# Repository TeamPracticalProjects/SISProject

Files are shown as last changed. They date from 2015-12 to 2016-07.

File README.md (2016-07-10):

# SISOverview
SIS stands for "Standalone Intelligent Sensor" system. The documents in this repository provide everything you need to make and deploy your own SIS. You'll find concept documents, a FAQ, the firmware for your Arduino-like particle.io processor, printed circuit board files, parts lists, links to sources for all the parts, detailed assembly instructions, source code to a control web page, and a complete users guide. At Team Practical Projects we always make a complete project! And we know this repo is complete because, unknown to us, someone in Europe made one!

We are looking for people who are interested in building and using the SIS.  We are also interested in ideas for expanding the current SIS with additional useful features and we are open to  ideas for additional applications of the base SIS technology (some ideas are in the Concept document). SIS is an open source project and we are interested in improvements that other developers might wish makethemselves and/or to collaborate with us on.

If you want to use this project, download the Master branch. That is the currently released and well tested code.

If you have code to contribute, then generate a pull request for the Development branch. We don't want to take in pulls for master branch unless it is some critical issue with the current release.

We are two hobbyists who work on the SIS in our spare time. You don't have to be a hardcore, gung-ho, work on it until you drop, kind of person; we certainly aren't. Collaboration could just mean that you'd like to have one of these to install and test somewhere. We are open to make changes to the code to fit your need, as long as you provide us feedback on how it works and ideas on how to improve it.

We're currently working on three big things:
* Low power custom sensors... This project includes Arduino code to make your own wireless sensor, but running an Arduino requires regular power. We're working on using the ATTiny platform in power-down mode so we (you) could make any kind of low power sensor you want!
* Graphical output in the client... Thanks to a contributor in the Netherlands we are experimenting with the Google graph "Timeline". It provides a strip chart view of the sensor log. This is more usable than the current text list. If you want to help with this, let us know and we'll share that branch.

Of course collaboration could also mean that you want to add functions to the core firmware or javascript web site. That would be cool too.

The documentation is the best place to learn about the project. We starting a [Wiki](https://github.com/TeamPracticalProjects/SISProject/wiki/Wiki-Home) with little tips for new developers.

Send us a message to join in the fun: SISProject@shrimpware.com

Read about the SIS at other places on the web:
* [Hackster.io](https://www.hackster.io/PracticalProjects/standalone-intelligent-sensor-system-cbdb44)
* [Instructables](http://www.instructables.com/id/Standalone-Intelligent-Sensor-System/)

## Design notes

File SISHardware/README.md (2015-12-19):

# SISHardware
This repository contains the Eagle files for the SIS Hub printed circuit board.
The files are provided in Eagle format (.sch and .pcb formats) as well as in pdf format
for those who do not have Eagle.

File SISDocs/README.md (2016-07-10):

# SISDocs
Documentation for the SIS Project.

This repository contains the manuals that describe:
- how to build the SIS Hub
- how to install the Firmware on the SIS Hub
- how to plan an SIS installation and how to actually perform the instalation process.
- how to use the SIS to monitor the activities of a person living alone using the web-based SIS Client app

Please note the document "Optimum Sensor Reception". This documents what we currently know about getting the best reception possible.

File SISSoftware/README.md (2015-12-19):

# SISSoftware.
This repository holds the firmware for the SIS Hub, the javascript based website that is the SIS Client app,
and the Arduino code to make an SIS compatible sensor.

If you want to use this project, download the Master branch. That is the currently released and well tested code.

If you have code to contribute, then generate a pull request for the Development branch.

The project documentation is in the SISProject/SISDocs repository.

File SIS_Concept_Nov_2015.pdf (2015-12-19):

# Standalone Intelligent Sensor (SIS)

## Concept Document

© Bob Glicksman and Jim Schrempp, revised November 2015
1. Product Concept.

The Standalone Intelligent Sensor (SIS) is an inexpensive system that processes information from a variety of passive wireless sensors to create a timestamped log containing meaningful information and inferences about a person’s in-home activities. The SIS log can be securely accessed over the Internet, providing caregivers and concerned relatives a picture of how competently an elderly person living alone is performing the routine activities of daily life.

The initial release of SIS uses wireless proximity infrared (PIR) motion sensors and wireless door separation sensors to log movements of a person around and in/out of their home. Judicious placement of the PIR sensors provides a compact picture of a person’s activities via the natural association of those activities with areas of the home; e.g. bedroom for sleeping and dressing, bathroom for personal hygiene, kitchen for food preparation and living room for relaxation and socialization.

The SIS consists of a number (up to 20) of inexpensive wireless sensors and a small hub device containing wireless receivers, an advanced microcontroller, and WiFi connectivity. The current release of SIS requires WiFi for connection to the Internet; however, a 3G wireless version is anticipated in the near future. SIS also contains client software that can communicate with the in-home hub over the Internet, via a free cloud service from particle.io. The client software is written in Javascript and can be hosted on any device that supports a Javascript enabled web browser (desktop, laptop, tablet, smart phone, etc.). Communication between the SIS hub, the cloud and a client is authenticated and encrypted to ensure privacy and security of the data.

SIS achieves low cost by performing all sensor data processing internally on the SIS hub’s advanced 32 bit microcontroller. Cloud processing of the sensor data is not required. A free cloud service is used to connect the SIS hub and authenticated clients via the Internet. An SIS hub can be built for around $50 in parts and the sensors cost between $3 (for a door separation sensor) and $8 (for a PIR sensor). Total system cost (assuming an existing WiFi access point in the home) will be between $100 and $200, depending upon the number and types of sensors required for a particular home environment. There are no monthly recurring charges, other than an assumed existing WiFi capability.

SIS supports a variety of low cost sensors that can be obtained from many sources including over the Internet from EBay and Amazon. SIS supports both wireless sensors operating at both 315 MHz and 433.92 MHz within the one system. Sensors are available to sense:
- Door/window opening.
- Motion (via PIR).

- Vibration.
- Water level.
- Smoke/fire
- Keyfob
- Arduino software has also been developed to transmit compatible sensor trip codes so that specialized sensors may easily be developed.

SIS is released under an “open source, non-commercial” license. The software, hardware designs, parts lists, instructions and manuals are provided free of charge to non-commercial users. SIS is not a product; the user must use the information provided to construct, install, configure, and test the SIS for their specific environment.

The software for the initial release of SIS will provide a reasonable picture of the daily in-home activities of a person that lives alone. It attempts to sense when more than one person is in the home and lock out logging of activities to prevent false positives. The data processing internal to SIS does not attempt to establish and report “normal” vs. “abnormal” activities of a person in the home. Rather, SIS logs compact information about a person’s movements around the home and leaves it up to the caregiver or relative to determine if the person’s activity patterns have changed. This, coupled with low hardware cost, is what makes SIS an inexpensive solution vis-a-vis more complex and expensive systems.

SIS draws only a few inferences from sensor data; specifically:
- When a person is home or not home.
- When a person is home but not moving at all.
- When multiple people are in the home.

Because all of the SIS design information is open source, SIS firmware and client software may be modified to address other applications in the future. The SIS may be thought of a general purpose platform for interfacing low cost wireless sensors with clients over the Internet.
2. Use Cases.

The initial release of SIS provides general information about the movement of a person inside of the home. Field testing has demonstrated that a limited number of types of sensors can provide a remote client user with sufficient information to determine when and what activities of daily living the person in the home being monitored is performing. A daily review of the logged data is sufficient to detect abnormal patterns; e.g. a person is not leaving the bedroom in the morning or a person is visiting the bathroom several times during the night. More advanced (and more expensive) in-home activity monitoring systems seek to answer additional questions, some of which are posited below. It should be possible to answer these questions with SIS by integrating additional sensors and developing special firmware to make inferences from the sensor data.

2.1. Aging In Place Use Cases.
2.1.1. “I am concerned that Grandpa is not eating.”

A caregiver or loved one is concerned that an elderly person is not eating regularly and needs to be moved to a facility where their dietary needs are met and monitored. The elderly person is pushing back, claiming that they are eating and are perfectly capable of living at home and of caring for themselves. A compromise position has the elderly person agreeing to SIS monitoring of their kitchen activities via proximity sensing and sensing of one or more food related activities:
- opening and closing the refrigerator door.
- running a microwave or toaster oven.
- running of the stovetop and/or oven.
- opening/closing silverware draw or flatware cabinet.
- running of the dishwasher.

The initial release of SIS logs movement into and out of the kitchen. It also supports the logging of data from separation sensors and specialized sensors; however, it does not draw inferences from these additional sensors. Being open source, SIS firmware can have additional inferences added to better support this use case.

2.1.2. “I called Mom when she should be home but the phone is not answered.”

The question here, of course, is whether Mom is in the house and unable to answer the phone (due to fall, stroke, or other serious problem) or whether she is just fine and decided to go out of the house or apartment, perhaps for socialization activities. The concern could be mitigated if the state of “in the house” and “out of the house” could be known. Without relying on the person wearing a certain commercial fob with Near Field Communication capabilities, the activities of “leaving the house” and “entering the house” could be timestamped, logged and accessed via the Internet. SIS can provide such information, particularly if the person lives alone. The initial release of SIS supports this use case, and more. An enhancement, however, might be to support user configuration of normal “out of the house” times and send the user an alert if the elderly person leaves the home at an unexpected time (which might be an indication of illness or wandering).

2.1.3. “Last year Dad had a urinary tract infection but did not tell anyone about it. Ultimately, he had to be hospitalized”.

There were indications of this infection, of course, but Dad ignored them. He woke up ten times that night to go to the toilet. However, he didn’t think anything of this and didn’t tell anyone about it. Now, family has confronted Dad with this problem, suggesting that it is an indication that he can no longer live alone at home. Dad denies this and, although prone to these infections, insists that he “knows better now” and promises to tell family the “next time”. Family members remain concerned and believe that the problem will recur, perhaps this time resulting in his death due to lack of timely treatment.

The initial release of SIS will support this use case by logging movement between the bedroom and bathroom. The initial release of SIS can also log trips of a water level sensor that is mounted inside the toilet tank that positively indicates when the toilet is flushed.

2.1.4. “I am concerned that Mom is staying in bed all day with the lights off and the drapes drawn. She denies the depression.”

The initial release of SIS will log movement into and out of the bedroom. Review of the log can determine if Mom is not getting out of bed (at all, or not when expected). Additional sensors and algorithms may be developed to add important information; e.g. is Mom in bed or moving about the bedroom? Is the bedroom lit or dark? Is the TV on or off? Etc. It may be possible to develop algorithms for SIS that use this additional sensor information to sense that Mom is having symptoms of depression and to send an alert to the caregiver or relative accordingly.

2.1.5. “Beloved Aunt Millie has emphysema and is not allowed to smoke. She lives alone and her loved ones are concerned that she continues to smoke and is likely to die if her smoking is not monitored.”

SIS can be fitted with a smoke detector sensor and will log instances of smoke detection along with movement around the house. An enhancement would be to proactively alert a family member if the sensor is triggered.

### 2.1.6. Uncle John has left the freezer door open several times. The

food has spoiled and then refrozen. This is a health danger.

An SIS-compatible temperature sensor may be developed to detect, log and alert a remote user in the event that the temperature inside the refrigerator gets too high, indicating that the food may spoil if the situation is not corrected promptly.

2.2. Home Monitoring Use Cases.
2.2.1. “I am getting forgetful and prone to leave the water running in the sink.”

SIS could use a compatible water level sensor to log instances of the sink filling up. A firmware enhancement to SIS could send an alert to a caregiver or family member in this event. A hardware and firmware enhancement could shut off the water supply before folding occurs, and or set off an audible alarm to the resident. An SIS compatible sensor could be developed to sense water flow. This sensor could be used, in conjunction with SIS’s current capability to determine where a person is in the home, to log instances where the water is running but the person has left the kitchen or bathroom. A firmware enhancement to SIS could send an alert to a family member or caregiver, in addition to logging these instances of forgetfulness.

2.2.2. “Rainwater collects under my house. I have an automatic sump pump to pump the water out, but the pump sometimes fails and I am concerned about the foundation being flooded in a rainstorm.”

An SIS compatible water level sensor and/or a moisture sensor could be used to determine if water is building up under the house. If it is, then the sump pump is not operating properly and the user can be alerted through the SIS Hub.

2.3. Other Use Cases.
2.3.1. “I have a greenhouse in which I grow valuable plants. I need to know when the temperature or humidity gets out of a predetermined range so that I can intervene to save the plants from dying.”
Assuming that the greenhouse has AC power or is within 100 feet of a location where the SIS Hub can be installed, an SIS can be fitted with a temperature/humidity sensor and be programmed to log temperature and humidity and to alert the user whenever either measurement goes out of prespecified limits.
3. SIS Technical Description.

A complete technical description of SIS can be found in the “SIS Theory of Operation and Installation Manual”, which can be found at:

https://github.com/SISProject/SISDocs/blob/master/SIS_Theory_of_Operation_and_Installation. pdf (https://github.com/SISProject/SISDocs/blob/master/SIS_Theory_of_Operation_and_Installation.pdf)

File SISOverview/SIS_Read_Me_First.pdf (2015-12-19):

# Standalone Intelligent Sensor (SIS)

## Project and Document Overview

## Read Me First!

© Bob Glicksman and Jim Schrempp, December 2015

## 1. What’s This All About?

The Standalone Intelligent Sensor (SIS) is an inexpensive build-it-yourself system that processes information from a variety of passive wireless sensors to create a timestamped log containing meaningful information and inferences about a person’s in-home activities. The SIS log can be securely accessed over the Internet, providing caregivers and concerned relatives a picture of how competently an elderly person living alone is performing the routine activities of daily life.

The initial release of SIS uses wireless proximity infrared (PIR) motion sensors and wireless door separation sensors to log movements of a person around and in/out of their home. Judicious placement of the PIR sensors provides a compact picture of a person’s activities via the natural association of those activities with areas of the home; e.g. bedroom for sleeping and dressing, bathroom for personal hygiene, kitchen for food preparation and living room for relaxation and socialization.

The SIS consists of up to 20 inexpensive wireless sensors and a small hub device containing wireless receivers, an advanced microcontroller, and WiFi connectivity. The current release of SIS requires WiFi for connection to the Internet; however, a 3G wireless version is anticipated in the near future. SIS also contains client software that can communicate with the in-home hub over the Internet, via a free cloud service from particle.io. The client software is written in Javascript and can be hosted on any device that supports a Javascript enabled web browser (desktop, laptop, tablet, smart phone, etc.). Communication between the SIS Hub, the cloud and a client is authenticated and encrypted to ensure privacy and security of the data.

SIS achieves low cost by performing all sensor data processing internally on the SIS Hub’s advanced 32 bit microcontroller. Cloud processing of the sensor data is not required. A free cloud service is used to connect the SIS Hub and authenticate clients via the Internet. An SIS Hub can be built for around $50 in parts and the sensors cost between $3 (for a door separation sensor) and $8 (for a PIR sensor). Total system cost (assuming an existing WiFi access point in the home) will be between $100 and $200, depending upon the number and types of sensors required for a particular home environment. There are no monthly recurring charges, other than an assumed existing WiFi capability.

SIS is not a product; the user must use the information provided to construct, install, configure, and test the SIS for their specific environment.

2. Open Source.

SIS is released under an “open source, non-commercial” license (Creative Commons). The software, hardware designs, parts lists, instructions and manuals are provided free of charge to non-commercial users. We encourage people to use the SIS as it is documented herein and to provide us with feedback about your results, difficulties and ideas for improvement. As an open source project, we encourage people to make changes and improvements to the SIS design, subject to the “Terms_Of_Use_License_and_ Disclaimer” document:

https://github.com/SISProject/SISDocs/blob/master/Terms_of_Use_License_and_Disclaimer.pdf

We are also open to people using SIS technology in a commercial business. If you are interested in this, please contact us to discuss the terms of an appropriate commercial license:

SISProject@shrimpware.com

3. Documentation Tree.

We have attempted to provide users with a complete set of documentation that describes what SIS is, how to build your own SIS, how to plan and install and SIS, and how to use the SIS Client app to manage and query an SIS. Since SIS is an open source project, we have also provided complete source code and hardware (Eagle) files. Users may use this documentation as the starting point for making modifications to and improvements on the SIS technology that we have provided.

All SIS documentation and files are released on GitHub, under:

https://github.com/SISProject

The figure below is the documentation tree for all of the files in the SIS release. All documents (other than source code and Eagle CAD files) are in .pdf format.

We have arranged the SIS documentation into 4 repositories under the SIS project:

- SIS Overview: this repository contains documents that provide the reader with an overview of the SIS project. This document is located in this repository, as is a Concept document and a Frequently Asked Questions (FAQ) document. These documents are intended to help an interest user make a determination about building and installing an SIS to meet their individual needs.
- SIS Software: this repository contains the source code for all of the SIS software. The “website” subdirectory contains files for the SIS Client app, which is a Javascript enabled website. The “Firmware” repository contains the source code for the SIS Hub, which receives, decodes and processes data from all SIS sensors. The “Arduino Transmitter Software” repository contains Arduino source code for making an SIS compatible transmitter using an Arduino Uno and a cheap 315MHz or 433MHz transmitter module. Users can use this software to design their own, SIS compatible, wireless sensors¹

1
The Arduino Transmitter software does not contain code for low power, battery operation of an Arduino.

- SIS Hardware: this repository contains the Eagle CAD files for the SIS Hub printed circuit board (.sch and .brd files). .pdf versions of these files are also provided for those users who wish to view this design information but do have the Eagle CAD software.
- SIS Docs: this repository contains all of the documents necessary to purchase parts, assemble, install, and use an SIS for the intended application of monitoring the activities of a person living alone.

Note that any and all use of this documentation is subject to the “Terms of use, License and Disclaimer” document that you can find in the SIS Docs repository.

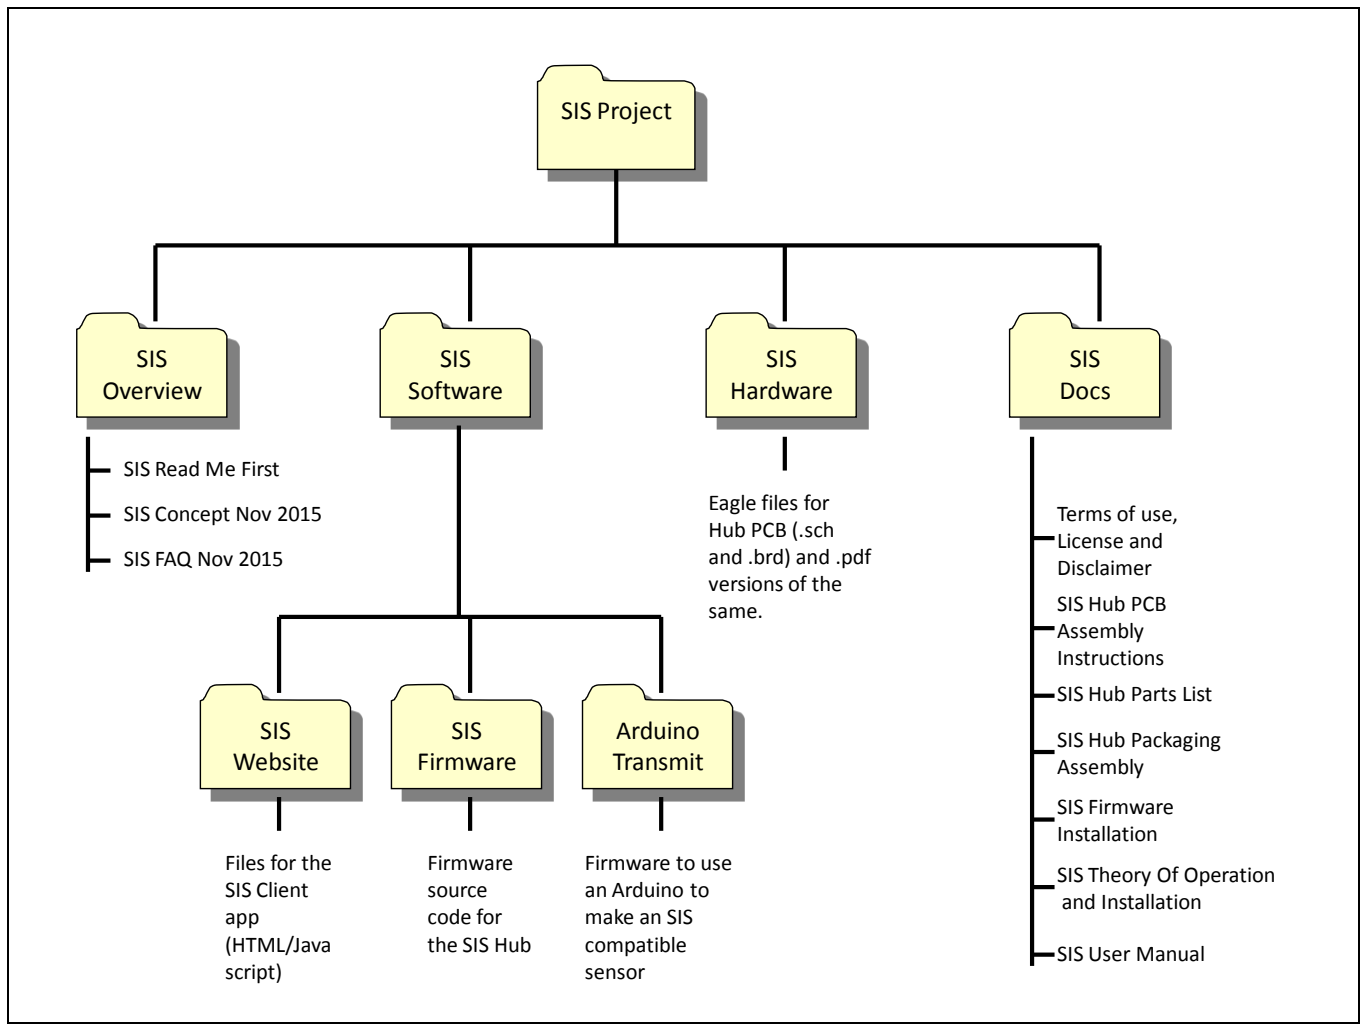
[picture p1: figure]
SIS Project; SIS Overview; SIS Software; SIS Hardware; SIS Docs; SIS Website; SIS Firmware; Arduino Transmit; Files for the SIS Client app (HTML/Java script); Firmware source code for the SIS Hub; Firmware to use an Arduino to make an SIS compatible sensor; Eagle files for Hub PCB (.sch and .brd) and .pdf versions of the same.; SIS Read Me First; SIS Concept Nov 2015; SIS FAQ Nov 2015; SIS Theory Of Operation and Installation; SIS Hub PCB Assembly Instructions; SIS Hub Parts List; SIS Hub Packaging Assembly; SIS Firmware Installation; SIS User Manual; Terms of use, License and Disclaimer

SIS Documentation Tree.

You can access and view all of these documents directly on the website:

https://github.com/SISProject

You can also click on whichever of the repositories you are interested in and click the
“Download ZIP” button on GitHub to download a zip archive of all of the files in that repository to your computer.
4. Further Information.

Complete information about SIS can be found in:

https://github.com/SISProject

We have tried to document SIS well enough for a novice, non-technical user to be able to build, install and use the SIS for their own purposes. We are not a commercial organization and we cannot commit to providing individual technical support. However, we are interested in people using and even improving SIS and we welcome you to ask questions, provide us with feedback, or suggest improvements via e-mail at:

SISProject@shrimpware.com

We hope that you enjoy SIS.

Sincerely,

Jim Schrempp and Bob Glicksman, developers of SIS

December 2015

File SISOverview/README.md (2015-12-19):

# SISOverview.
This repository contains overview documents that describe the SIS project.  SIS stands for 
"Standalone Intelligent Sensor" system. The documents in this repository explain the SIS concept 
and provide the answers to Frequently Asked Questions (FAQ).

We are looking for people who are interested in building and using the SIS as we have designed it.  We are
also interested in ideas for expanding the current SIS with additional useful features and we are open to 
ideas for additional applications of the base SIS technology (some ideas are in the Concept document). 
SIS is an open source project and we are interested in improvements that other developers might wish make 
themselves and/or to collaborate with us on.

We are two hobbyists who work on the SIS in our spare time. You don't have to be a hardcore, gung-ho, work 
on it until you drop, kind of person; we certainly aren't. Collaboration could just mean that you'd like 
to have one of these to install and test somewhere. We are open to make changes to the code to fit your need, 
as long as you provide us feedback on how it works and ideas on how to improve it.

Of course collaboration could also mean that you want to add functions to the core firmware or javascript web site. 
That would be cool too.

Send us a message to join in the fun: SISProject@shrimpware.com

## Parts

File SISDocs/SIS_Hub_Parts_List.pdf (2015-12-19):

REQUIRED PARTS FOR PCB ASSEMBLY
Item # | Qty | Vendor | Vendor Part # | Description | Link | Notes
1 | 1 OSHPark | SIS Hub PCB | SIS Hub Printed Circuit Board | https://oshpark.com/shared_projects/ptHf88wY Custom PCB - order from OSHPark or use the Eagle files to order
from another vendor.
2 | 1 Particle | Photon | Particle Photon WiFi
| | | | Microcontroller with
| | | | breadboard headers | https://store.particle.io/?product=particle-
photon (https://store.particle.io/?product=particle-photon)
| | | | | | The Particle Electron may be supported in the future. The PC board
| | | | | | has extension mounting holes to accommodate the larger Electron.
3 | 1 Jameco | AT24C256PC | 24C256; 32 KB I2C EEPROM | http://www.jameco.com/webapp/wcs/stores/ser
| | | | | vlet/Product_10001_10001_200580_-1 (http://www.jameco.com/webapp/wcs/stores/servlet/Product_10001_10001_200580_-1)
4 | 1 E-Bay | NA | 315 MHz OOK Receiver | http://www.ebay.com/itm/315MHz-433MHz-
| | | | | Wireless-Super-Heterodyne-Remote-RX-Receiver-
Module-107dBm-
| | | | | /181711941472?var=&hash=item2a4ee02f60 (http://www.ebay.com/itm/315MHz-433MHz-Wireless-Super-Heterodyne-Remote-RX-Receiver-Module-107dBm-/181711941472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) | Select 315 Mhz from dropdown list. The same part is available from
| | | | | | many Asian vendors on E-Bay and Amazon.
5 | 1 E-Bay | NA | 433 MHz OOK Receiver | http://www.ebay.com/itm/315MHz-433MHz- Wireless-Super-Heterodyne-Remote-RX-Receiver- Module-107dBm- /181711941472?var=&hash=item2a4ee02f60 (http://www.ebay.com/itm/315MHz-433MHz-Wireless-Super-Heterodyne-Remote-RX-Receiver-Module-107dBm-/181711941472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)

Select 433 MHz from dropdown list. The same part is available from many Asian vendors on E-Bay and Amazon.

6 | 10 Jameco | CF1/4W472JRC (http://www.jameco.com/webapp/wcs/stores/servlet/Product_10001_10001_691024_-1) | resistor - 4.7Kohm, 1/4 watt axial lead (minimum qty = 10)

http://www.jameco.com/webapp/wcs/stores/servlet/Product_10001_10001_691024_-1 (http://www.jameco.com/webapp/wcs/stores/servlet/Product_10001_10001_691024_-1)

Need 2 resistors

7 | 10 Jameco | SR205E104MAA-VP (http://www.jameco.com/webapp/wcs/stores/servlet/Product_10001_10001_544868_-1) | 0.1 uf Capacitor, 50 volt
| | | (minimum qty = 10) | http://www.jameco.com/webapp/wcs/stores/ser
| | | | vlet/Product_10001_10001_544868_-1 (http://www.jameco.com/webapp/wcs/stores/servlet/Product_10001_10001_544868_-1)

need 2 capacitors

8 | 10 Jameco | 100UF/16V 6X5 | 100 uF Capacitor, electrolytic | http://www.jameco.com/webapp/wcs/stores/ser
| | | | vlet/Product_10001_10001_94289_-1 (http://www.jameco.com/webapp/wcs/stores/servlet/Product_10001_10001_94289_-1)

need 1 capacitor

9 | 1 Jameco | USB-B-S-RA-WT | USB connector, B female | http://www.jameco.com/webapp/wcs/stores/ser
| | | | vlet/Product_10001_10001_230958_-1 (http://www.jameco.com/webapp/wcs/stores/servlet/Product_10001_10001_230958_-1)
10 | 1 Adafruit | 907 | Panel Mount USB cable, B male
| | | to B female | http://www.adafruit.com/products/907
11 | 1 Adafruit | 266 | 40 conductor female-female
| | | jumper wires, separable.
http://www.adafruit.com/products/266 | Required only if the receivers are not mounted to the PC board.
These jumers are used to connect pin headers soldered to the board in the receiver positions to the pins on the remotely mounted receivers.
12 | 1 Jameco | 7000-1X40SG-R (http://www.jameco.com/webapp/wcs/stores/servlet/Product_10001_10001_160882_-1) | Breakaway headers, straight,
| | | male | http://www.jameco.com/webapp/wcs/stores/ser
| | | | vlet/Product_10001_10001_160882_-1 (http://www.jameco.com/webapp/wcs/stores/servlet/Product_10001_10001_160882_-1)

Required only if the receivers are mounted remotely from the PC board. May also be used for POWER and EXPANSION connections to the PC board.
13 | 2 Digi-Key | S7016-ND (http://www.jameco.com/webapp/wcs/stores/servlet/Product_10001_10001_175920_-1) | 18 Pin female header | http://www.digikey.com/product-
| | | | search/en?keywords=S7016-ND (http://www.digikey.com/product-search/en?keywords=S7016-ND)

18 Pin headers will accommodate both Photon and Electron. 12 pin female headers may be used if only Photon support is needed.

14 | 1 Jameco | 6100-8-R | 8 pin DIP socket | http://www.jameco.com/webapp/wcs/stores/ser
| | | | vlet/Product_10001_10001_51626_-1 (http://www.jameco.com/webapp/wcs/stores/servlet/Product_10001_10001_51626_-1)

Alternative is to solder the Photon directly to the PC board, or to use 0.1" spaced female pin headers.

| | | | OPTIONAL PARTS FOR BOX MOUNTING AND
| | | | POWERING
1 | 1 Staples or on-
| line from Really
| Useful Boxes | in-store only | enclosure; 0.55 liter (1-7/16"H
| | | x 4"W x 8-1/2"L) | http://www.reallyusefulproducts.co.uk/usa/html/
| | | | onlineshop/rub/b00_55litre.php (http://www.reallyusefulproducts.co.uk/usa/html/onlineshop/rub/b00_55litre.php)

A smaller enclosure may be used if receivers are mounted to PC Bord directly vs taped to the sides of the enclosure. However, range of reception may sugger if the receivers are not at least 4" apart (and apart from the Photon WiFi chip). Boxes are available is various colors.
2 | 4 jameco | 2104-632-AL-7 (https://www.jameco.com/webapp/wcs/stores/servlet/Product_10001_10001_77543_-1) | standoff, female-female, 1/2",
| | | 6-32 threaded | https://www.jameco.com/webapp/wcs/stores/se
| | | | rvlet/ProductDisplay?storeId=10001&langId=-
| | | | 1&catalogId=10001&pa=77543&productId=7754
| | | | 3 (https://www.jameco.com/webapp/wcs/stores/servlet/ProductDisplay?productId=77543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)

Use as required to mount PC board into the enclosure. Board will accommodate 4 standoffs. See below for Nylon standoffs if desired.

3 | 10 jameco | H554-ND | Screw, 6-32x1/4", pan head, phillips
https://www.jameco.com/webapp/wcs/stores/servlet/ProductDisplay?productId=20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 94418 (https://www.jameco.com/webapp/wcs/stores/servlet/ProductDisplay?productId=2094418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)

Use as required to mount PC board into the enclosure. Board will accommodate 4 screws (board to standoff) + 4 screws (standoff to enclosure). See below for Nylon screws, if desired.

4 | 4 Digi-Key | 36-1903C-ND | standoff, female-female, 1/2", 6-32 threaded
http://www.digikey.com/productsearch/en?KeyWords=36-1903C-ND&WT.z_header=search_go

Nylon alternative to metals standoffs, if desired.

5 | 100 Digi-Key | H554-ND | Screw, 6-32x1/4", pan head, phillips
http://www.digikey.com/productsearch/en/hardware-fasteners-accessories/screwsbolts/2097339?k=H554-ND

Nylon alternative to metal screws, if desired. Minimum order is 100 screws (need 8).

6 | 10 Jameco | 0505HC-101S-R (http://www.jameco.com/webapp/wcs/stores/servlet/Product_10001_10001_182942_-1) | Cable tie mount, nylon, 3/4" (minimum qty = 10) | http://www.jameco.com/webapp/wcs/stores/ser vlet/Product_10001_10001_182942_-1 (http://www.jameco.com/webapp/wcs/stores/servlet/Product_10001_10001_182942_-1)

Use as required for neatness. Should only require 4 or so tie mounts

7 | 100 Jameco | CV-075-R (http://www.jameco.com/webapp/wcs/stores/servlet/Product_10001_10001_70561_-1) | Cable tie, nylon, 3" (minimum qty = 100) | http://www.jameco.com/webapp/wcs/stores/ser vlet/Product_10001_10001_70561_-1 (http://www.jameco.com/webapp/wcs/stores/servlet/Product_10001_10001_70561_-1)

Use as required for neatness. Should only require 4 or so ties

8 | 1 Office max | 912408 | Scotch Outdoor Mounting Tape
- Double Sided (one roll)
| | | | http://www.officedepot.com/a/products/745021 /Scotch-Permanent-Heavy-Duty-Outdoor- Mounting/ (http://www.officedepot.com/a/products/745021/Scotch-Permanent-Heavy-Duty-Outdoor-Mounting/)

Use as required to affix receiver modules to the enclosure. Not required if receivers are mounted on the PC Board.

9 | 1 Jameco | 10U2-02206-BK | USB Cable; A male to B male. | http://www.jameco.com/webapp/wcs/stores/ser vlet/Product_10001_10001_222010_-1 (http://www.jameco.com/webapp/wcs/stores/servlet/Product_10001_10001_222010_-1)

Optional - needed to bring power to the SIS Hub

10 | 1 Jameco | GS05U-USB | USB Power supply; 1Amp | http://www.jameco.com/webapp/wcs/stores/ser vlet/Product_10001_10001_2155823_-1 (http://www.jameco.com/webapp/wcs/stores/servlet/Product_10001_10001_2155823_-1)

Optional - needed to bring power to the SIS Hub. Any USB power supply, 5 volts at 500 ma or more will work, as will USB power from

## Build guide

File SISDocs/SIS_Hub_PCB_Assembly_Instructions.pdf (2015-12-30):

Page 1 of 13 | Copyright © 2015. Bob Glicksman and Jim Schrempp. All rights reserved.

## INSTRUCTIONS

## For Assembly of the SIS Hub Printed Circuit Board (PCB)

Bob Glicksman, Jim Schrempp Date: 12/30/2015

1) INTRODUCTION.

The SIS hub contains a printed circuit board (PCB) that must be assembled before the Hub can be powered and used. This assembly will take about one hour. The parts list for the printed circuit board can be found in Appendix A of this document and at:

https://github.com/TeamPracticalProjects/SISProject/blob/master/SISDocs/SIS_Hub_Parts_L ist.pdf (https://github.com/TeamPracticalProjects/SISProject/blob/master/SISDocs/SIS_Hub_Parts_List.pdf)

The SIS Hub is based on the Particle “Photon” module (see: https://www.particle.io/). The SIS Hub printed circuit board has been designed to accept the Particle “Electron” as well¹
The parts in the section of the Parts List labeled “Required Parts for PCB Assembly” must be purchased and available before the board can be assembled per these instructions. The parts in the section of the Parts List labeled “Optional Parts for Box Mounting and Powering” are not covered in these instructions. A separate instruction is provided for the recommended (but not mandatory) assembly of the completed PCB into a rugged plastic enclosure. See:

https://github.com/TeamPracticalProjects/SISProject/blob/master/SISDocs/SIS_Hub_Packaging_Assembly_Instructions.pdf (https://github.com/TeamPracticalProjects/SISProject/blob/master/SISDocs/SIS_Hub_Packaging_Assembly_Instructions.pdf)

2) TOOLS AND SUPPLIES.

Before beginning assembly of the shield board, the following tools and supplies should be at hand:

1 The Electron is not available at the time of this publication. The PCB design is based on preliminary specifications from Particle and has not been tested with an Electron. The PCB will also accept a Particle “Core” module; however, the SIS firmware no longer supports the Core.

NOTICE: Use of this document is subject to the terms of use described in the

document “Terms_of_Use_License_and_Disclaimer” that is included in this release package. This document can also be found at:

https://github.com/TeamPracticalProjects/SISProject/blob/master/SISDocs/Terms_of_Use_License_and_Disclaimer.pdf (https://github.com/TeamPracticalProjects/SISProject/blob/master/SISDocs/Terms_of_Use_License_and_Disclaimer.pdf)

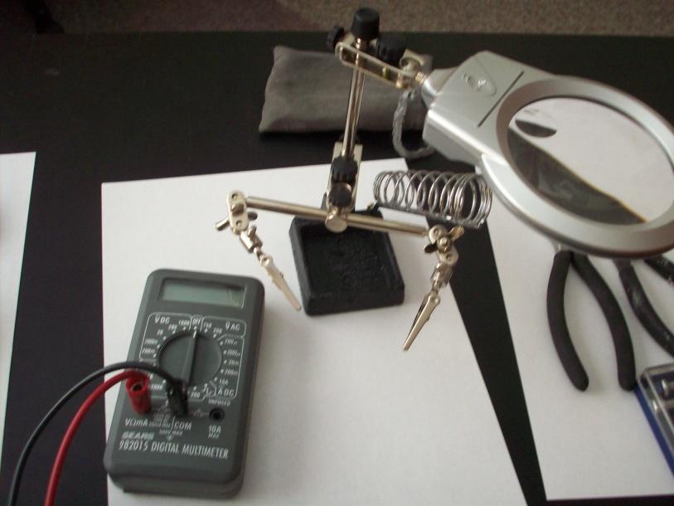
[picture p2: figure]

Page 2 of 13 | Copyright © 2015. Bob Glicksman and
a) Tools:
i) Soldering Iron
ii) Needle Nose Pliers
iii) Diagonal Cutter
iv) Wire stripper
v) Philips head screwdriver
b) Supplies:
i) Electrical solder
ii) Electrical tape
iii) Solder wick or solder remover iv) SIS hub parts kit (see parts list)
c) Optional (see photo 1, below):
i) Soldering iron stand
ii) PC board adjustable soldering stand iii) Magnifier
iv) Multi-meter

Photo 1. PC Board Adjustable Soldering Stand and Multimeter.

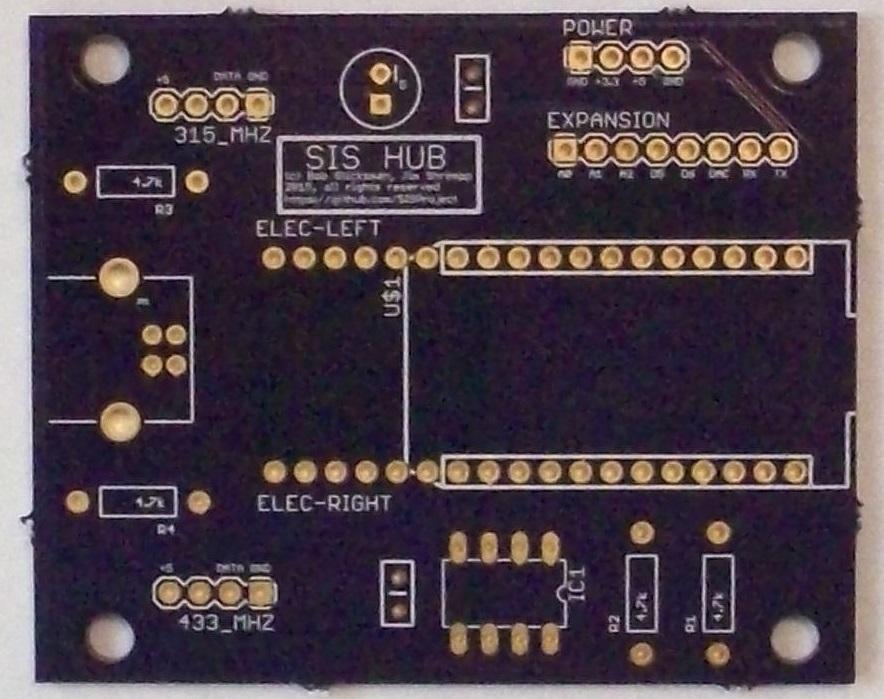
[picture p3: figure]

Page 3 of 13 | Copyright © 2015. Bob Glicksman and
3) ASSEMBLY INSTRUCTIONS.
a) Soldering. Assembly of the SIS Hub PCB requires that you have knowledge of skill of electronic soldering. A good tutorial on this subject can be found at:

https://learn.sparkfun.com/tutorials/how-to-solder---through-hole-soldering

b) General instructions: Before beginning assembly, please read through and understand these general instructions:
i) All parts are mounted on the top side of the board. The top side of the board is the side with the silk screen printing on it – see photos 2 and 3, below.

Photo 2. Top Side of Blank SIS Hub PCB. Note that the “front side” is to the right.

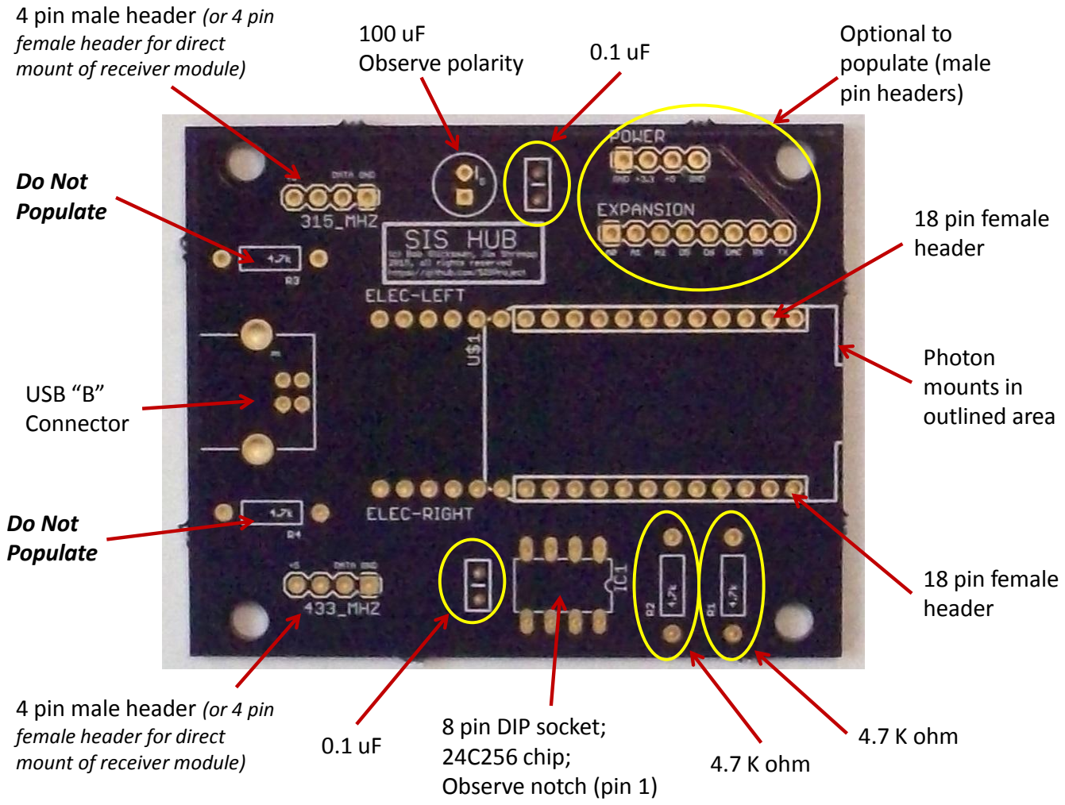
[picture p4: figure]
Optional to populate (male pin headers); 100 uF Observe polarity; 18 pin female header; Photon mounts in outlined area; 4.7 K ohm; 8 pin DIP socket; 24C256 chip; Observe notch (pin 1); Do Not Populate; USB “B” Connector; 4 pin male header (or 4 pin female header for direct mount of receiver module)

Page 4 of 13 | Copyright © 2015. Bob Glicksman and

Photo 3. SIS Hub PCB with major parts identified.

ii) All parts are soldered on the bottom side of the board only.

iii) The following parts have rigid pins and do not grip the board to hold the part in place when the board is inverted to solder the pins on the bottom. It is recommended to place the part on the top of the board, align the part as necessary, and apply electrical tape to hold the part in place for soldering. As soon as the board is inverted for soldering on the bottom side, solder the two pins at opposite ends (diagonally, in the case of the DIP socket) first to hold the part rigidly. Then solder the remaining pins to the board.

(1) 4 pin male headers. Care must be taken to keep these parts in vertical alignment as they tend to tilt sideways because they are loose in the holes in the board. Place these parts into the holes so that the short pin ends protrude through to the bottom of the PC board. Align each connector vertically and use electrical tape to

Page 5 of 13 | Copyright © 2015. Bob Glicksman and

hold it firmly into the holes, with the plastic center pieces firmly seated into the top side of the PC board and the connector straight up and down and not slanted sideways.

(2) Female headers for Photon/Electron Module. The headers require extreme care to ensure that the Photon/Electron module fits properly in the headers after they are soldered to the board. See instructions below for the recommended procedure.
(3) DIP socket. The DIP socket is easier to solder since it has two rows of pins that will prevent it from tilting. However, it should be taped or otherwise affixed to the top side of the PC board so that it stays in place when the board is inverted for soldering.

iv) The USB “B” connector has mounting tabs that are bowed outward to snap into a PC board. Once inserted into the PC board properly, the tabs will hold the connector in place when the board is inverted for soldering. See the assembly instruction details for this step in the SIS Hub PCB assembly for further details.

c) Inspect the blank PC board for damage and deburr edges.
i) File down any burs on the board edges to avoid cuts and scrapes

ii) Visually inspect the board for any damage or defects, such as:

(1) Breaks in conformal coating, except for solder pads and vias.
(2) Ensure that holes are drilled in the center of each component solder pad.

iii) Place a multimeter in resistance measurement mode and check that there is an open circuit between the “+5”, “+3.3” and the two “GND” pads on the “POWER” pads at the top of the board. Refer to photos 2 and 3, above, for details. If there is not an open circuit between any of these contacts on a bare PC board, then the board has a power short and should not be used.

d) Align and solder two 18 pin female headers for the Photon or Electron.
i) NOTE: The PCB has been designed to accept two 18 pin female headers for mounting an Electron. These headers can also be used with the smaller (24 pin) Photon or Core modules. If support for the Electron is not required, smaller 12 pin female headers may be used (but the 18 pin headers will support both the Photon and the Electron modules). If 12 pin headers are used, they must be mounted in the 12 pins closest to the front of the PCB, i.e. within the silkscreen outline shown in photo
3. Follow the same instructions as for 18 pin headers, below.

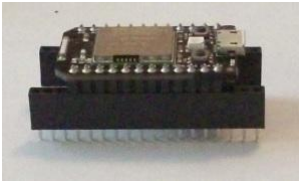
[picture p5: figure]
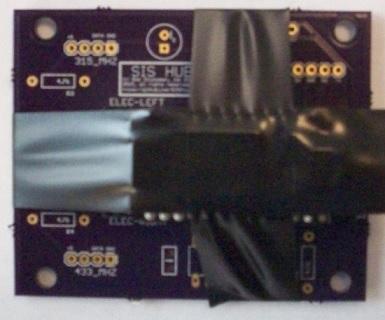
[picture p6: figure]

Page 6 of 13 | Copyright © 2015. Bob Glicksman and

ii) Place a Photon or Electron (or Core) into the 18 pin female headers, as shown in photo 4, below. If using a Photon or Core (24 pin devices), align the device in the middle of the header, as shown in the photo.

Photo 4. Female header alignment using a Photon, Electron or Core.

iii) Place the female headers into the PCB and secure the assembly firmly using electrical tape. See photo 5.

Photo 5. Securing the female headers into the PCB.

iv) Solder the end two pins at each end of each of the female headers, and shown in photo 6, below. Then, remove the electrical tape and unplug the Photon, Electron or Core device from the headers and solder the rest of the female header pins to the

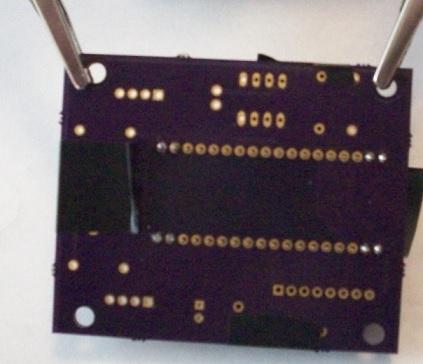
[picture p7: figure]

Page 7 of 13 | Copyright © 2015. Bob Glicksman and

PCB. Carefully inspect the solder joints to make sure that there are no cold joints and no bridging of solder between the pins.

Photo 6. Soldering corner pins to the PCB.

e) Solder 0.1” male pin headers to the PCB.
i) NOTE: the SIS hub PCB accepts two, 4 pin male headers for cabling the RF receiver modules to the PCB. Alternatively, 4 pin female headers may be soldered to the PCB and the receiver modules may be plugged directly into the board via these female headers. This eliminates the need to mount the RF receiver modules externally from the PCB, however testing has shown that receiver range may be degraded if the RF receiver modules are mounted closer than 4” from each other and from the chip antenna on the Photon module.

ii) Break off two, 4 pin segments from a long, 0.1” spaced male pin header.

iii) Place one 4 pin male header into the holes on the PCB marked “433 MHz”. The long pins and plastic body go on the top of the PCB.

iv) Use electrical tape to secure the 4 pin header to the PCB. Make sure that the header pins are vertical.

v) Invert the board and solder the two end pins to the PCB, taking care not to move the header connector out of the position that it was taped into. Then, solder the two

Page 8 of 13 | Copyright © 2015. Bob Glicksman and

middle pins. Carefully inspect that there are no cold solder joints nor bridged solder joints. Remove the electrical tape.

vi) Repeat this procedure for the “315 MHz” header.

vii)NOTE: There is a set of 4 holes marked “POWER” and 8 holes marked “EXPANSION” at the top of the PCB (photo 3). These are used only for expansion of the I/O capabilities of the PCB. They are normally left unoccupied; however, you may optionally break off male pin headers and solder them to the PCB using the same procedure as above.

f) Solder the USB “B” connector to the PCB.
i) Insert the USB “B” connector into the PCB, with the connector end facing the rear of the board. There are two large holes that mate with tabs on the connector. The connector will snap into the board and the tabs will hold it in place while soldering.

ii) Invert the PCB and solder the tabs and the 4 connector pins to the board. As always, inspect that there are no cold solder joints nor bridged pins.

iii) Put a blob of solder between the tabs and the large holes to give a bit more mechanical strength to the USB connector mounting.

g) Solder the 8 pin DIP socket to the PCB.
i) Insert the DIP socket into the top side of the PCB. Make sure that the notched end of the socket faces the front of the board (side opposite to the USB connector).

ii) Use electrical tape to hold the socket firmly onto the PCB.

iii) Invert the board and solder two opposing corner pins to the PCB, taking care not to move the DIP connector out of the position that it was taped into. Then, solder the remaining pins. Remove the electrical tape and carefully inspect that there are no cold solder joints nor bridged solder joints.

h) Solder the remaining components to the PCB.
i) NOTE: all remaining components have two long leads that can be bent over to hold the component into position when soldering. Bend the leads to insert the component into the top side of the PCB, as needed. Then, bend over the leads on the bottom side of the PCB so that the component stays in place and solder the two ends to the board. Inspect the solder joints. Then, using diagonal cutters, clip of the excess leads from the bottom side of the PCB.

Page 9 of 13 | Copyright © 2015. Bob Glicksman and

ii) NOTE on the 100 uF electrolytic capacitor: This device is polarized. The positive (+) side has the longer lead. The negative (-) side has a silver stripe near it on the capacitor body. The positive (+) side goes into the square hole in the PCB and the negative (-) side goes into the round hole in the PCB (also marked with a “-“ symbol). Make sure to observe correct polarity when soldering the capacitor to the PCB.

iii) The two 0.1 uF capacitors are non-polarized. It does not matter which lead goes into which hole on the board.

iv) Two 4.7Kohn resistors are soldered into the positions labeled “R1” and “R2” on the PCB. These can be found near the front of the board, near the 8 pin DIP.

v) NOTE: there are two more positions marked “R3” and “R4”. These are located near the rear of the PCB, near the 315 MHz and 433 MHz connectors. DO NOT
SOLDER ANYTHING INTO THESE POSITIONS if you plan to use both 433 and 315 MHz receivers. If you plan to use only one receiver, you may solder a 4.7Kohm resistor into the board position adjacent to the receiver module connector that you DON’T plan to use. This pullup resistor will prevent noise on the open connection from triggering the RF receiver decoding software. If you later decide to use the second receiver, you must disconnect the pullup resistor from the board (e.g. clip it off using diagonal cutters). THE RECEIVERS WILL NOT WORK PROPERLY WITH A PULLUP RESISTOR INSERTED.
i) Completed PC Board.
i) See photo 7 for the completely assembled PCB. Plug the Photon or Core into the very front of the female headers on the PCB, as shown in the photo. Plug the 8 pin 24C256 IC into the 8 pin DIP socket with the notch facing the front of the board, as shown in the photo. Inspect the board to make sure that all components have been properly inserted and soldered onto the board.

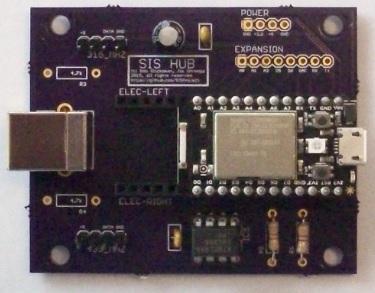
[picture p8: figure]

Page 10 of 13 | Copyright © 2015. Bob Glicksman and

Photo 7. Assembled PCB.

3) ASSEMBLY AND TESTING.

The RF Receivers are connected to the PCB using the two 4 pin male headers. Strip a 4 wire section off of a female-female jumper cable (item 11 on the Parts List) and plug one end into a 4 pin header on the board and the corresponding wires to the pins of the 315 MHz and 433 MHz RF receiver modules. TAKE CAREFUL NOTE to connect the +5, GND and Data pins on the receiver module to the corresponding pins on the PCB, as labeled.

The board is powered using a standard A/B USB cable²

and USB power supply³
(or USB port on
a computer). After connecting the receiver modules and carefully checking the correct wiring, use the USB A/B cable to power the board. The LED on the Photon should light up, as shown in photos 8 and 9, below. The color that the LED lights up, as well as whether it lights solid, flashing or “breathing” will depend upon that status of the WiFi connection and of the firmware loaded to the Photon or Electron module. See the “SIS Installation Instructions” document for information about loading software to the SIS Hub and testing it out:

https://github.com/TeamPracticalProjects/SISProject/blob/master/SISDocs/SIS_Firmware_Instal lation.pdf (https://github.com/TeamPracticalProjects/SISProject/blob/master/SISDocs/SIS_Firmware_Installation.pdf)

2 Optional item 9 on the Parts List.

3 Optional item 10 on the Parts List.

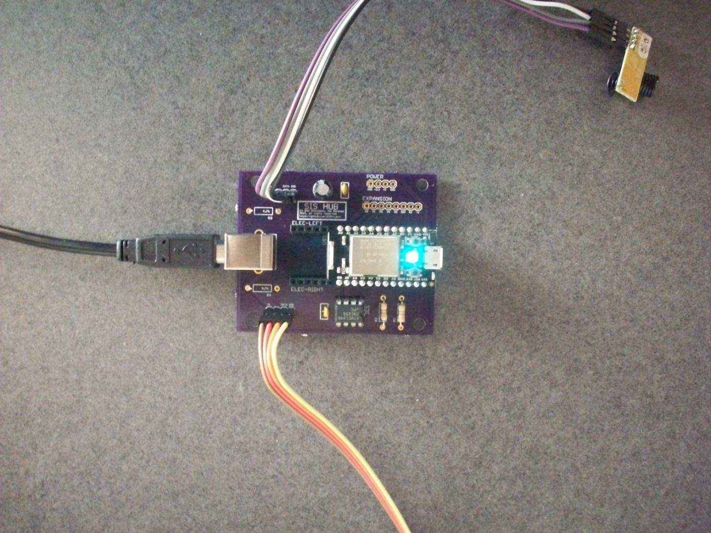
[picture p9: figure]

Page 11 of 13 | Copyright © 2015. Bob Glicksman and

Photo 8. Completed PCB, powered and wired to receivers modules.

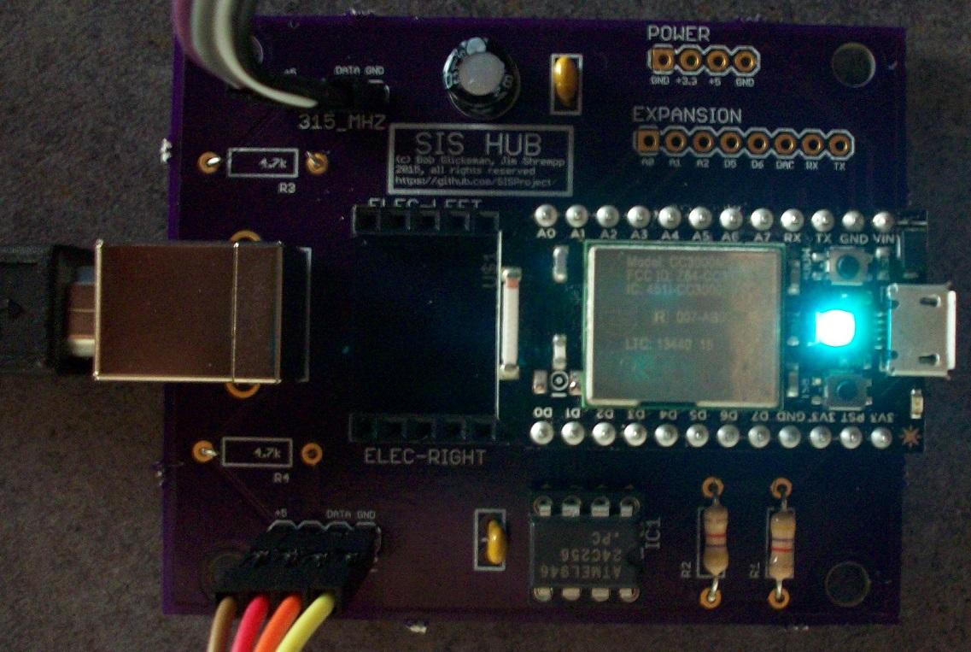
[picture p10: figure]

Page 12 of 13 | Copyright © 2015. Bob Glicksman and

Photo 9. Closeup of completed and powered PCB.

The completed USB hub assembly and RF receiver modules may be mounted in a suitable drilled plastic enclosure. A separate instruction is provided in this package covering the preparation and mounting of the SIS Hub PCB, receiver modules, and power cable in such an enclosure:

https://github.com/TeamPracticalProjects/SISProject/blob/master/SISDocs/SIS_Hub_Packaging_Assembly_Instructions.pdf (https://github.com/TeamPracticalProjects/SISProject/blob/master/SISDocs/SIS_Hub_Packaging_Assembly_Instructions.pdf)

Page 13 of 13 | Copyright © 2015. Bob Glicksman and

### APPENDIX A: SIS HUB PARTS LIST

| | | | | REQUIRED PARTS FOR PCB ASSEMBLY
Item # | Qty | Vendor | Vendor Part # | Description | Link | Notes
1 | 1 | OSHPark | SIS Hub PCB | SIS Hub Printed Circuit Board | https://oshpark.com/shared_projects/ptHf88 | Custom PCB - order from OSHPark or use the Eagle files to order from another vendor.
wY
2 | 1 | Particle | Photon | Particle Photon WiFi Microcontroller with breadboard headers | https://store.particle.io/?product=particle-photon | The Particle Electron may be supported in the future. The PC board has extension mounting holes to accommodate the larger Electron.
3 | 1 | Jameco | AT24C256PC | 24C256; 32 KB I2C EEPROM | http://www.jameco.com/webapp/wcs/store
s/servlet/Product_10001_10001_200580_-1
4 | 1 | E-Bay | NA | 315 MHz OOK Receiver | http://www.ebay.com/itm/315MHz-433MHz-
| | | | | Wireless-Super-Heterodyne-Remote-RX-
| | | | | Receiver-Module-107dBm-
| | | | | /181711941472?var=&hash=item2a4ee02f60

Select 315 Mhz from dropdown list. The same part is available from many Asian vendors on E-Bay and Amazon.

5 | 1 | E-Bay | NA | 433 MHz OOK Receiver | http://www.ebay.com/itm/315MHz-433MHz- Wireless-Super-Heterodyne-Remote-RX- Receiver-Module-107dBm- /181711941472?var=&hash=item2a4ee02f60

Select 433 MHz from dropdown list. The same part is available from many Asian vendors on E-Bay and Amazon.

6 | 10 | Jameco | CF1/4W472JRC | resistor - 4.7Kohm, 1/4 watt axial lead (minimum qty = 10)

http://www.jameco.com/webapp/wcs/stores/servlet/Product_10001_10001_691024_-1

Need 2 resistors

7 | 10 | Jameco | SR205E104MAA-VP | 0.1 uf Capacitor, 50 volt (minimum qty = 10) | http://www.jameco.com/webapp/wcs/store s/servlet/Product_10001_10001_544868_-1

need 2 capacitors

8 | 10 | Jameco | 100UF/16V 6X5 | 100 uF Capacitor, electrolytic | http://www.jameco.com/webapp/wcs/store s/servlet/Product_10001_10001_94289_-1

need 1 capacitor

9 | 1 | Jameco | USB-B-S-RA-WT | USB connector, B female | http://www.jameco.com/webapp/wcs/store s/servlet/Product_10001_10001_230958_-1
10 | 1 | Adafruit | 907 | Panel Mount USB cable, B male to B female | http://www.adafruit.com/products/907
11 | 1 | Adafruit | 266 | 40 conductor female-female jumper wires, separable. | http://www.adafruit.com/products/266 | Required only if the receivers are not mounted to the PC board. These jumers are used to connect pin headers soldered to the board in the receiver positions to the pins on the remotely mounted receivers.
12 | 1 | Jameco | 7000-1X40SG-R | Breakaway headers, straight, male | http://www.jameco.com/webapp/wcs/store | Required only if the receivers are mounted remotely from the PC board. May also be used for POWER and EXPANSION connections to the PC board.
s/servlet/Product_10001_10001_160882_-1
13 | 2 | Digi-Key | S7016-ND | 18 Pin female header | http://www.digikey.com/product-search/en?keywords=S7016-ND | 18 Pin headers will accommodate both Photon and Electron. 12 pin female headers may be used if only Photon support is needed.
14 | 1 | Jameco | 6100-8-R | 8 pin DIP socket | http://www.jameco.com/webapp/wcs/store | Alternative is to solder the Photon directly to the PC board, or to use 0.1" spaced female pin headers.
s/servlet/Product_10001_10001_51626_-1
| | | | | OPTIONAL PARTS FOR BOX MOUNTING AND POWERING
1 | 1 | Staples or on-line from Really Useful Boxes | in-store only | enclosure; 0.55 liter (1-7/16"H x 4"W x 8-1/2"L) | http://www.reallyusefulproducts.co.uk/usa/ | A smaller enclosure may be used if receivers are mounted to PC Bord directly vs taped to the sides of the enclosure. However, range of reception may sugger if the receivers are not at least 4" apart (and apart from the Photon WiFi chip). Boxes are available is various colors. html/onlineshop/rub/b00_55litre.php
2 | 4 | jameco | 2104-632-AL-7 | standoff, female-female, 1/2", 6-32 threaded

https://www.jameco.com/webapp/wcs/stores/servlet/ProductDisplay?storeId=10001&langId=-
1&catalogId=10001&pa=77543&productId=775 43

Use as required to mount PC board into the enclosure. Board will accommodate 4 standoffs. See below for Nylon standoffs if desired.

3 | 10 | jameco | H554-ND | Screw, 6-32x1/4", pan head, phillips
https://www.jameco.com/webapp/wcs/stores/servlet/ProductDisplay?storeId=10001&langId=-
1&catalogId=10001&pa=2094418&productId=2 094418

Use as required to mount PC board into the enclosure. Board will accommodate 4 screws (board to standoff) + 4 screws (standoff to enclosure). See below for Nylon screws, if desired.

4 | 4 | Digi-Key | 36-1903C-ND | standoff, female-female, 1/2", 6-32 threaded | http://www.digikey.com/product-search/en?KeyWords=36-1903C-ND&WT.z_header=search_go | Nylon alternative to metals standoffs, if desired.
5 | 100 | Digi-Key | H554-ND | Screw, 6-32x1/4", pan head, phillips | http://www.digikey.com/product-search/en/hardware-fasteners-accessories/screws-bolts/2097339?k=H554-ND | Nylon alternative to metal screws, if desired. Minimum order is 100 screws (need 8).
6 | 10 | Jameco | 0505HC-101S-R | Cable tie mount, nylon, 3/4" (minimum qty = 10) | http://www.jameco.com/webapp/wcs/store | Use as required for neatness. Should only require 4 or so tie mounts
s/servlet/Product_10001_10001_182942_-1
7 | 100 | Jameco | CV-075-R | Cable tie, nylon, 3" (minimum qty = 100)

http://www.jameco.com/webapp/wcs/stores/servlet/Product_10001_10001_70561_-1

Use as required for neatness. Should only require 4 or so ties

8 | 1 | Office max | 912408 | Scotch Outdoor Mounting Tape - Double Sided (one roll) | http://www.officedepot.com/a/products/745021/Scotch-Permanent-Heavy-Duty-Outdoor-Mounting/ | Use as required to affix receiver modules to the enclosure. Not required if receivers are mounted on the PC Board.
9 | 1 | Jameco | 10U2-02206-BK | USB Cable; A male to B male. | http://www.jameco.com/webapp/wcs/store | Optional - needed to bring power to the SIS Hub
s/servlet/Product_10001_10001_222010_-1
10 | 1 | Jameco | GS05U-USB | USB Power supply; 1Amp | http://www.jameco.com/webapp/wcs/store
| | | | | s/servlet/Product_10001_10001_2155823_-1

Optional - needed to bring power to the SIS Hub. Any USB power supply, 5 volts at 500 ma or more will work, as will USB

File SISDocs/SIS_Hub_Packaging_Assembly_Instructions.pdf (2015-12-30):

Page 1 of 8 | Copyright © 2015. Bob Glicksman and Jim Schrempp. All rights reserved.

## INSTRUCTIONS

## For Assembly of the SIS Hub Package

Bob Glicksman, Jim Schrempp

Date: 12/30/2015

1) INTRODUCTION.

### OVERVIEW

The SIS hub PCB can be run in the open air, but we feel it should be protected in some way and we recommend enclosing the SIS hub PCB and receivers in a plastic box. These instructions will guide you.

These instructions use an 0.55-liter pencil box of the brand Really Useful Box (http://www.reallyusefulproducts.co.uk/usa/html/onlineshop/rub/b00_55litre.php). We purchased ours at Staples for $5.00.

### TOOLS AND SUPPLIES

Before beginning assembly of the shield board, the following tools and supplies should be at hand:

Parts: Refer to the Parts List at:

NOTICE: Use of this document is subject to the terms of use described in the

document “Terms_of_Use_License_and_Disclaimer” that is included in this release package. This document can also be found at:

https://github.com/TeamPracticalProjects/SISProject/blob/master/SISDocs/Terms_of_Use_License_and_Disclaimer.pdf (https://github.com/TeamPracticalProjects/SISProject/blob/master/SISDocs/Terms_of_Use_License_and_Disclaimer.pdf)

Page 2 of 8 | Copyright © 2015. Bob Glicksman and Jim Schrempp. All rights reserved.

https://github.com/TeamPracticalProjects/SISProject/blob/master/SISDocs/SIS_Hub_Parts_List. pdf (https://github.com/TeamPracticalProjects/SISProject/blob/master/SISDocs/SIS_Hub_Parts_List.pdf)

a) Assembled SIS hub PCB. Instructions for assembling the SIS hub PCB can be found at:
https://github.com/TeamPracticalProjects/SISProject/blob/master/SISDocs/SIS_Hub_Packaging_Assembly_Instructions.pdf (https://github.com/TeamPracticalProjects/SISProject/blob/master/SISDocs/SIS_Hub_Packaging_Assembly_Instructions.pdf)
b) Panel Mount USB Cable - B Male to B Female
c) Plastic standoffs, 1/2-inch, 6-32 threaded at both ends.
d) 6-32 plastic screws, ¼” long
e) Plastic cable ties and stick-on cable tie holders. Tools:
f) Sharp box knife
g) Philips screwdriver
h) Awl or other marking device
i) Drill with 1/8-inch bit, 5/32” bit and 1/4-inch bit Supplies:
j) Electrical tape

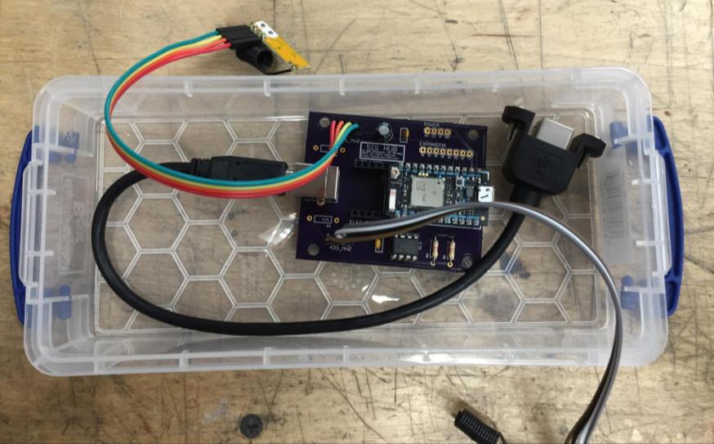
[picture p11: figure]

Page 3 of 8 | Copyright © 2015. Bob Glicksman and Jim Schrempp. All rights reserved.

### LAYOUT

In this step you will make sure your parts all fit in the box and decide where the panel mount connectors will go.

Open your plastic case and put it in front of you. Place the SIS hub PCB into the case, near the middle. Connect the USB cable to the SIS hub PCB and note where you may place the panel mount connector without putting undue strain on either end of the cable. Photo 1 shows where we decided to mount the SIS hub PCB in our box.

Photo 1: Placement of the SIS hub in the box

### MOUNT THE PCB

In this step you will mount the SIS hub PCB to the case bottom.

Holding the PCB in the location you have selected, use an awl, ballpoint pen, or other sharp item to mark the four hole positions in the bottom of the case. You might adjust the PCB position slightly to avoid the hexagonal bracing in the case bottom.

Use the 5/32-inch drill to put four holes in the case bottom. Screw in four plastic standoffs. Then place the PCB on the standoffs and close the lid - make sure it fits with enough clearance.

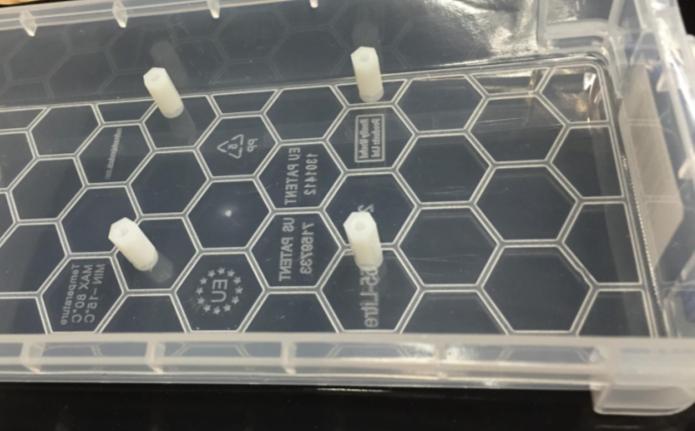
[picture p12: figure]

Page 4 of 8 | Copyright © 2015. Bob Glicksman and Jim Schrempp. All rights reserved.

Photo 2: Standoffs Mounted in Box

### Mount the USB cable

In this step you will mount the USB cable panel mount connector to the case.

Place the panel mount connector against the case in the position you have chosen. From the outside of the case carefully mark the center of the two mounting holes. Using the ⅛-inch drill bit, drill these two holes.

Hold the panel mount connector up to the holes and make sure they are aligned correctly. Using a tool scribe a square approximately around the outside of the metal USB connector that is part of the panel mount connector.

Use the ¼-inch drill bit to drill a hole in the center of the scribed square.

Now is the most delicate part. Using the box cutter, carefully cut from the center hole to the corners of the scribed square. Be careful that you do not cut your hand if the knife slips!!!

Now use the box cutter to score along each of the sides of the scribed square. Continue to score the lines until the plastic bits come free and you have a square hole in the side of your case.

Alternatively, use a small file to file the round hole out to match the square outline.

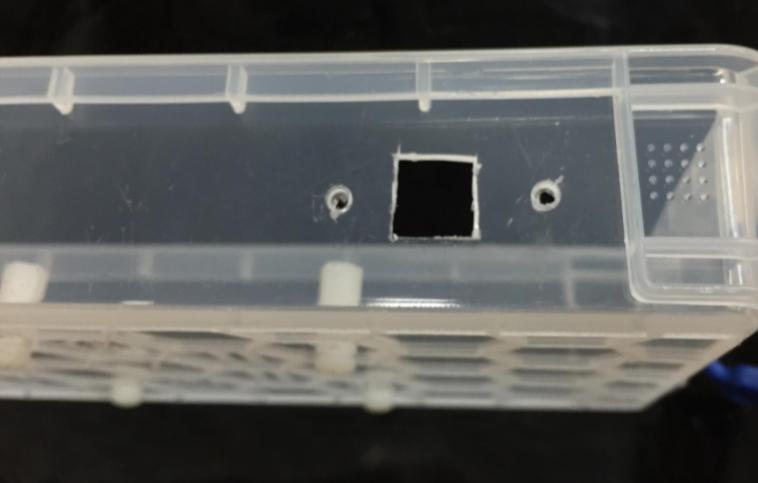
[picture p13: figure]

Page 5 of 8 | Copyright © 2015. Bob Glicksman and Jim Schrempp. All rights reserved.

Photo 3: The hole for the panel mount connector

Use the panel mount screws to attach the other end of the cable to the case. You should place the arched side of the USB connector towards the top of your case.

Drill Ventilation Holes.

In this step you will drill 4 ea ¼” holes in the side of the box for cooling. The hole placement is not critical. We recommend placing one hole on each long side of the box, halfway between the top and the bottom and approximately centered along the side (under the center-most lid support tab). We recommend placing the other hole on each side of the box, half way between the first hole and the end of the box. Choose the end that does NOT have the USB connector on this side of the box and the opposite end on the other side of the box. Drill a ¼” hole at each of these four positions. Leave the holes open to provide ventilation when the SIS Hub is operating.

### Add the PCB

Connect the USB cable to the SIS hub PCB. Snake the cable under the PCB and between the plastic standoffs as you place the PCB on top of the standoffs. Use four plastic screws to mount the PCB to the standoffs.

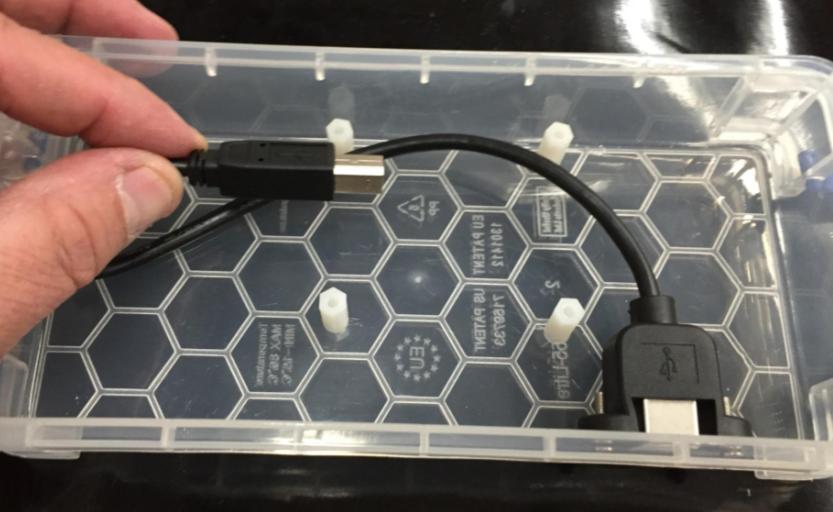
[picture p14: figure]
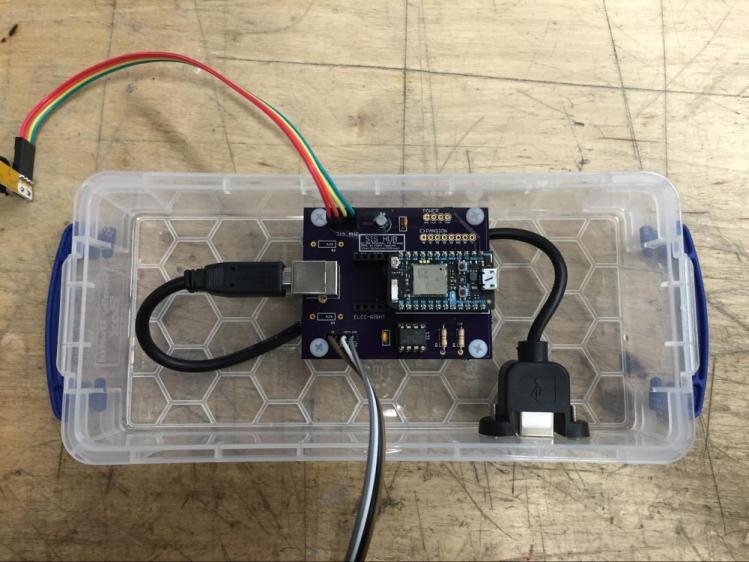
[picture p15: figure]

Page 6 of 8 | Copyright © 2015. Bob Glicksman and Jim Schrempp. All rights reserved.

Photo 4: Where the USB cable goes

Photo 5: The SIS hub Mounted in Box

### Mount the Receivers

In this step you will mount the two radio frequency receivers.

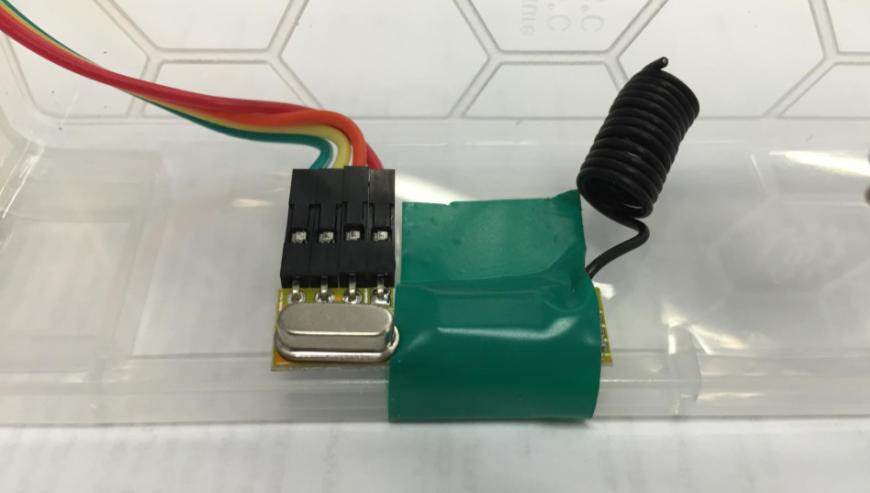
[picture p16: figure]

Page 7 of 8 | Copyright © 2015. Bob Glicksman and Jim Schrempp. All rights reserved.

Choose two positions at opposite corners of the box. Ensure that the receives are at least 4” away from the chip antenna on the Photon module on the SIS hub PCB and also at least 4” away from each other. This will maximize receiving range. Using a bit of electrical tape, or a small piece of double-sided tape, stick the two receivers to the inside of the case.

Photo 6: Taping a Receiver to the Box

### Power On

Place the top on your case and latch it. Plug your SIS hub into a USB power source and your SIS hub is ready for use!

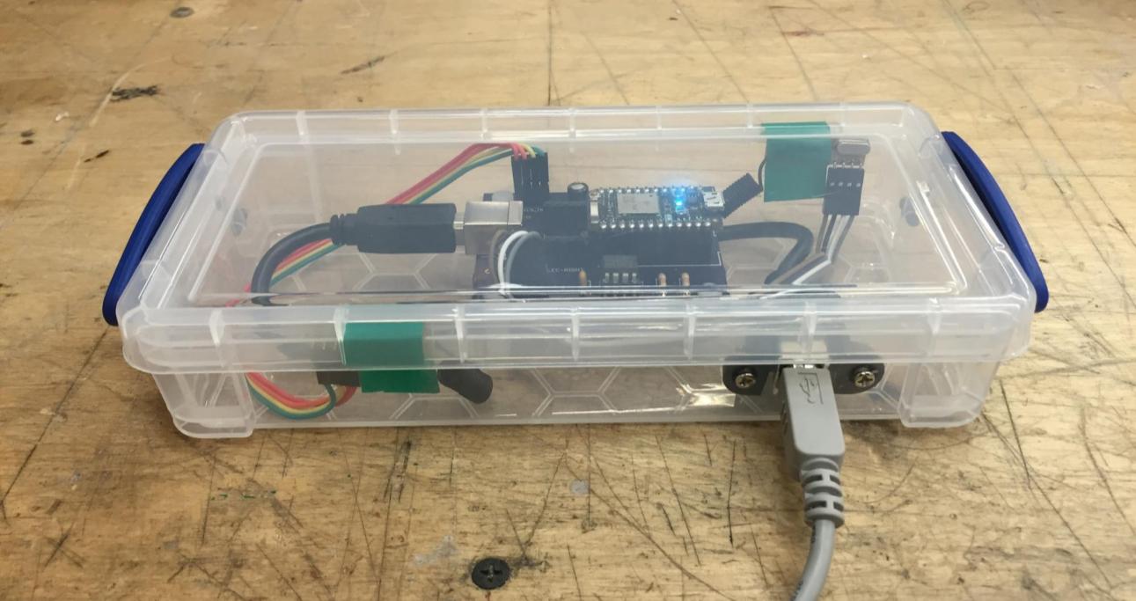
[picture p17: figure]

Page 8 of 8 | Copyright © 2015. Bob Glicksman and Jim Schrempp. All rights reserved.

Photo 7: The Finished Product

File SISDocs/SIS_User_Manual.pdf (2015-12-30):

Page 1 of 23 | Copyright © 2015. Bob Glicksman and Jim Schrempp. All rights reserved.

## SIS USER MANUAL

Bob Glicksman, Jim Schrempp Date: 12/29/2015

### Contents

1. INTRODUCTION.

1.1.Overview.
This document provides detailed instructions for using the SIS Client app. The SIS Client app is a javascript-enhanced web page. The SIS Client can be run on any device that has a web browser that supports javascript. The SIS Client has been tested on the following devices/browsers, but should run on virtually any device running any modern web browser. Tested environments include:
- Windows/Internet Explorer.
- Windows/ Google Chrome

NOTICE: Use of this document is subject to the terms of use described in the

document “Terms_of_Use_License_and_Disclaimer” that is included in this release package. This document can also be found at:

https://github.com/TeamPracticalProjects/SISProject/blob/master/SISDocs/Terms_of_Use_License_and_Disclaimer.pdf (https://github.com/TeamPracticalProjects/SISProject/blob/master/SISDocs/Terms_of_Use_License_and_Disclaimer.pdf)

Page 2 of 23 | Copyright © 2015. Bob Glicksman and
- Android/ Google Chrome
- Mac/ Safari
- Mac/Firefox
- iOS/Safari

1.2.Pre-requisites.
Before you can use the SIS Client, you must have completed the following:
- Read and accepted the Terms of Use of SIS at:

https://github.com/TeamPracticalProjects/SISProject/blob/master/SISDocs/Terms_of_Use_License_and_Disclaimer.pdf (https://github.com/TeamPracticalProjects/SISProject/blob/master/SISDocs/Terms_of_Use_License_and_Disclaimer.pdf)

- Read and understood the SIS Theory of Operation and Installation Guide at:

https://github.com/TeamPracticalProjects/SISProject/blob/master/SISDocs/SIS_Theory_of_Operation_and_Installation.pdf (https://github.com/TeamPracticalProjects/SISProject/blob/master/SISDocs/SIS_Theory_of_Operation_and_Installation.pdf)

- Purchased parts and assembled an SIS Hub, per the instructions at:

https://github.com/TeamPracticalProjects/SISProject/blob/master/SISDocs/SIS_Hub_PCB_Assembly_Instructions.pdf (https://github.com/TeamPracticalProjects/SISProject/blob/master/SISDocs/SIS_Hub_PCB_Assembly_Instructions.pdf)

- Optionally, mounted your SIS Hub electronics in a plastic enclosure, per:

https://github.com/TeamPracticalProjects/SISProject/blob/master/SISDocs/SIS_Hub_Packaging_Assembly_Instructions.pdf (https://github.com/TeamPracticalProjects/SISProject/blob/master/SISDocs/SIS_Hub_Packaging_Assembly_Instructions.pdf)

- Created a free cloud account at particle.io and used this account to upload and test the firmware to your SIS Hub:

https://github.com/TeamPracticalProjects/SISProject/blob/master/SISDocs/SIS_Firmware_Instal lation.pdf (https://github.com/TeamPracticalProjects/SISProject/blob/master/SISDocs/SIS_Firmware_Installation.pdf)

- Planned your installation and purchased and installed your sensors, per the instructions in the aforementioned Theory of Operation and Installation Guide.
2. LOGGING IN TO THE SIS CLIENT.

You can obtain the SIS Client app by opening your web browser and going to the SIS home page:

http://shrimpware.com/SIS/

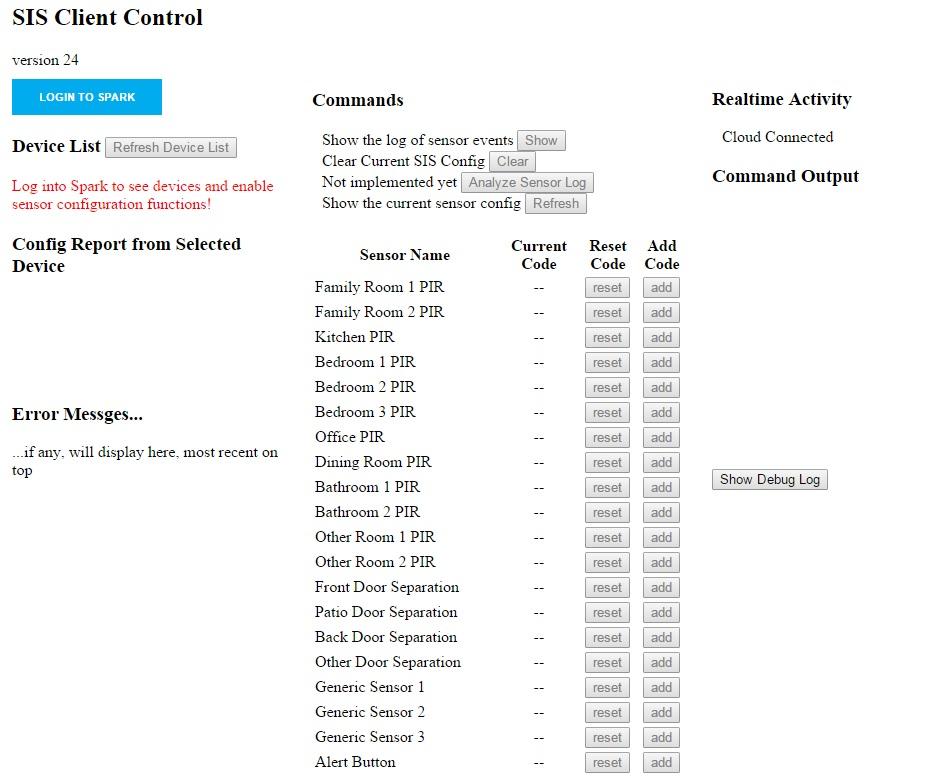
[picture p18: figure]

Page 3 of 23 | Copyright © 2015. Bob Glicksman and

After selecting the “Standard SIS Client Control”, you should then be presented with a screen similar to that shown in figure 1:

Figure 1. SIS Client Opening Screen.

The next step is to log into the particle.io cloud in order to establish communication with your SIS Hub device. Click the blue button at the top left of the screen marked “LOGIN TO SPARK”. You will see a login panel over a grayed out screen, similar to figure 2:

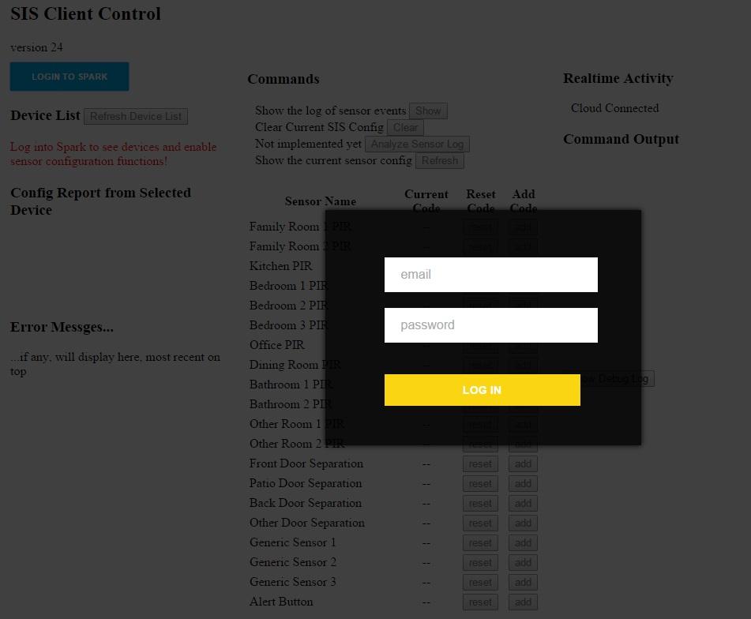
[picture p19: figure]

Page 4 of 23 | Copyright © 2015. Bob Glicksman and

Figure 2. Log-in Panel.

Use the Login Panel to log into your particle.io account using your e-mail and particle.io password. Ten click the yellow LOG IN button to log in. You should then see a screen similar to figure 3 (cropped off):

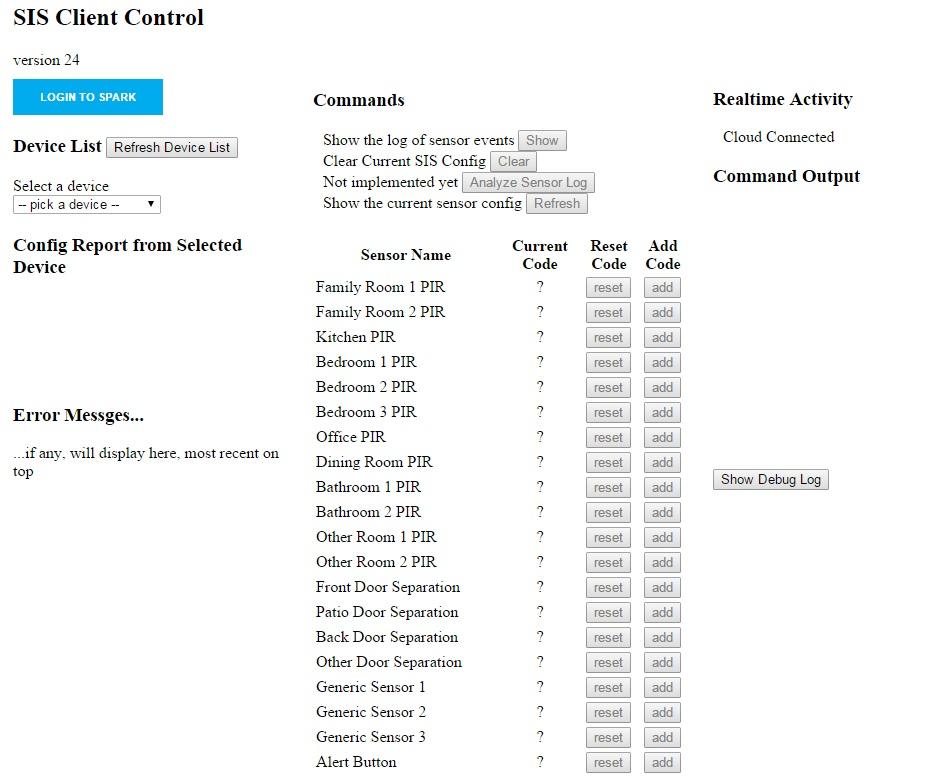
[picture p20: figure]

Page 5 of 23 | Copyright © 2015. Bob Glicksman and

Figure 3. Device Selection Screen.

Referring to figure 3, you will see “Select a device” below the Device List heading on the upper left hand side of the screen. Below this is a drop down list that says “ – pick a device – “. Click on this list and select the device that is the SIS Hub that you wish to communicate with. Note that you can have many SIS Hubs in your particle.io account.

Make sure that your SIS Hub device shows as “ON LINE” in the dropdown list. Your device will be online when it is powered up and connected to the particle.io cloud via the home’s WiFi. After selecting your device from the drop down list, you will see a screen similar to figure 4. Note that it will take a few seconds to fully populate this screen, as the javascipt code behind the screen display is accessing your selected SIS Hub and reading out the current configuration information.

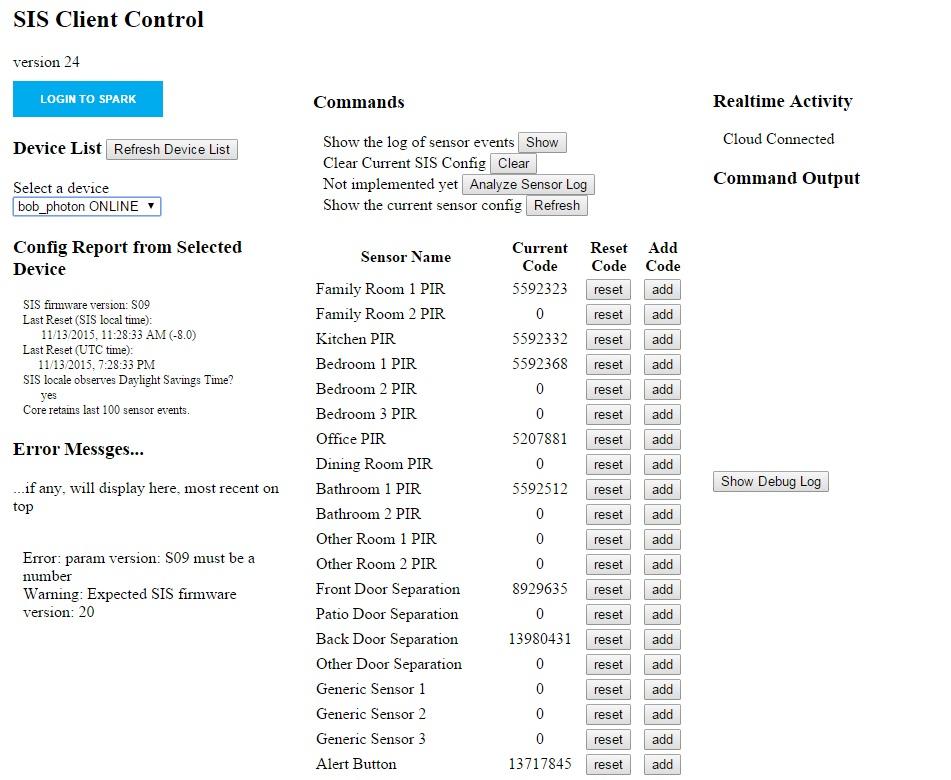
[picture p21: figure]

Page 6 of 23 | Copyright © 2015. Bob Glicksman and

Figure 4. Device Connected Screen.

You will note several things on the screen of figure 4:

- On the left hand side of the screen, under your selected device, will be information about the device that you just connected with (Config Report from Selected Device). In particular, the time of the last reset will be displayed. You should take note of this time so that when you read out the log, you will know if the SIS Hub has been reset (e.g. due to a power failure) and thus the starting date/time for the log entries.
- One the right hand side of the screen, you will see the message “Cloud Connected” under Realtime Activity. This message will periodically blink green to indicate that cloud communication with the selected SIS Hub is ongoing. If this message is red, it means that the designed SIS Hub device is not presently connected to the particle.io cloud over the Internet.

Page 7 of 23 | Copyright © 2015. Bob Glicksman and
- In the center of the screen, you will see the current sensor configuration for the SIS Hub. Any entry with a non-zero “Current Code” is a room/location with a sensor registered to it.
3. SENSOR REGISTRATION USING THE SIS CLIENT.

The section describes how to register sensors and manage the sensor configuration within an SIS installation using the SIS Client. You must be thoroughly familiar with the SIS Theory of Operation and Installation Manual in order to properly configure, place and register your sensors:

https://github.com/TeamPracticalProjects/SISProject/blob/master/SISDocs/SIS_Theory_of_Operation_and_Installation.pdf (https://github.com/TeamPracticalProjects/SISProject/blob/master/SISDocs/SIS_Theory_of_Operation_and_Installation.pdf)

Note that you need to trip sensors installed in the home as part of this registration process. Therefore, you should be running the SIS Client app on a laptop, tablet or mobile phone that is battery powered and connected to the Internet via WiFi. This way, you can go to each sensor location, trip the sensor and register it using the SIS Client app as you do so.

Referring to figure 4, above: sensor registration is managed in the center column (Commands) of the SIS Client display. There are two commands directly under the heading that are applicable to sensor configuration management:

- Clear Current SIS Config (Clear): Clicking on the Clear button will clear out the sensor configuration. This means that all sensor locations (rooms) will not have any sensor registered to them. Clear should be used only when re-using an SIS Hub at a new location, so that all previously registered sensors can be unregistered with one button click. Otherwise, the individual room resets should be used (see below).
- Show the current sensor config (Refresh): The table underneath the Commands shows the sensor configuration when the SIS Client last contacted the SIS Hub. The SIS Client attempts to keep this table up to date as you make configuration changes. However, you can always update the table to display the current sensor configuration by clicking Refresh.

Below these command buttons is a table that displays the current sensor configuration for the selected SIS Hub. The table also includes Reset Code and Add Code buttons. These buttons affect only the room (location) that they are associated with. These buttons should be used to remove or change a sensor at a particular location in the home.

The sensor configuration table displays the room/location under the heading Sensor Name. The names of these rooms/locations are fixed in the SIS Client and cannot be changed by the user. When planning an SIS sensor configuration, the user should map locations in the home with the best fit name in the table. The table has provision for 12 PIR motion sensors, 4 exterior door

Page 8 of 23 | Copyright © 2015. Bob Glicksman and

separation sensors, three generic sensors and one Alert sensor. The specific meanings of each of these types of sensors in described in the SIS Theory of Operation and Installation Manual, and you must configure each sensor as the proper type in order for SIS to work properly.

The column labeled Current Code shows a decimal number representation of the sensor trip code associated with that location. If the location does not have a sensor registered to it, the Current Code will show 0.

Before you can add a sensor to a location, the location’s sensor configuration must be unregistered (Current Code of 0). If you try to add a sensor to a location with a sensor registered to it, you will get an error message and the old sensor trip code will remain registered to that location. In order to change the registration to a new sensor, you must click on the reset button to reset the location to unregistered. Thereafter, you can register a new sensor to that location.

Figure 5 shows the same SIS Client display as figure 4, except that the reset button has been pressed on the Office PIR line in the table. After a few seconds, the display will refresh the sensor configuration table as shown in figure 5.

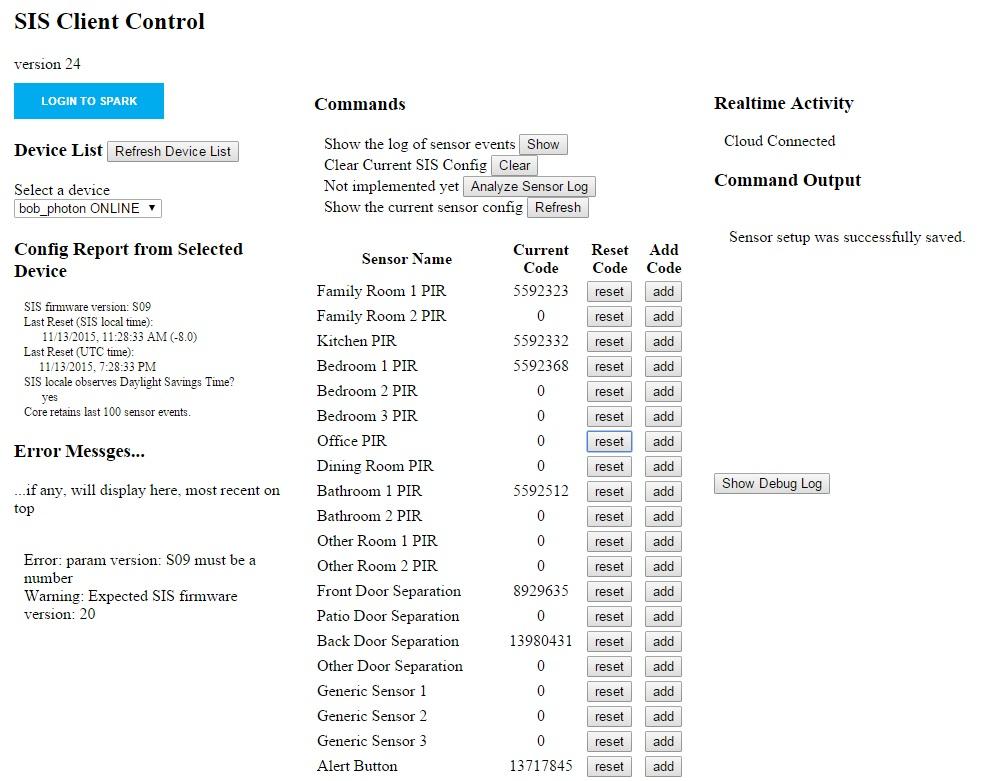
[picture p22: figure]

Page 9 of 23 | Copyright © 2015. Bob Glicksman and

Figure 5. Reset the “Office PIR” Sensor Configuration to unregistered.

Now, a new sensor can be registered by pressing the add button in the Add Code column of the Office PIR row in the table. When you do this, you will get a popup window, as shown in figure 6:

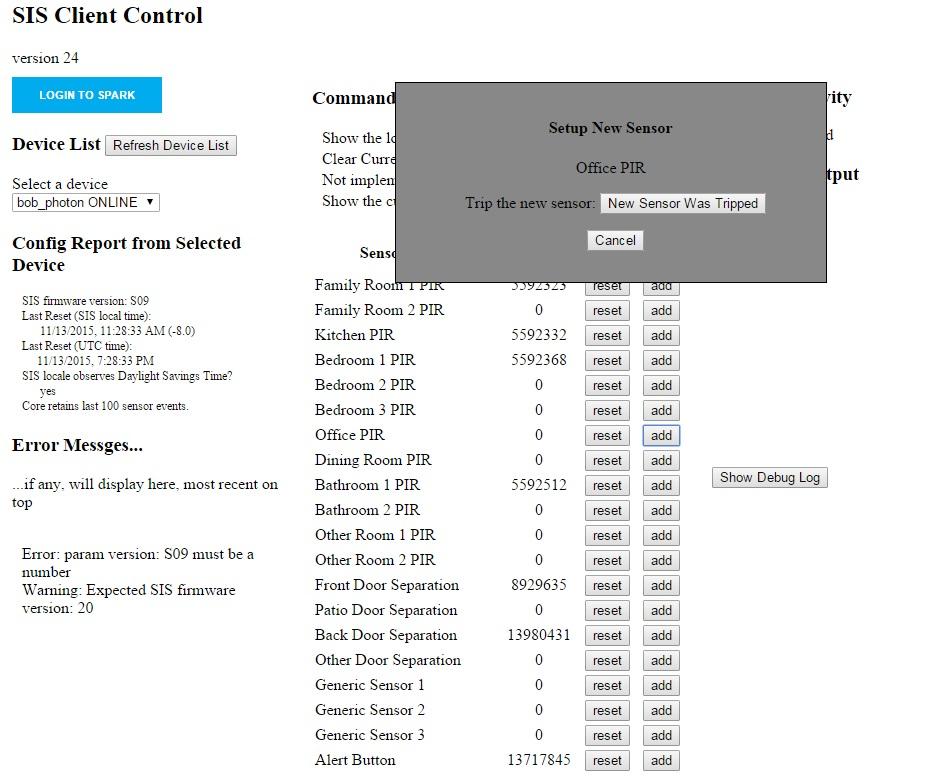
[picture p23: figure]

Page 10 of 23 | Copyright © 2015. Bob Glicksman and

Figure 6. Adding a Sensor to the Office PIR Location.

When you see the popup window in figure 6, trip the sensor at that location. You can verify that the sensor was tripped by observing the LED on the sensor. All SIS sensors have an LED that lights up for a few seconds after the sensor is tripped.

After tripping the new sensor, click the New Sensor Was Tripped button in the pop up dialog box. You will then see a display similar to figure 7:

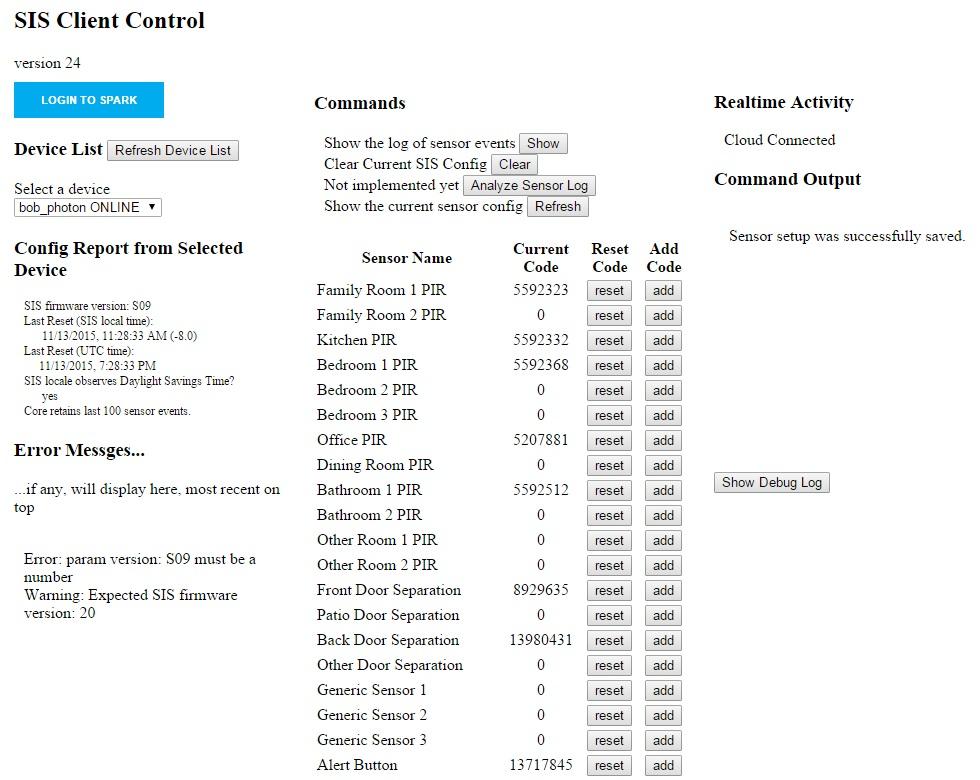
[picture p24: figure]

Page 11 of 23 | Copyright © 2015. Bob Glicksman and

Figure 7. Registration of a New Sensor.

If the operation was successful, you will see the new sensor trip code listed in the table and the message “Sensor setup was successfully saved.” under the Command Output heading on the right hand column of the SIS Client display.

4. READING AND INTERPRITING THE SIS LOG.

The center column of the SIS Client app screen, under Commands, contains a button:

“Show the log of sensor events” Show.

Clicking on Show displays the SIS Hub log, under Command Output in the right hand column of the screen; similar to figure 8.

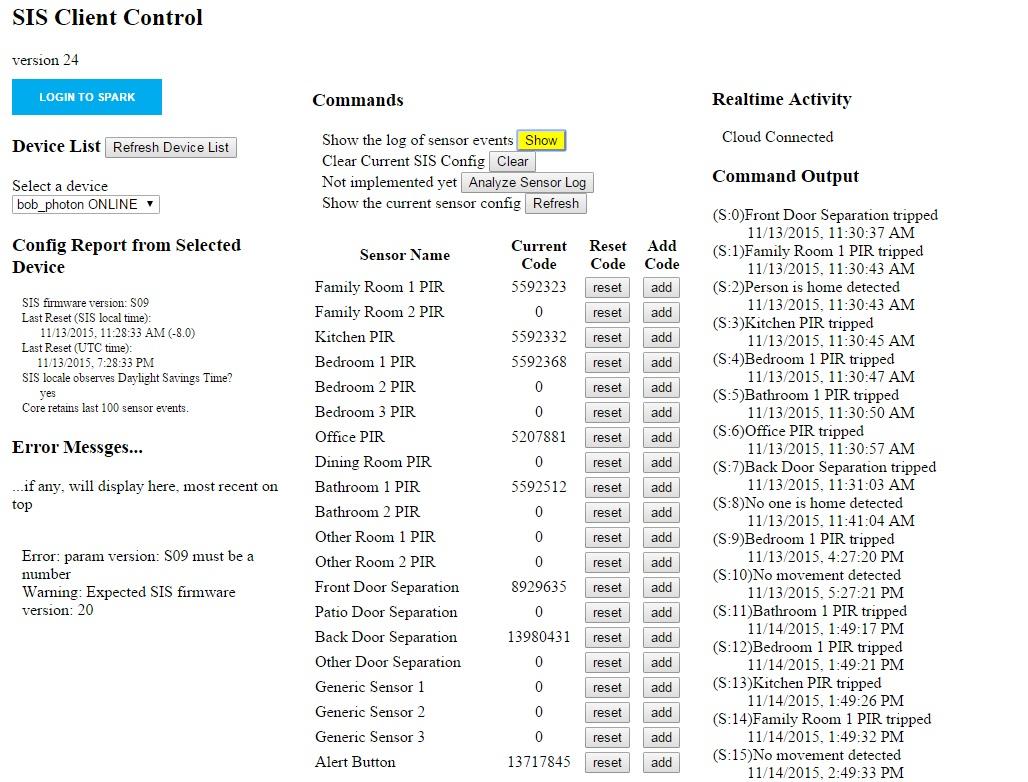
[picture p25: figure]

Page 12 of 23 | Copyright © 2015. Bob Glicksman and

Figure 8. Displaying the SIS Log.

The log entries are displayed below the Command Output with the most recent log entry shown first (at the bottom) and the last (oldest) entry in the log shown at the top. Note that it may take about one second per log entry to populate this display. Note too that the log will display the last (latest) 100 entries (or fewer, if there are fewer than 100 entries in the SIS Hub log).

The log entries are formatted to show a one-up “sequence number”, followed by a message about the log entry, followed by a time stamp of when the log entry occurred. For example:

(S:3)Kitchen PIR tripped
11/13/2015, 11:30:45 AM

The “(S:3)” is the sequence number of the log entry. Sequence numbers begin at 0 and increment sequentially up to 9999, and then roll back to 0. Sequence numbers are useful in determining if an entry has been missed and also in tracking the last log readout to determine which entries are new. If the SIS Hub is reset (e.g. due to power failure), the sequence numbers will reset to zero. Thus, if the last sequence number that you read out from the log was (S:1534)

Page 13 of 23 | Copyright © 2015. Bob Glicksman and

and now you read out the log and it begins with (S:0), that means that the SIS Hub was reset in between your last readout and the present readout of the log. You should consult the time of last reset in the left hand column of the display in order to understand what times may have been missed due to the resetting of the SIS Hub.

When using the SIS Client app to read the log out from the SIS Hub directly (in real time), the sequence numbers should be sequential with no gaps (no missing numbers). If you use IFTTT to send log entries to a Google spreadsheet in the cloud (section 6, below), there may be missing sequence numbers, indicating that there was some Internet communication problem when the log entry was published to the Internet and that the data was lost. The IFTTT mechanism has a number of advantages over reading out the SIS Hub internal log in real time; however, it can be unreliable in the face of Internet communication issues. A gap in the sequence numbers will indicate that some entries are missing from the Google spreadsheet; however, the internal SIS Hub log should have no gaps and can therefore fill in any missing information.

After the sequence number comes the message; in this example “Kitchen PIR tripped”. This is an example of a logged event, as described in the SIS Theory of Operation and Installation Guide. After the message, on the next line, is the time stamp of the message (in this example “11/13/2015, 11:30:45 AM”).

The time stamp requires further discussion. When the SIS Hub logs a sensor trip, an event, or an inference, a time stamp is applied. The SIS Hub software uses Internet time (in Universal Coordinated Time -- UTC) for the time stamp. The SIS Client app converts UTC to the actual time where the SIS Hub is located using the configuration parameter “utcOffset”. You can see the utcOffset in the entry:

“Last Reset (SIS local time):
11/13/2015, 11:28:33 AM (-8.0)”

This entry is found on the left side of the screen (figure 8), under Config Report from Selected Device. Note that the “(-8.0)” is the currently configured utc offset, and is used to convert UTC to local time in the log displayed by the SIS Client app.

At present, the SIS Client app does not support changing the utcOffset from the default “-8.0” value (Pacific Standard Time). If you need to change this default (e.g. to -5.0 for US Eastern Standard Time), you may do so using the SIS Debug Client. The procedure to do this is described in section 7 of this document. You should only have to do this once per SIS installation.

At present, the SIS Client does not have capability to adjust the displayed log time stamp for Daylight Savings Time. The SIS Hub configuration does have a parameter for whether the location observes DST or not, but the SIS Client does not currently make the DST adjustment when the log is displayed. Therefore, the user must make the time adjustment manually, if needed.

Page 14 of 23 | Copyright © 2015. Bob Glicksman and
5. USING IFTTT TO BE NOTIFED WHEN THE ALERT SENSOR IS TRIPPED.
SIS supports registration of one sensor or wireless “button” (e.g. keyfob) as an “Alarm/Alert” sensor. Tripping this sensor (pressing the button) causes the SIS Hub to log the action as a sensor trip, in the same manner as other “misc” sensors. However, tripping this sensor or button also sends a special message out over the Internet to the particle.io cloud. It is possible to use a free web service called “IFTTT” to pick up this message and use it to notify someone of the event in near real time. This “notification” can be anything that IFTTT can generate. One specific example is to send an SMS text message to a registered (to IFTTT) mobile phone.

Note: IFTTT response to a cloud publication in this manner is not a reliable service. There can be considerable delay in delivery of the message and it is possible, under various circumstances outside of the SIS’ control, to have the notification dropped altogether. Therefore, this capability should be used as a convenience only and not relied upon for emergency services.

In order to use this capability you must register at:

https://ifttt.com

You must then create a “recipe”, as described below.

These instructions apply strictly to sending a text message to your mobile phone. However, feel free to explore all of IFTTT’s many channels for other things that you can do in response to the Alert message from SIS.

Once you register with IFTTT, you can create an “IF” recipe. When you click on “Create a Recipe”, you will be presented with a message in large type saying “If This than That”. In IFTTT, you select “This” to create the trigger (in this case, the cloud message from your SIS Hub), and “That” to create the action (in this case, to send an SMS text message to your mobile phone).

When you get the first “If This than That” message, “This” will be in underlined blue, indicating that you need to specify the trigger. Click on “This” and it will say “Choose a channel”. The channel that you need to choose is “Particle”. You will then be prompted to “Choose a trigger”. You will select “New event published”. Note that if you have not previously registered the Particle channel to your IFTTT account, you will have to do so first – follow the prompts from IFTTT to put your particle.io account information into IFTTT.

Once you have registered your particle.io account to IFTTT and selected the “New event published” trigger, you will be presented with a number of fields to fill in:

- IF (Event Name): type in “SISAlarm”. Type this in exactly as shown here, without the quotes.
- Is (Event Contents); leave this field blank.

Page 15 of 23 | Copyright © 2015. Bob Glicksman and
- Device Name or ID: select the device registered to your particple.io account that you want this IFTTT recipe to apply to (the device name for your SIS Hub).

After completing the “This” part of the recipe, IFTTT will again present you with “If This than That” in large letters and with “That” underlined in blue. If you want the action to send you an SMS text message, you select the “sms” channel (the IFTTT native SMS channel). Once again, you will have to register your mobile information to this channel if you had not previously subscribed to it. You select the action entitled “Send me an SMS”. IFTTT will present you with a default message to send to your mobile phone, which you can edit or leave as is (your choice).

Finally, IFTTT will assign you a recipe name, which you can leave as is.

IFTTT provides you with tools to enable or disable your recipes, edit your recipes, and delete recipes. See the IFTTT on-line documentation for more information. You can test this new recipe by triggering the registered Alarm sensor and seeing that you get the SMS message that you specified. Note that it may take some time – a minute or more – before the message comes though. If, at any time in the future, you wish to disable getting these messages, you can turn the recipe off in your IFTTT account.

6. USING IFTTT TO LOG TO A GOOGLE SPREADSHEET IN THE CLOUD.

Every time that the SIS Hub adds an entry into its internal log, it also publishes a message to the particle.io cloud. You can use the free service IFTTT (https://ifttt.com) to enter these log messages into a Google spreadsheet. In order to do this, you also need a free Google account.

Note: IFTTT response to a cloud publication in this manner is not a reliable service. There can be considerable delay in delivery of the message and it is possible, under various circumstances outside of the SIS’ control, to have the logging dropped altogether.

The advantages to using a Google spreadsheet to create a duplicate log in the cloud are (1) the log is persistent and won’t disappear with an SIS Hub reset or power failure, and (2) the log is much longer – it is 2000 entries per spreadsheet and when one spreadsheet fills, a new one is automatically created. The internal SIS log is 100 entries long and overwrites the oldest entries with newer ones once 100 entries have been received.

The disadvantages to using a Google spreadsheet for a cloud-based log are: (1) it may take some time (several minutes or more) for an entry to appear in the Google spreadsheet and (2) some entries may be completely missing, owing to Internet related communication events outside of SIS’ control. Note that a missing entry can easily be determined by a gap in the sequence numbers. There will be no gap in sequence numbers in the internal SIS log, which can be read out in real time as described in section 4, above. It is thereby possible to use both logs – the SIS internal log for timeliness and completeness and the Google spreadsheet log for long term data retention.

Page 16 of 23 | Copyright © 2015. Bob Glicksman and

In order to obtain a log in a Google spreadsheet in your Google account, you need to have a Google account (free) and also an IFTTT account. If you don’t have an IFTTT account, proceed as described in section 5, above.

After creating both your Google account and your IFTTT account, proceed in IFTTT to create a new “IF” recipe, similarly to section 5. The “This” channel will again be the “Particle” IFTTT channel and the trigger will (again) be “New event published”. You will be presented with a number of fields to fill in:

- IF (Event Name): type in “LogEntry”. Type this in exactly as shown here, without the quotes.
- Is (Event Contents); leave this field blank.
- Device Name or ID: select the device registered to your particple.io account that you want this IFTTT recipe to apply to (the device name for your SIS Hub).

After completing the “This” part of the recipe, IFTTT will again present you with “If This than That” in large letters and with “That” underlined in blue. You want the channel to be the “Google Drive” IFTTT channel. If you have not previously registered this channel to your IFTTT account, IFTTT will prompt you to do so. After registering the Google Drive channel, the IFTTT action you select will be “Add row to spreadsheet”. IFTTT will prompt you to fill in the following fields:

- Spreadsheet name: You can name this anything that you want, such as “Grandma’s activity log”.
- Formatted row: You can leave the defaults here or change them. The defaults create 4 columns in the spreadsheet with the event name (“LogEntry”), Event Contents (the message, which is similar to the contents of the SIS Hub’s internal log), your chosen device name, and a Google generated time stamp (which is in the timezone that Google recognized you to be in – not necessarily the timezone where the SIS is located!).
- Drive folder path: You can specify a folder path on your Google Drive to put the spreadsheet in or just leave this field blank (in which case, IFTTT will place a folder called “IFTTT” on your Google Drive and put the spreadsheet inside of this folder).

Finally, IFTTT will assign you a recipe name, which you can leave as is.

A typical log entry on your Google Spreadsheet will look something like this:

LogEntry

(S:3)Kitchen PIR tripped at Fri Nov 13
19:30:45 2015 Z (epoch:1447443045Z) bob_photon

November 13,
2015 at 11:30AM

Page 17 of 23 | Copyright © 2015. Bob Glicksman and

Note that the logged message has the SIS time stamp in UTC but that Google’s time stamp is in local time (which will be corrected for daylight savings time, by Google).

IFTTT provides you with tools to enable or disable your recipes, edit your recipes, or delete recipes. See the IFTTT on-line documentation for more information. You can test this new recipe by triggering some registered sensors and then looking at the entries in the Google Spreadsheet on your Google Drive. Note that it may take some time – perhaps several minutes – before the spreadsheet entries appear. If, at any time in the future, you wish to disable logging entries to your Google Spreadsheet, you can turn the recipe off in your IFTTT account.

7. USING THE DEBUG CLIENT FOR ADVANCED OPERATIONS.

The SIS Client app currently has certain limitations:

- It cannot be used to set the time zone offset (from UTC) of the location where the SIS Hub is installed. The default time zone offset is -8.0, which corresponds to Pacific Standard Time. As a result, the time stamps for SIS log entries will be displayed in Pacific Standard Time. If you wish to change this, you must use the Debug Client to do so, as explained below.
- The SIS Hub defaults to a configuration entry that says that the location of the SIS Hub observes Daylight Savings Time. The SIS Client does not presently adjust for Daylight Savings Time; however, the Debug Client may be used to change the SIS Hub configuration to indicate that it is in a location that does not observer Daylight Savings Time.
- The Debug Client may be used to obtain detailed information from the SIS Hub that is not available using the SIS Client app. It may also be used to register sensors to any location (any location name) and is not limited to the default rooms/locations shown on the SIS Client display. A full description if the Debug Client is beyond the scope of this document and changing sensor registration locations is not described herein.

To change the time zone offset configuration parameter in the SIS Debug Client, you must first load the client from:

http://shrimpware.com/SIS/DebugSIS.html

You must then log into the particle.io cloud via the Debug Client in exactly the same way that you logged into the SIS Client app. Likewise, you select the SIS Hub device in exactly the same way that you did using the SIS Client app. At this point, you will see a screen similar to figure 9, below:

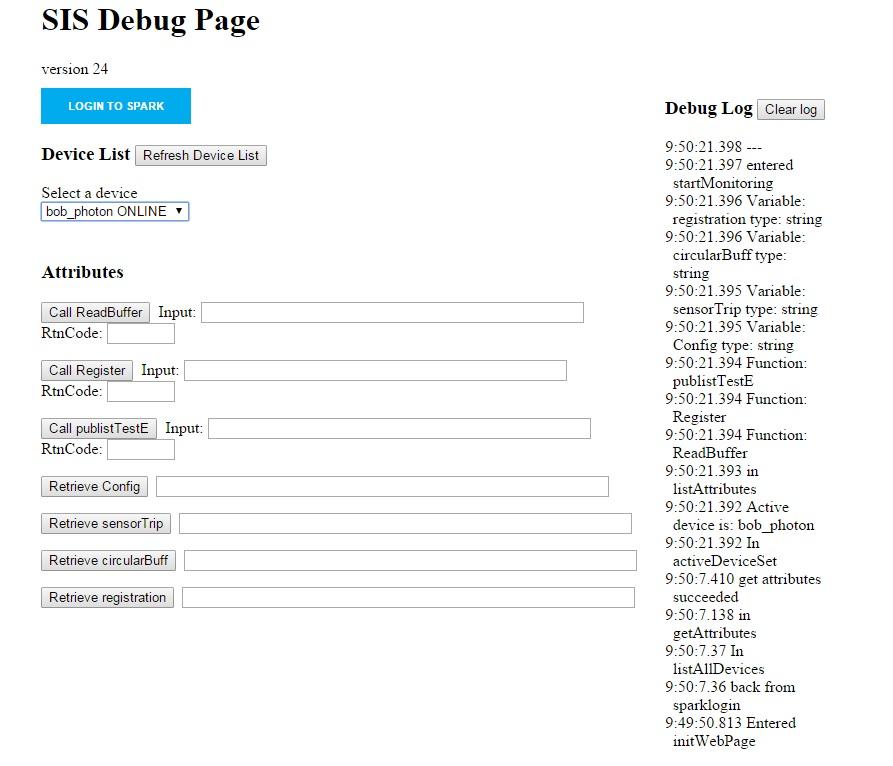
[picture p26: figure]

Page 18 of 23 | Copyright © 2015. Bob Glicksman and

Figure 9. Debug Screen.

Referring to figure 9: there are a series of command buttons under Attributes on the left hand side of the screen. Click on the button Retrieve Config to retrieve the configuration from the selected SIS Hub device. You will then see something similar to figure 10.

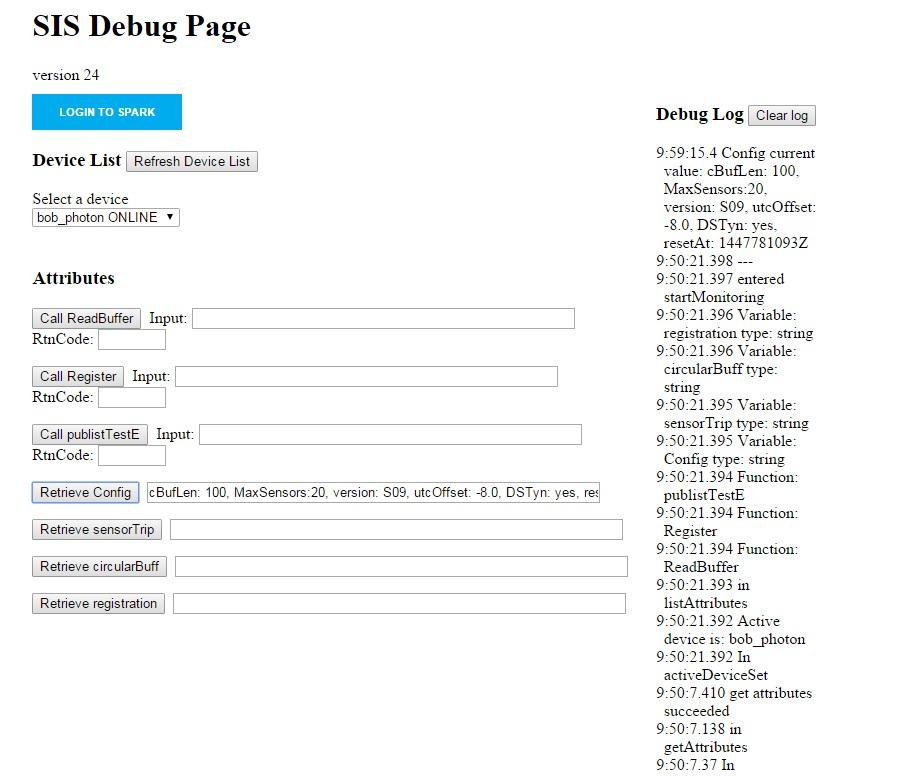
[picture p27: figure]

Page 19 of 23 | Copyright © 2015. Bob Glicksman and

Figure 10. Configuration Information from the SIS Hub.

Referring to figure 10, you can see information in the text box next to the Retrieve Config button. Examining this text box you can observe the “utcOffset” is set to “-8.0” and that “DSTyn” is set to “yes”.

These configuration parameters can be changed using the Call Register button and the text box directly to the right of it. To change the utcOffset parameter to Eastern Standard Time (offset = -5.0), type the following into this text box:

offset,-5.0

Make sure to type this exactly as shown above; no spaces, all lower case, and you must put the offset in as a number with a decimal point. Do not type the “enter” button, just the text, as shown. After typing this text in the text box, click the Call Register button. You will see something similar to figure 11.

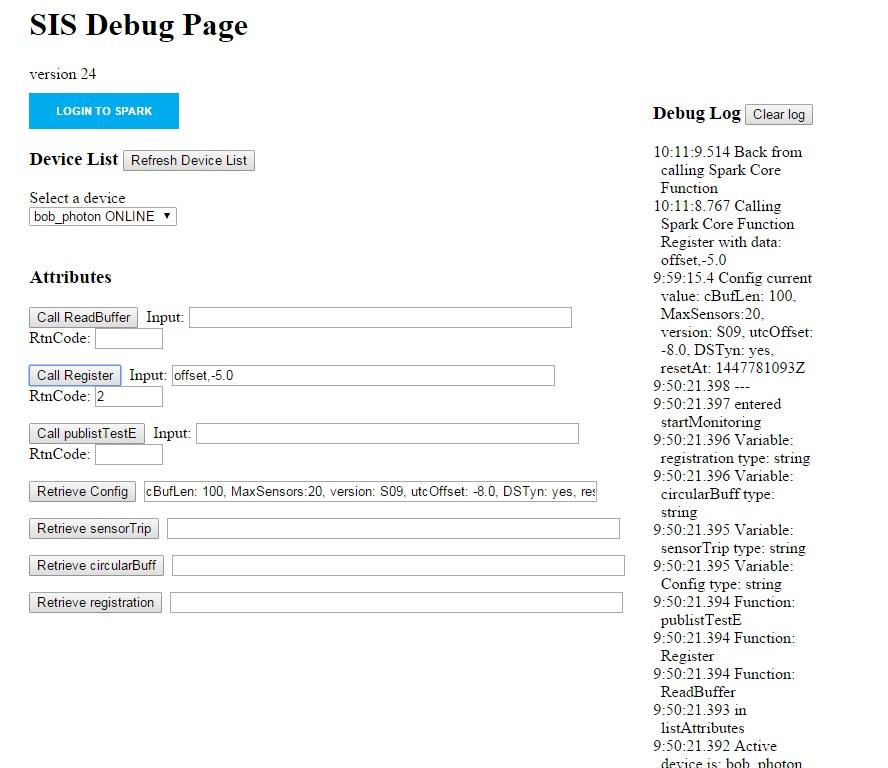
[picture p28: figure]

Page 20 of 23 | Copyright © 2015. Bob Glicksman and

Figure 11. Changing the UTC Offset.

A “RtnCode” of “2” indicates success. In order to verify this, click on Retrieve Config again. You should see something similar to figure 12.

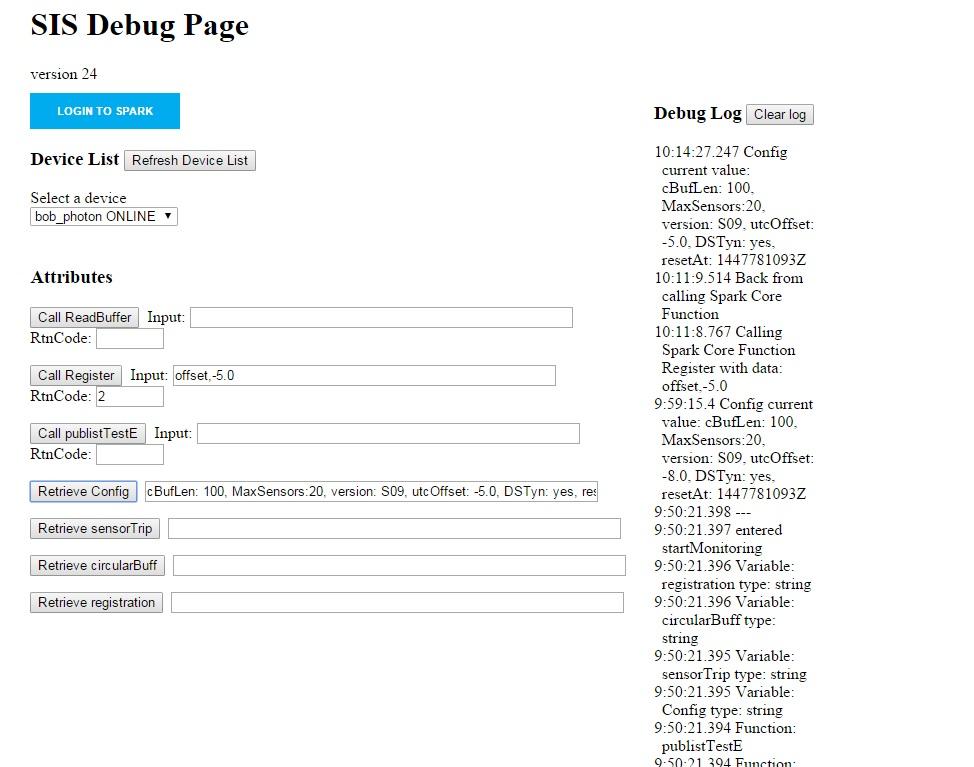
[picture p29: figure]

Page 21 of 23 | Copyright © 2015. Bob Glicksman and

Figure 12. Verifying the UTC Offset Change.

You can see that the UTC Offset has been changed to -5.0. However, this change is not yet stored in non-volatile memory, so the next time that the SIS Hub is reset, the old UTC Offset value will come back. If you want to store this new configuration persistently, replace the “Input” next to Call Register with the word:

store

Again, you must type this exactly as shown – all lower case and nothing else on the text box. You do not type the enter key. You click on Call Register and a “RtnCode” of “1” indicates success. See figure 13.

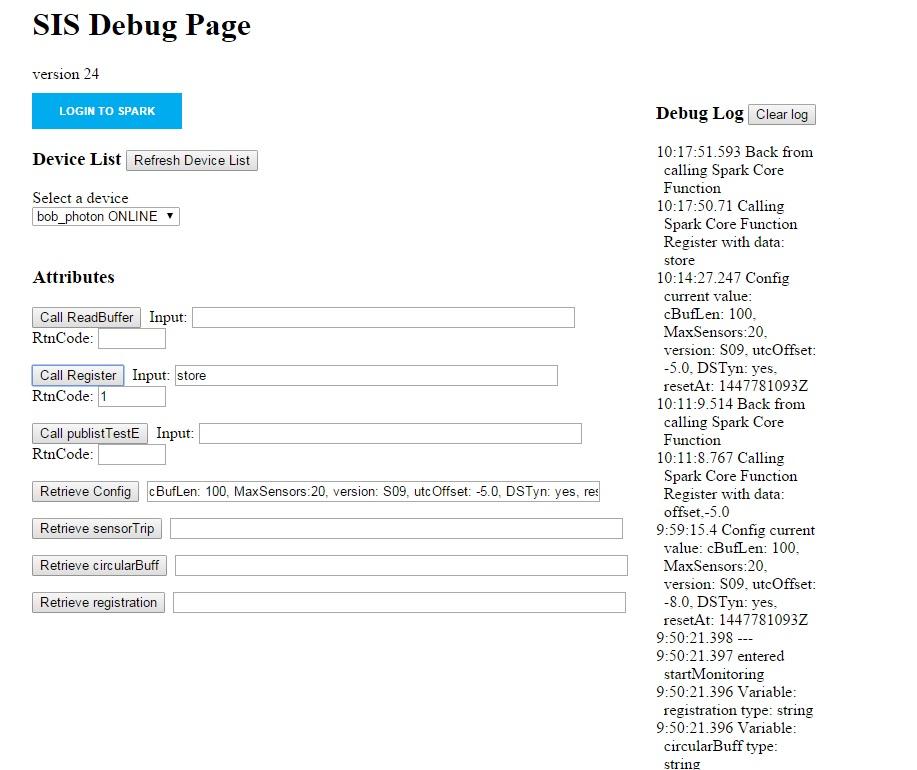
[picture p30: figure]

Page 22 of 23 | Copyright © 2015. Bob Glicksman and

Figure 13. Storing the New Configuration in Non-Volatile Memory.

If you want to change the DST parameter (e.g. from “yes” to “no”), type the following into the “Input” text box adjacent to Call Register:

DST,n

Type this exactly as shown, overwriting anything else in the text box. Do not type the enter key. Click on Call Register. A “RtnCode” of “2” indicates success. You can then click on Retrieve Config to verify the changed configuration, as shown in figure 14.

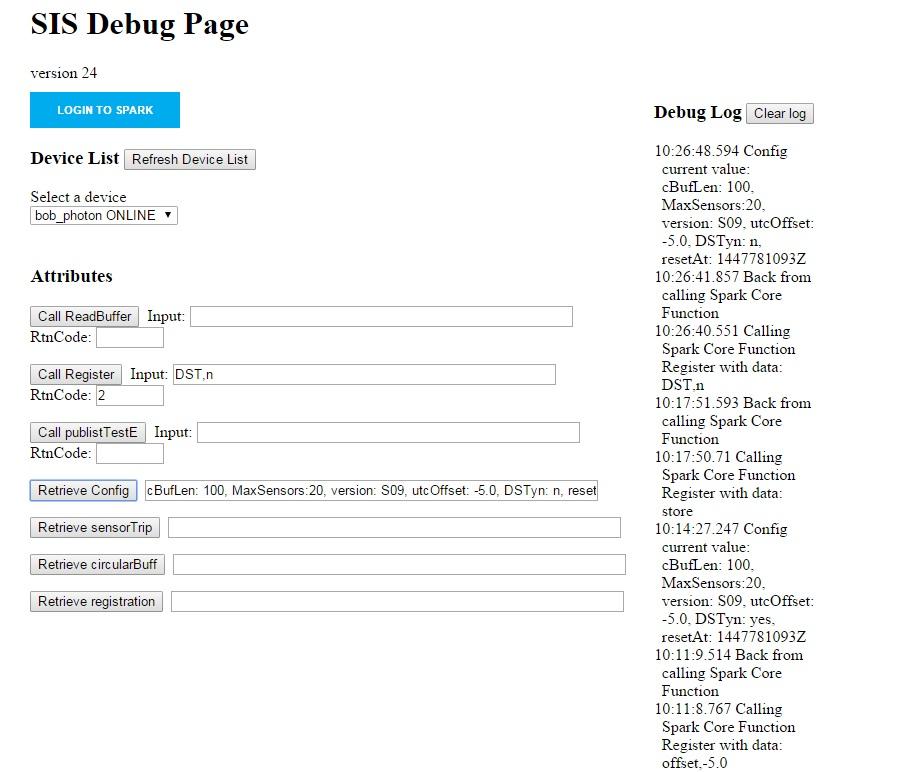
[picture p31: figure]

Page 23 of 23 | Copyright © 2015. Bob Glicksman and

Figure 14. Changing the DST Configuration.

Very Important: if you wish this new configuration to be stored in non-volatile memory, you must “store” it, as described above. Each time that you “store” the configuration, you are storing the entire configuration of the SIS Hub into non-volatile memory. Therefore, you may make multiple configuration changes (e.g. change the “utcOffset” and the “DST”) and then “store” it once after verifying all of your changes in the Retrieve Config text box.

The SIS Debug Client can be used to exercise all low level communication to/from the SIS Hub, including reading out the circular buffer, retrieving the latest sensor trip (registered or unregistered), changing/adding/deleting sensor registration, and logging all raw communication in the Debug Log. Instructions to perform these additional functions are beyond the scope of this document.

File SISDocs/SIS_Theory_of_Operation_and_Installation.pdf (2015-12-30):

Page 1 of 18 | Copyright © 2015. Bob Glicksman and Jim Schrempp. All rights reserved.

## SIS THEORY OF OPERATION AND INSTALLATION GUIDE

Bob Glicksman, Jim Schrempp Date: 12/29/2015

### Contents

NOTICE: Use of this document is subject to the terms of use described in the

document “Terms_of_Use_License_and_Disclaimer” that is included in this release package. This document can also be found at:

https://github.com/TeamPracticalProjects/SISProject/blob/master/SISDocs/Terms_of_Use_License_and_Disclaimer.pdf (https://github.com/TeamPracticalProjects/SISProject/blob/master/SISDocs/Terms_of_Use_License_and_Disclaimer.pdf)

Page 2 of 18 | Copyright © 2015. Bob Glicksman and
1. INTRODUCTION.

This document provides an overview of the Standalone Intelligent Sensor System (SIS). A thorough understanding of the information presented herein is necessary in order to properly install and use the SIS. This document also contains information about how to install an SIS system in a home.

SIS provides a low cost solution that allows family members and caregivers to monitor the daily living activities of an elderly or impaired person living alone at home. SIS is not a health or emergency monitoring system. There are plenty of systems already on the market to perform these types of functions. Rather, SIS is intended to help family members and caregivers monitor how a person living alone at home is performing the routine activities of daily living. Further information about the concept and purpose of SIS can be found in:

https://github.com/TeamPracticalProjects/SISProject/blob/master/SISOverview/SIS_Concept_Nov_2015.pdf (https://github.com/TeamPracticalProjects/SISProject/blob/master/SISOverview/SIS_Concept_Nov_2015.pdf)

2. SIS OVERVIEW.

2.1.SIS Architecture.

SIS uses inexpensive passive, wireless sensors to monitor a person’s activities when at home. The design of SIS is based upon the principle that routine activities of daily living are performed in different rooms or areas of the home. For example:

- Bedroom: sleeping and dressing.
- Bathroom: personal hygiene.
- Kitchen: food preparation.
- Dining Room: food consumption.
- Living/Family Room: recreation and socialization.

The following figure shows the architecture of SIS.

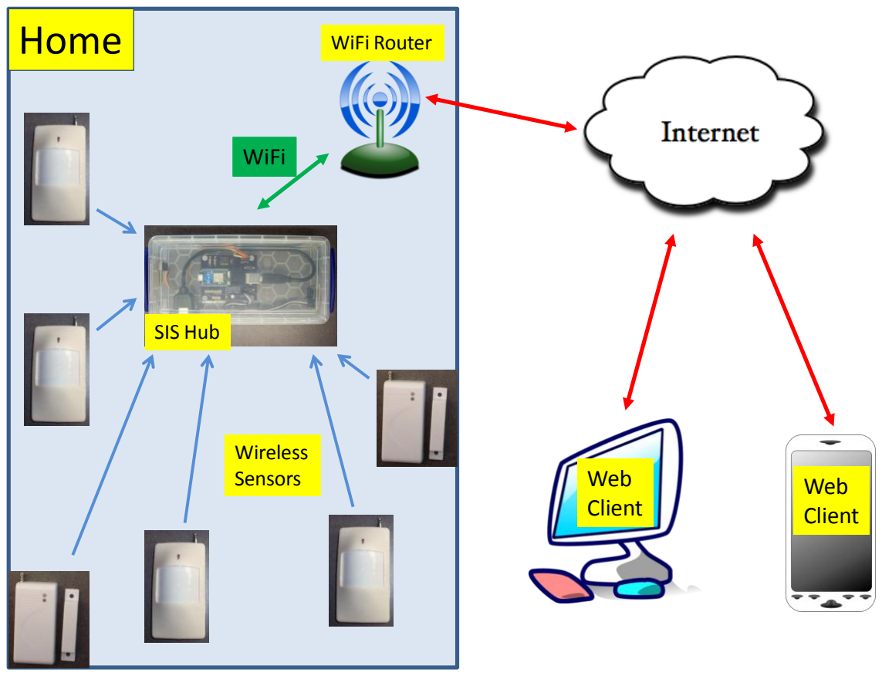
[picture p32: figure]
Home; SIS Hub; Web Client; Wireless; Sensors; Web; Client; WiFi Router; WiFi

Page 3 of 18 | Copyright © 2015. Bob Glicksman and

Figure 1. SIS Architecture.

Referring to figure 1: each home to be monitored requires one SIS Hub. The SIS Hub receives signals from various low cost wireless sensors placed around the home. The SIS Hub processes and interprets signals from the wireless sensors in order to create a time stamped log of meaningful events and inferences about the person’s activities. Family members and caregivers can monitor a person’s activities by reading out the log remotely, securely over the Internet, via a web-based client. The client is implemented as a web page using Javascript so that it can be run on any device that supports a web browser. Privacy is protected via encrypted communication over the Internet as well as the requirement to log in to a free “cloud” account in order to gain access to the SIS Hub log data.

SIS is designed to operate with no recurring costs. However, a WiFi connection to the Internet is necessary. If a WiFi connection to the Internet does not already exist in the home of the person being monitored, then it must be provided and paid for by the resident or family.

Page 4 of 18 | Copyright © 2015. Bob Glicksman and

2.2.SIS Hub.

One SIS Hub is required for the home of the person being monitored. The SIS Hub must be assembled from purchased parts. Assembly requires basic through hole soldering skills. Instructions for assembling the SIS Hub can be found at:

https://github.com/TeamPracticalProjects/SISProject/blob/master/SISDocs/SIS_Hub_PCB_Assembly_Instructions.pdf (https://github.com/TeamPracticalProjects/SISProject/blob/master/SISDocs/SIS_Hub_PCB_Assembly_Instructions.pdf)

The SIS Hub electronics may optionally be mounted in a rugged plastic box. Only simple hand tools are required for this construction. Instructions for this can be found at:

https://github.com/TeamPracticalProjects/SISProject/blob/master/SISDocs/SIS_Hub_Packaging_Assembly_Instructions.pdf (https://github.com/TeamPracticalProjects/SISProject/blob/master/SISDocs/SIS_Hub_Packaging_Assembly_Instructions.pdf)

Before the SIS Hub can be used, a free “cloud” account must be created at particle.io and this account must be used to upload operating software (“SIS Firmware”) to the Hub over the Internet. Complete instructions for establishing this account, connecting the Hub to the Internet and capturing it into this account, and uploading the firmware into the Hub can be found at:

https://github.com/TeamPracticalProjects/SISProject/blob/master/SISDocs/SIS_Firmware_Instal lation.pdf (https://github.com/TeamPracticalProjects/SISProject/blob/master/SISDocs/SIS_Firmware_Installation.pdf)

The “cloud” account at particple.io will thereafter be used to access the SIS Hub from anywhere, over the Internet, via a web based client. The web based client source code can be obtained from:

https://github.com/TeamPracticalProjects/SISProject/tree/master/SISSoftware/website

An instance of this website is available for you to use at:

http://www.shrimpware.com/SIS/

Please note that all access to the SIS data is from the web browser to the particle.io cloud. The site hosting the web pages (e.g. shrimpware.com) does not participate in this communication. (http://www.shrimpware.com/SIS/SIS_Client)

Instructions for using the SIS Client to configure an SIS installation are contained in section 5 of this document.

2.3.SIS Sensors.
SIS utilizes low cost, battery operated, low power, wireless sensors operating in either the 315 MHz or 433.92 MHz RF bands. These bands are internationally recognized for low power, unlicensed use. The SIS Hub contains two receivers, one for each band, so that sensors can be mixed and matched between these two bands within one SIS installation.

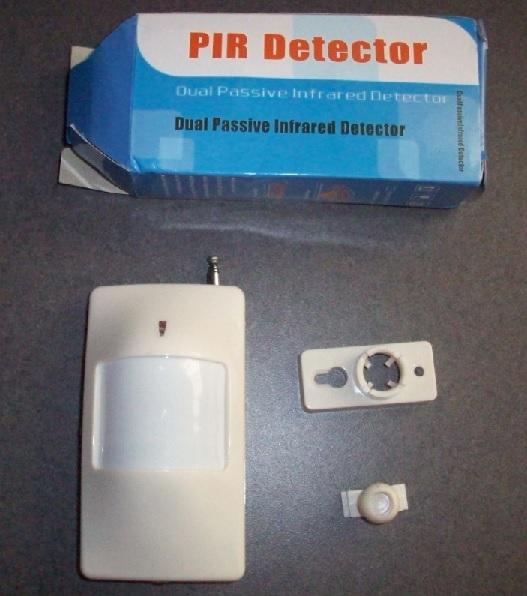
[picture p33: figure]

Page 5 of 18 | Copyright © 2015. Bob Glicksman and

In addition to the RF frequencies, wireless sensors compatible with SIS must operate using On/OFF keying (also called “OOK”, “ASK”, or “AM” modulation) and use protocols compatible with PT2262 or EV1527 chip sets. A list of known compatible sensors is included in this section, but many more can be found on sites like EBay and Amazon.com.

Each sensor you purchase comes with a pre-set 32 bit “trip code”. When the sensor is tripped this code is broadcast for a few seconds. While this trip code is not guaranteed to be unique to each sensor, as a practical matter the code can be used to identify a specific sensor from all other sensors.

PIR sensors: Proximity infrared (PIR) motion sensors are the most common types of sensors used within SIS. A typical sensor of this type is: 315 MHz PIR sensor for “My 99 Zone” alarm system. This sensor can be purchased from E-Bay, typically for less than $10:

http://www.ebay.com/itm/221068187723

Figure 2 shows the sensor and what comes in the box:

Figure 2. Typical PIR Sensor.

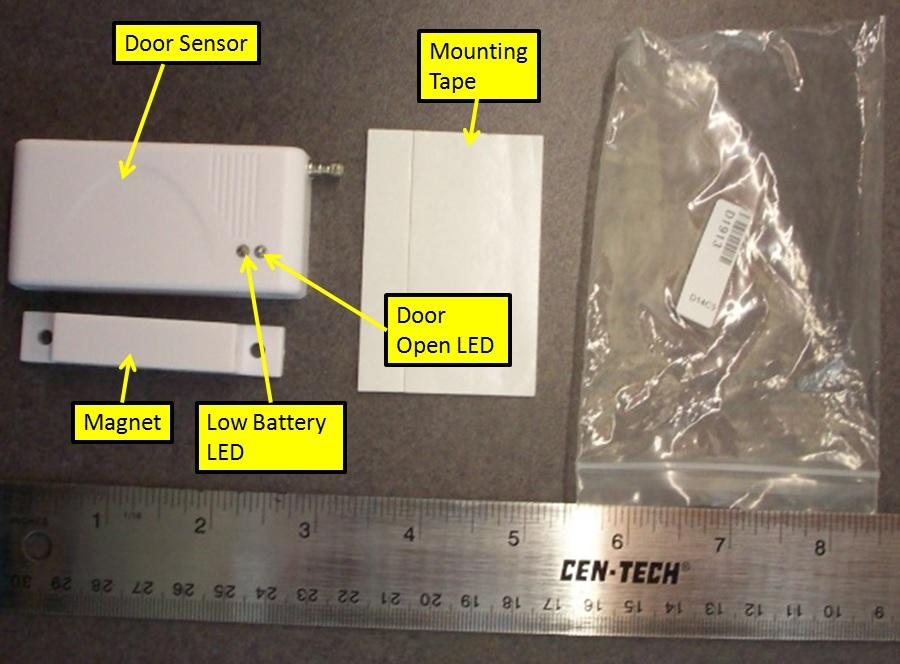
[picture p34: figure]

Page 6 of 18 | Copyright © 2015. Bob Glicksman and

PIR motion sensors are used inside of each room or area of the house where a person would normally perform some activity of daily living, such as sleeping, bathing, or eating. SIS is preconfigured to support up to 12 PIR sensors for activity sensing and up to 4 additional “misc” sensors (any type) per installation.

Door Sensors: Magnetic separation sensors are primarily used within SIS to detect opening of exterior doors through which a person will enter or exit the house. They may also be used on windows, cabinets or drawers to provide extra information about what the resident is doing. A typical sensor of this type is: 315 MHz magnetic door/window sensor for “My 99 Zone” alarm system. Purchased from E-Bay:

http://www.ebay.com/itm/370629635675

Figure 3 shows the sensor and what comes in the box:

Figure 3. Typical Magnetic Separation Sensor.

SIS is preconfigured to accept up to 4 exterior door sensors and up to 4 additional “misc” sensors (any type) per installation.

Misc. and Alarm/Alert Sensors. PIR motion sensors and Exterior Door sensors have special meaning within SIS. This is discussed further in “SIS Theory of Operation”, below. In addition

Page 7 of 18 | Copyright © 2015. Bob Glicksman and

to these special meaning sensors, SIS supports up to 3 “misc” sensors of any type whose sensor trips are simply logged but not further interpreted by the SIS software. SIS also supports up to one additional “alarm/alert” sensor which is a general purpose sensor of any type. The Alarm/Alert sensor is handled as an additional “misc” sensor but also publishes each sensor trip to the “cloud” so that it can be used e.g. to send an SMS text message to a registered user phone when it is tripped. Note that the Alarm/Alert sensor is NOT intended as an emergency notification – the notification service is not sufficiently reliable for this purpose.

Misc and Alarm/Alert sensors may be of any type that is compatible with SIS. This includes PIR and magnetic separation sensors described above. Other types of sensors that might be useful include:

Water level sensor: This sensor has a float that can detect if the water level reaches a certain point (e.g. in a toilet tank, indicating a flush). An example is: 433 MHz “Wireless Leak Detector” sensor for “my own GSM/PSTN alarm” system. Purchased from E-Bay:

http://www.ebay.com/itm/111049996563

Vibration sensor: This sensor can detect vibration due to a window breaking or perhaps sitting down in a chair. An example is:

http://www.ebay.com/itm/Wireless-Vibration-Break-Breakage-Glass-Sensor-Detector-433MHz-For-Alarm-System-/371225342804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 (http://www.ebay.com/itm/Wireless-Vibration-Break-Breakage-Glass-Sensor-Detector-433MHz-For-Alarm-System-/371225342804)

Keyfob Button: Various 1, 2 and 4 button keyfobs are available that are compatible with SIS. These sensors generate a compatible signal when a button on the keyfob is pressed, making them good candidates for Alarm/Alert types of sensors. Typical of these keyfobs are:

One button: http://www.adafruit.com/product/1392

Two button: http://www.adafruit.com/product/1391

Four button: http://www.adafruit.com/products/1095

Note that when purchasing one of the keyfobs, you do not need to purchase the corresponding receiver module. The SIS Hub is the receiver.

3. SIS THEORY OF OPERATION.
The SIS Hub software (“firmware”) receives and decodes signals from the 315 and 433.92 MHz receivers. The Hub software decodes, validates and processes sensor trip information according to how the sensor is registered within SIS. This process is described below. The Hub software works with the SIS Client app to register sensors for use within SIS, to store and maintain sensor

Page 8 of 18 | Copyright © 2015. Bob Glicksman and

registration and other configuration information, and to maintain a log of sensor trips, events, and inferences.

All entries in the SIS log are time stamped and sequenced to provide a meaningful readout by the SIS Client app. The SIS on-device log contains (up to) the most recent 100 entries since the SIS Hub was last reset. The SIS log contains the basic information upon which a family member or caregiver can evaluate the person living alone for how and when they are performing their routine activities of daily living. To this end, the log contains filtered and processed information that helps to make the log readable and understandable.

The SIS on-device log is stored in volatile memory. This means that if the SIS Hub is reset or if the power fails, the internal log information will be lost. The log should therefore be read out at least daily. If the log is reset, the sequence numbers of log entries are reset back starting from zero, and the time that power last was restored is displayed on the SIS Client app. Log entries are also published to the cloud as they are stored in the Hub and provision may be made, via an external cloud service (such as IFTTT.com), to record these entries in a more robust location, e.g. a Google spreadsheet in the cloud. See the User Manual for details:

https://github.com/TeamPracticalProjects/SISProject/blob/master/SISDocs/SIS_User_Manual.pd f (https://github.com/TeamPracticalProjects/SISProject/blob/master/SISDocs/SIS_User_Manual.pdf)

Note, however, that this cloud recording process is, itself, neither robust nor timely. Entries into a Google Docs spreadsheet may be significantly delayed or even skipped, given the uncontrollable nature of WiFi and Internet communication. Still, a cloud based log, such as a Google Docs spreadsheet is a good compromise between robustness to power failures and ease of implementation.

In order to understand how the SIS Hub software operates on wireless sensor data, it is important to define four terms: registration, sensor trips, events, and inferences.

Registration: All sensors that are installed in a home and are to be used within SIS must be registered. The SIS Client app provides an easy way to register sensors and associate these sensors with locations or functions within the home. The registration process also defines how a registered sensor trip is processed and interpreted within the SIS software. Unregistered sensors are ignored by SIS. This prevents SIS from responding to other sensors that may be close by (e.g. possessed by a neighbor) or just noise in the environment. Registration information is stored in non-volatile memory (EEPROM) on the SIS Hub. The Hub will remember sensor registration information even if the power is removed and subsequently re-applied.

Sensor trips: As mentioned above, the SIS has two radio receivers (315 and 433.92 MHz) that are constantly listening to the environment. The SIS software (firmware in the SIS Hub) responds to signals provided by these receivers. The software tries to decode and validate the signals according to PT2262 and EV1527 protocols. If a valid trip code is received, SIS then

Page 9 of 18 | Copyright © 2015. Bob Glicksman and

“filters” the code so that it cannot be received again for 5 seconds. This is necessary because the sensors generate their “trip code” over and over (perhaps 50 or 60 times) for several seconds in response to the sensor being tripped. Finally, SIS compares a valid and filtered trip code with its list of registered sensor trip codes to see if the code came from a registered sensor. Only if all of these conditions are met is the received sensor code determined to be a “sensor trip” for the SIS to log.

SIS processing of sensor trips depends upon how the sensor was registered within SIS:

Motion Sensor in a Room: If the sensor trip code came from one of the (up to) 12 registered room motion sensors, the sensor trip is not logged by itself, but is recorded and marked for further processing as a possible event and to draw possible inferences from.

Exterior Door Sensor: If the sensor trip code came from one of the (up to) 4 registered exterior door sensors, the sensor trip is not logged by itself, but is logged as an event and recorded and marked for further processing to draw possible inferences from.

Misc Sensor: If the sensor trip code came from one of the (up to) 3 registered “misc.” sensors, the sensor trip is immediately time stamped and logged. No further processing is applied to “misc” sensor trips.

Alarm/Alert Sensor: If the sensor trip code came from the one possible registered Alarm/Alert sensor, the sensor trip is immediately time stamped and logged. Furthermore, notification of the sensor trip is published to the particle.io cloud, from where it may be processed by an external service (e.g. IFTTT.com) to provide a user with an alert notification, such as an SMS text message to a mobile phone. See the User Manual for details:

https://github.com/TeamPracticalProjects/SISProject/blob/master/SISDocs/SIS_User_Manual.pd f (https://github.com/TeamPracticalProjects/SISProject/blob/master/SISDocs/SIS_User_Manual.pdf)

No further processing is applied to Alarm/Alert sensor trips.

Events: Events are sensor trips that have been further processed by the SIS Hub software before they are logged. The reason for processing these sensor trips further is to make the log entries more meaningful and relevant to understanding what a person living alone is doing, and when they are doing it. Sensors that are registered as interior motion sensors and sensors that are registered as external door sensors are subject to this further processing as follows:

Motion Sensor in a Room: Only the first trip of a particular motion sensor in a room is logged as an event. Once a particular motion sensor has been logged, it is “locked out” and will not be logged again until an “unlock” event occurs. “Unlock” events occur when either an exterior door sensor or another room’s motion sensor is tripped. This means that room motion sensor log entries record the time stamped movement of a person around the house (from room to room). This filtering greatly reduces the number of log entries associated with the motion sensors. The

Page 10 of 18 | Copyright © 2015. Bob Glicksman and

aim here is to record when a person moves from one room in the house to another room in the house, and thereby moves from performing one activity (e.g. personal hygiene) to another activity (e.g. eating).

Exterior Door Sensor: Each trip of an exterior door sensor is logged but this event is also recorded for further processing. When an exterior door trip is sensed, the lockout on the previous motion sensor is removed so that a subsequent trigger of that motion sensor will also be recorded. For example, assume that there is a back door (with an exterior door sensor) in the dining room, along with a room motion sensor in the dining room. When a person first enters the dining room from another room in the house, the PIR sensor trip will cause the event of entering the dining room to be logged and the dining room sensor will be locked out. As the person continues to move around in the dining room the sensor will continue to trip, but no further dining room events will be logged. If the person then opens the back door, this event will be logged and the dining room sensor will be unlocked. If the person then re-enters the back door, they will again trip the back door sensor (logged event) and will then trip the dining room PIR sensor (another logged event). The timed sequence of these logged events will tell the story of:

- When the person entered the dining room, and how long they stayed there until the back door was opened.
- When the back door was first opened (assumed exiting the house – room first and then door) and when the back door was again opened (how long the person was out of the house).
- When the person re-entered the house (because the door sensor tripped and then the PIR tripped afterward).

Inferences: Inferences are additional log entries that are drawn from a timed pattern of room motion sensor trips and/or exterior door sensor trips. SIS computes and logs four types of inferences:

- “Person is home”. Initially (upon SIS Hub reset), SIS does not know if a person is at home or not. However, if an exterior door sensor trip occurs followed by a room motion sensor trip within 10 minutes, then it can be assumed that the person came into the house via the door and a “Person is home” inference is logged.
- “Person is away”. Conversely, if an exterior door sensor trip happens and no interior motions sensors are tripped within 10 minutes, it is assumed that the person has left the house and a “Person is away” inference is logged.
- “No motion detected”. If no room motion sensor or exterior door sensor is tripped when the person is assumed to be home for a period of one hour, a “No motion detected” inference is logged.

Page 11 of 18 | Copyright © 2015. Bob Glicksman and

It should be noted that the motion sensors are made for burglar alarms and their sensitivity can vary greatly from unit to unit and also can vary greatly with small adjustments in placement. A person may fall asleep in the bedroom or in an easy chair in the living room and may or may not trip the room sensor while they are asleep. In addition to sensor inadequacies, people vary greatly in how much they move while asleep, and motion varies with the stage of sleep as well. The “No motion detected” inference may be helpful in determining if a person is asleep or active within a room, but extreme care should be exercised in trying to read too much into this inference.

- “Multiple persons detected”. SIS log entries can only be used well if there is one and only one person in the home. If another person comes to visit or to work in the house, then the log could fill up with extraneous data. SIS sensors do not provide any reliable way of knowing how many people are in the house at any given time. The SIS cannot accurately report on the activity of more than one person in the home.

The SIS software attempts to detect if multiple persons are present by making this inference if any two room motion sensors are tripped within 2 seconds of each other. This will work only if the room motion sensors do not have overlapping fields of view, are placed only in rooms/areas of the house where meaningful activities take place, and are not placed in transit areas such as hallways and staircases. The “Multiple persons detected” inference is not only logged, but it also locks out all other room motion sensor events from logging. This lockout persists until one of the exterior door sensors is tripped. At this point, it is assumed that the additional person/people have left the house, and the lockout is removed. However, a subsequent trip of two room motion sensors within 2 seconds of each other will again apply the lockout (and again log the inference).

4. SIS INSTALLATION GUIDE.

4.1.Installation Planning Overview.
You should be thoroughly familiar with the SIS Theory of Operation (above) before you begin planning your deployment. Careful thought should be given to what information you want to see in the SIS log. Generally speaking, you want events in the log to correspond to the resident’s daily living activities that you wish to keep tabs on. This requires a mapping of these activities to rooms or locations within the home. Sometimes, there are several rooms that an activity may take place in; e.g. recreation and socialization can take place in the living room, family room or even the dining room. We suggest making a list of the activities that you want to monitor and review the layout of the home to assess which rooms/locations these activities may take place in. Note that a change in the resident’s mood might change their activities; e.g. they may read in the living room or bedroom when they are peaceful and happy but watch TV in the family room if

Page 12 of 18 | Copyright © 2015. Bob Glicksman and

they become sad or depressed. It is likely that detection of these sorts of mood changes is what has prompted you to install and SIS to begin with.

4.2. PIR Motion Sensor Installation.
A motion sensor should be placed in each room or location where a person will spend time doing something. You will want to place a motion sensor in each room or location that represents an activity that you want to monitor. However, if the resident moves to a room or location that has no sensor in it, SIS will not record this in the log, and the log will falsely indicate that the person is still in the room where the last sensor trip happened. Therefore, a PIR motion sensor should probably be installed in any room or location where the resident is likely to linger, regardless of whether the activity associated with that room is of interest. This is because the room that the resident left before entering this new location may represent an important activity (e.g. sleeping) and you may want to assess how long they were performing this activity of interest.

Do not place motion sensors in any room, location or area of the house that is used strictly for transit. These locations include stairways, hallways, corridors, and walk-thru closets (unless the resident dresses in the closet and this activity is of interest). Note that SIS is NOT an emergency system and is NOT intended to sense to respond to falls or other such emergencies.

When placing motion sensors in a room or other location, it is very important to ensure the following:

- The field of view of the sensor covers the room or location sufficiently so that the resident is certain to trigger it if they enter and linger in the room. The PIR motion sensors that we have evaluated have little LEDs that light up when the sensor is tripped, so it is easy to assess sensor coverage in a room.
- The field of view of the sensor must not spill outside of the room or location and into a transit area. If it does, the sensor may trip (and an event logged) on a transit. Even more importantly, such transit sensor trips may trigger the “multiple persons” inference and lock out further logging of events. When placing PIR sensors in a room, it is best to mount them in a corner, up high, on the wall where the entry door is, or on an intersecting wall, so that the PIR field of view can be aimed inside the room and not spill outside the doorway.
- Some homes contain open “great rooms” where one open space may serve several functions (e.g. dining and recreation). In such instances, it may not be possible to aim multiple PIRs with non-overlapping fields of view inside the great room to distinguish between these multiple possible activities. In this instance, a single PIR sensor should be used to cover the great room, and perhaps a “misc” sensor positioned to give further information (e.g. a vibration sensor on an easy chair used for TV viewing in the great room). This way, the log can reflect that e.g. the resident has entered the great room but

Page 13 of 18 | Copyright © 2015. Bob Glicksman and

has not sat in the TV viewing easy chair (so perhaps is in the dining part of the great room).

4.3.Exterior Door Separation Sensor Installation and Planning.
Generally speaking, there should be one separation sensor placed on each exterior door of the home. SIS cannot monitor activities outside of the home, so it is important to know when a person has left the home and when they have re-entered the home.

A possible exception to this rule is an exterior door that leads to an enclosed patio or yard with no exit from the property from that patio or yard. In this case, opening the exterior patio door may not imply that the person has left the house; only that they are out in the patio. You should carefully consider what you want logged when deciding on whether to place a separation sensor on such a door, and if you do place a separation sensor on a patio door, whether to register it as an “exterior door sensor” or as a “misc.” sensor. Please review the SIS Theory of Operation to understand the differences between these types of registrations in SIS’ processing of sensor data.

4.4.Other Sensor Installation and Planning.
You can pretty much place sensors that are registered as “misc.” or “Alarm/Alert” anywhere and of any type that you want. Placement of these sensors is not critical because SIS only logs sensor trips for these and does not process them for events or inferences. The intent of “misc.” sensors is to add some information to the log that may be of interest but is not provided by PIR motion sensors and exterior door separation sensors. An example of this might be a vibration sensor on an easy chair or a water level sensor inside a toilet tank (to log flushes of the toilet).

4.5.Wireless Range Considerations and Mitigation.
SIS sensors operate wirelessly, at low power, and thus have limited range. Sensor trip transmissions can be received several hundred feet away in open air, but the range is much more limited inside a house. It is very difficult to predict the range of a sensor in a general home environment, as the range is affected by walls, interior wiring and plumbing within walls, cabinets and closets and what is in them, etc. Generally speaking, our testing has shown that SIS sensors can communicate with the Hub over distances of 50 – 100 feet, both horizontally and vertically. This adequately covers most homes, both single and multiple story.

Since SIS sensors communicate wirelessly with the SIS Hub, the latter will work best if it is located in some central location within the home. The Hub should be located somewhere where there is AC power but is otherwise not obstructed by walls, closets, plumbing or wiring, etc. Note, however, that the SIS Hub must also communicate wirelessly (via WiFi) with the home’s Internet router or WiFi access point.

SIS has been designed for low cost. As such, the sensors are very inexpensive. The SIS sensors only transmit codes; they have no receiver capability. They operate on simple protocols that do not support mesh networking or repeaters. It is therefore essential that the sensors can

Page 14 of 18 | Copyright © 2015. Bob Glicksman and

communicate directly with the Hub. If making this happen requires that the Hub be located outside of range of the home’s WiFi router or access point, then consideration should be given to either moving the latter or extending the WiFi range via access points or other commercially available WiFi range extenders.

The WiFi module on the particle.io Photon used in the SIS hub has provision for adding a u.FL antenna to it. We have not tested this capability to see if the WiFi range can be meaningfully extended with such an external antenna. Additional details can be found at:

https://docs.particle.io/datasheets/photon-datasheet/

Most SIS-compatible sensors have a telescoping antenna. Our testing has shown that extending the antenna may improve the transmission range of the sensor, but the added range is usually marginal. The 315 MHz and 433.92 MHz receivers in the SIS Hub have provision to solder in a ¼ wave antenna wire, and sometimes come with such an antenna wire installed and coiled up. Our testing has shown that the addition of a coiled wire antenna does not extend the range very much. We have not tested a straight up ¼ wave antenna wire for range extension.

The SIS Hub builder should be aware that we have found receivers for sale that look very similar to the ones in our parts list, but we found these receivers have a more limited range. The sensors we recommend have a small metal can on them.

4.6.Wireless Sensor Battery Life Considerations.
The SIS sensors are wireless and battery operated. This makes them very easy to install. The sensor is simply taped or screwed into a wall or door jam.

The sensors that we have purchased and tested usually come with batteries installed. You may need to remove a paper insulator between the battery and its electrical contact that the manufacturer has placed there to keep the battery fresh. Sometimes the sensors we have received had old or leaking batteries in them. Batteries for the sensors listed in this document are:

- PIR motions sensor: ordinary 9 volt “transistor” battery.
- Door, water level and vibration sensors: 23A battery (12 volts).
- Keyfob: 2 ea 2016 lithium coin cell batteries.

Sensor battery life is primarily determined by how many times the sensor is tripped. Each time the sensor is tripped, it transmits a signal for several seconds and these transmissions are, by far, the largest drain on the batteries. As the batteries are drained, the wireless range of the sensors may be degraded. It is therefore important to test the sensors periodically and to replace the batteries when they are getting weak. Our testing has shown that PIR motion sensor batteries may need to be replaced every 6 months or so and other sensor batteries can last at least one year. Keyfob battery life will, of course, be highly dependent upon how often the keyfob button is pushed.

Page 15 of 18 | Copyright © 2015. Bob Glicksman and

None of the sensors that we have tested with SIS have any provision to transmit a battery low indication. Therefore, SIS has no way to know (no way to report) when a sensor battery may need replacement. Some of the sensors have a battery low LED on them, but our testing has shown these indications to be unreliable. It is best simply to replace the batteries often to ensure that the sensors always have the maximum sensitivity and range.

Obviously, battery replacement should be considered when placing sensors in the home. The sensors should be as accessible as possible, given the other placement considerations noted above.

5. CONFIGURING YOUR SIS USING THE SIS CLIENT APP.

This SIS Client app is used to register your sensors once they have been installed and tested by tripping them and observing the sensor’s trip LED. This section provides an overview of the registration process. Detailed information about using the SIS Client app can be found in the User Manual:

https://github.com/TeamPracticalProjects/SISProject/blob/master/SISDocs/SIS_User_Manual.pd f (https://github.com/TeamPracticalProjects/SISProject/blob/master/SISDocs/SIS_User_Manual.pdf)

Figure 4, below, is a snapshot of the SIS Client app screen after the user has logged in and selected their hub device from the dropdown list. Note that the SIS Client screen presentation varies with the size and orientation of the user’s screen or browser window; therefore, your screen may look a little bit different than figure 4.


Page 16 of 18 | Copyright © 2015. Bob Glicksman and

Figure 4. SIS Client App Screen.

Referring to figure 4: there are four buttons shown under “Commands” in the center of the screen:

- “Show the log of sensor events” Show: selecting Show reads out the log from the SIS Hub and displays the log entries under “Command Output” on the right side of the screen.
- “Clear Current SIS Config” Clear: selecting Clear clears out all sensor registration information from the SUS Hub. This means that all possible sensors are unregistered. You should only use Clear when moving the SIS Hub to a different house with a completely different set of sensors to register.
- “Show the current sensor config” Refresh: selecting Refresh will display the trip codes for all currently registered sensors by the room that they are registered, in the sensor registration table below the Commands.

Page 17 of 18 | Copyright © 2015. Bob Glicksman and

Below Commands is a table that displays the current sensor registration for the SIS Hub. The Current Code column contains the currently registered trip code for each sensor by location. A code of “0” means that there is no sensor registered for that location. In order to register a new sensor for that location, the current code should be “0”. If it is not “0”, click the reset button for that location first. A “?” means that the Client has not yet retrieved the sensor configuration for that sensor. A “--” means that the Client is currently working to update the sensor registered for that location.

To register a sensor for a location, first click the add button for that location. You will get a pop up dialog box indicating that you need to trip the sensor for the new location. After tripping the sensor, click the button “New Sensor Was Tripped”. At this point, the pop up dialog box will disappear and the sensor trip code for the sensor just tripped will be shown in the sensor registration table (after a second or so Internet delay).

Any particular sensor trip code can only be registered for one location. If you try to add a sensor that is already configured for another location you will get an error message when you click the “New Sensor Was Tripped” button. There are typically two causes of this error. You, or someone else, might have tripped a different sensor that is already configured in the SIS. In this case, just try to add your new sensor again. The second cause is that you are moving a sensor from one location to another. In this case you must first reset the previous sensor location so that the SIS will unregister the sensor trip code. Then you can add the sensor to the new location

In order to register all sensors in the house, go to each location with your WiFi laptop, tablet or smartphone running the SIS Client app and repeat this process until all sensors are registered. If you wish to test the sensor registration, move from location to location and trip each sensor (as verified by the sensor’s trip LED). At any time, you can select the “Show the log of sensor events” Show button and observe the time stamped log under the Command Output column of the SIS Client app display. Thereafter, every new sensor trip will be processed by SIS according to the description in the “Theory of Operation” section, above.

Note: The SIS Client app stores the registration information into non-volatile storage
(EEPROM) every time that you reset or add a new sensor. EEPROM has a limited life (about 100,000 write cycles), which is much more than sufficient for any intended use of SIS. Just be sure not to overuse this capability to avoid wearing out the EEPROM chip on the SIS Hub.

After registering sensors, you may wish to clear out the SIS Hub’s log, as the log will contain extraneous information from the registration process. You can do this in one of two ways:

- Press the RESET button on the Photon module within the SIS Hub
- Unplug the SIS Hub from AC power, wait 10 seconds and plug it back in.

After resetting or repowering the SIS Hub, wait until it completes its setup cycle (the Photon begins to breathe cyan and the D7 LED then flashes 6 times). The log should be cleared out.

Page 18 of 18 | Copyright © 2015. Bob Glicksman and

Note, however, that sensors will trip as you exit the premises. You might want to make note of the last sequence number in the log after you exit the premises. All subsequent log entries will then be due to activities of the resident of the house.

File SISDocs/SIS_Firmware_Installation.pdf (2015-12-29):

© 2015 Jim Schrempp and Bob Glicksman All Rights Reserved

# Instructions for Installing the SIS Firmware

© Jim Schrempp and Bob Glicksman date: 11/17/2015

Purpose
Overview
1.Power up the Photon and connect to the internet What is the Photon Telling You Now?
The Photon is Blinking Blue
2. Verify the Photon
Verify Photon
Blink an LED
3. Install the Firmware
Create a Web Based Project Download the SIS Firmware
Add the Firmware to Your Web Project Verify the SIS Firmware
Flash the Firmware
4. Verify the SIS

# Purpose

This document will guide the maker of a Standalone Intelligent Sensor System (SIS) to install the SIS firmware into the SIS Hub.

# Overview

The SIS is fully documented on Git Hub at https://github.com/TeamPracticalProjects/SISProject

NOTICE: Use of this document is subject to the terms of use described in the

document “Terms_of_Use_License_and_Disclaimer” that is included in this release package. This document can also be found at: https://github.com/TeamPracticalProjects/SISProject/blob/master/SISDocs/Terms_of_Use_License_and_Disclaimer.pdf (https://github.com/TeamPracticalProjects/SISProject/blob/master/SISDocs/Terms_of_Use_License_and_Disclaimer.pdf)

The SIS Hub uses a processor from particle.io as the local compute resource. The SIS currently uses the Photon, but is intended to be compatible with the future Electron. This document will refer to the Photon but should be the same process for the other processors.

You can install the SIS firmware into your Photon at any point in the development process. This document will assume that you have completed the build of your SIS printed circuit board and installed the Photon into that board. Instructions for doing so can be found at:

https://github.com/TeamPracticalProjects/SISProject/blob/master/SISDocs/SIS_Hub_PCB_Assembly_Instructions.pdf (https://github.com/TeamPracticalProjects/SISProject/blob/master/SISDocs/SIS_Hub_PCB_Assembly_Instructions.pdf)

Many steps of the process involve services from particle.io and Git Hub. These instructions were accurate at the time they were created, but we have no control over these other providers; the reader may need to adjust to new realities.

The process consists of several steps.

1. Power up the Photon and connect it to the internet
2. Verify the Photon
3. Install the Firmware
4. Verify the SIS

# 1.Power up the Photon and connect to the internet

Before starting this step, open a browser window and bring up the particle.io dashboard:

https://dashboard.particle.io/user/logs
If you don’t have a particle.io user account, you will have to create one. Once you are at the actual dashboard it should say something about “waiting for events.” Leave the browser window open.

Connect one end of a USB cable to the large connector on the SIS PCB and the other end to a reliable power supply (USB power; +5 volts DC regulated). Wait 30 seconds and look at the dashboard. If it shows that your “device came online” then you can move on to step 2 - you’ve obviously worked with this Photon before.

## What is the Photon Telling You Now?

Note the multi-color LED on the Photon board.

Breathing Cyan: If the Photon is “breathing cyan” then it is connected to the internet and you can move on to step 2.

Blinking Blue: If this is the first time you’ve used your Photon it should be blinking blue; this means it is ready for WiFi configuration.

Blinking Green: If you have already used your Photon, then it will probably be blinking green. If the Photon is blinking green then hold down the mode button on the Photon board until the LED starts blinking blue.

## The Photon is Blinking Blue

It is ready for WiFi configuration.

Install the particle.io app on your smart phone and follow its directions to configure your Photon with your local WiFi credentials. When you are done, the Photon should be breathing cyan. If not, go to www.particle.io and troubleshoot the situation.

# 2. Verify the Photon

There are a number of ways to get your SIS firmware into your Photon. We are going to use the simplest way.

Open a new web browser tab (don’t close the dashboard tab from step 1) and navigate to the particle.io build site:

https://build.particle.io

## Verify Photon

On the far left of the build site is a vertical menu with several icons. Hover over the icons until you find the one that is “devices”; it should be a round icon similar to a reticule. Click the icon and a list of devices that are registered to your Particle.io account is displayed. Find the Photon you are using for your SIS Hub. If your Photon is breathing cyan, then it should have a little cyan dot next to its name to show that it is on-line. If your device has stopped breathing cyan, or the little cyan dot is not displayed, then work with the particle.io community to figure out what’s wrong.

If your Photon has a little cyan dot next to it, then select it. A gold star should show up next to the name or your Photon.

## Blink an LED

Go to the left hand vertical menu again. Hover over icons until you find one named “code”. It should be this symbol: < >. Click it and a list of programs is displayed. Click on the sample app “blink an LED”. Now on the left hand menu click the lightning bolt to push this application to your Photon. Watch your Photon. It should blink magenta a few times. If this is the first time you’ve connected your Photon to particle.io then it may get a firmware update and it might blink magenta for a while and reset itself several times. Go have coffee and come back in 10 minutes. At this time you want to wait until your Photon is once again breathing cyan. It should also be blinking the blue D7 LED that is on the Photon board. You have now verified your Photon is working correctly.

# 3. Install the Firmware

## Create a Web Based Project

In the particle.io build site click the button “create new app”. Give it the name SIS. In the right hand pane where you see a few lines of sample code, delete all of it.

## Download the SIS Firmware

The latest SISFirmware is stored on the public site Git Hub. There are many ways to use Git Hub. We will use the most simple way possible.

In any browser on any system, go to

https://github.com/TeamPracticalProjects/SISProject/tree/master/SISSoftware

On the right hand side of the screen should be a button labeled “download”. Click it to download the latest version of the SIS Project files.

Once the download is complete, unzip the file and navigate to the Firmware folder. Open the file named SaratogaSIS.ino in a text editor.

## Add the Firmware to Your Web Project

Copy all the text from the SaratogaSIS.ino file into your clipboard. Make sure that you copy everything.

Now paste the text into the code editor on the particle.io build site where you previously erased all the code.

## Verify the SIS Firmware

On the left hand vertical menu find the “compile” icon; it should be a checkmark in a circle. Click it and make sure the SIS firmware compiles without error.

## Flash the Firmware

On the left hand vertical menu find the “flash” icon; it should be a lightning bolt. Click it.

Now watch your Photon. It should blink magenta a few times (perhaps so fast you’ve missed it?) and then restart including flashing green as it connects to your WiFi network again.

Once the Photon begins to breath cyan you should see the D7 LED blink six times and then go dark. This is the SIS firmware telling you that it is alive! If the D7 LED remains solid blue, then the SIS firmware encountered some problem during start up.

# 4. Verify the SIS

To verify that the SIS firmware is working correctly you should try to read its configuration. The SIS is managed through a Javascript client that runs in your browser. The files for this client are included in the SIS Project files in the “website” folder.

We currently maintain a web site that hosts these files so you can test your SIS right away. Navigate your web browser to

http://www.shrimpware.com/SIS

Once there click on the link for Standard Configuration. On that page you can log in to your particle.io account and then select your Photon. The web page will attempt to read your SIS configuration through the particle.io cloud. If the section “Configuration Report From Selected Device” shows you information, then your SIS is working! See the SIS User Manual for additional instructions on using the SIS Client app:

https://github.com/TeamPracticalProjects/SISProject/blob/master/SISDocs/SIS_User_Manual.p df (https://github.com/TeamPracticalProjects/SISProject/blob/master/SISDocs/SIS_User_Manual.pdf)

At this point you should have a working SIS running for you! Congratulations. Your next step is to configure the SIS with sensors for your particular installation. You should now read the SIS Theory of Operation and Installation Manual:.

https://github.com/TeamPracticalProjects/SISProject/blob/master/SISDocs/SIS_Theory_of_Operation_and_Installation.pdf (https://github.com/TeamPracticalProjects/SISProject/blob/master/SISDocs/SIS_Theory_of_Operation_and_Installation.pdf)

-end-

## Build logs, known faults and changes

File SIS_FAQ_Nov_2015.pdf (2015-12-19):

# SIS FAQ

Bob Glicksman and Jim Schrempp 11/22/2015

### Contents

1. OVERVIEW.
1.1. What is SIS?
1.2. What does SIS stand for?
1.3. What problem(s) is SIS intended to solve?
1.4. Aren’t there many solutions already on the market to address these problems?
1.5. What is the current status of SIS?
1.6. What kinds of sensors can SIS accommodate?
1.7. What is the cost of a fully functional SIS product?
1.8. What is the next step?
2. Technical FAQ.
2.1. What is the technical status of SIS?
2.2. What are the specifications for wireless sensors that are compatible with SIS?
2.3. What are the requirements for using wired sensors with SIS?
2.4. How does SIS communicate over the Internet?
3. OTHER FAQ.
3.1. Who are the developers of SIS?

1. OVERVIEW.

### 1.1. What is SIS?

SIS is the Standalone Intelligent Sensor Platform. SIS utilizes low cost wireless sensors and a custom built “hub” to monitor and log the daily activities of a person living alone. The SIS log can be read out by a family member or caregiver to monitor an elderly or chronically ill person’s activities for abnormal behaviors that may indicate a change in the person’s ability to live alone. The SIS log is available to the caregiver on any Internet connected device that supports a Javascript-enabled web browser.

SIS has additional capabilities to host an “alert” button that can send a text message to a caregiver or family member. SIS can also be configured to record log information on a Google Drive spreadsheet or other “cloud” application.

SIS is relatively cheap and easy to deploy without any recurring monthly charges.

### 1.2. What does SIS stand for?

SIS stands for “Standalone Intelligent Sensor” Platform. SIS is “standalone” in the sense that it connects to the Internet via WiFi, requiring only the free Particle Cloud (particle.io) service to enable the SIS to communicate with any Internet connected device. SIS is “Intelligent” because it contains an advanced 32 bit microcontroller that is programmed to draw inferences from a number of sensors that are connected to SIS. SIS is a “sensor platform” because it integrates multiple, inexpensive wireless sensors and can be extended by a computer hobbyist.

### 1.3. What problem(s) is SIS intended to solve?

SIS allows a caregiver or family member to remotely monitor the activities of an elderly or chronically ill person who is living alone. The person’s activities (as indicated by movement throughout the home) are logged and available for real time review by the caregiver over the Internet. The caregiver can thereby ascertain whether the resident continues their normal and routine activity pattern, or has a change in their activity pattern than might indicate a decline in their physical or mental condition.

### 1.4. Aren’t there many solutions already on the market to address these problems?

SIS is intended to fill a market gap between standalone, single function Internet of Things (IoT) devices and complex, expensive, multi-sensor services. SIS is intended to be used in and around the home to sense and record events and to be capable of drawing inferences from multiple sensor events. Single function IoT sensors and multi-sensor services that currently exist in the marketplace all require expensive cloud services to fuse data from multiple sensors into useful information. SIS can perform the sensor data fusion internally and provide access to both raw and processed information to any Internet connected device. No services involving recurring costs are needed except for a WiFi internet connection.

### 1.5. What is the current status of SIS?

SIS is released and available to anyone under an open source, non-commercial license. SIS is not a commercial product. The user must purchase and install the equipment and must build the SIS hub from a set of instructions involving simple through-hole soldering and hand tool assembly. The SIS release package contains detailed instructions for assembling the SIS, loading firmware into the SIS hub, installing sensors and configuring SIS, and using SIS to monitor the resident’s activities.

SIS is an open source project. We expect that additional uses can be found for the SIS through hardware and software enhancements. We are interested in any enhancements to this basic system that people may find useful.

### 1.6. What kinds of sensors can SIS accommodate?

SIS is designed to use inexpensive, battery powered, wireless sensors that transmit “trip codes” over the 315 MHz and 433.92 MHz RF bands. These bands are available internationally for use with low power, unlicensed transmitters.

SIS sensors utilize on-off keying (OOK) modulation and transmit codes compatible with PT2262 and EV1527 chip sets. Compatible sensors can be purchased over the Internet from EBay and Amazon.com for under $10 each. Sensors that we have tested include: proximity infrared (PIR) motion sensors, magnetic door/window separation sensors, water level sensors, vibration sensors, and keyfob pushbuttons. Other types of compatible sensors are available for purchase: e.g. smoke and fire detectors.

It is possible to attach all manner of wired sensors to the SIS hub’s internal microcontroller digital and analog ports, albeit the firmware would need to be modified to support these. The SIS firmware is open source and we encourage people to make or suggest enhancements to the current design. Additionally, we have developed Arduino software that produces SIS compatible wireless signals, so that people can invent their own wireless sensors if they wish to do so.

### 1.7. What is the cost of a fully functional SIS product?

SIS hardware is costs $100 to $200, depending upon the number and types of sensors used. Parts cost for the SIS hub is under $50 and sensors cost between $3 for a wireless magnetic separation sensor to under $8 for a wireless PIR motion sensor.

### 1.8. What is the next step?

Please look at our open source documentation at:

https://github.com/SISProject

2.Technical FAQ.

### 2.1. What is the technical status of SIS?

SIS is released under open source, non-commercial license. Complete documentation can be found at:

https://github.com/SISProject

### 2.2. What are the specifications for wireless sensors that are compatible with SIS?

SIS is currently designed and tested with sensors using On-Off Keying (OOK) modulation operating in the 315 MHz and 433.92 MHz bands. These bands are popular because they are available worldwide for unlicensed low power transmission. SIS can decode signals from sensors that use the PT2262/2272 protocol and the EV1527 protocol for encoding sensor address and data information. Typical wireless sensors in attractive packaging that conform to these specifications can be purchased on ebay for under $10 each. Since SIS contains an advanced microcontroller, it could be extended to decode additional wireless protocols, as needed.

### 2.3. What are the requirements for using wired sensors with SIS?

The SIS hub printed circuit board has been designed to provide access to some of the internal microcontroller’s analog and digital I/O ports. External signal conditioning and/or level shifting circuitry may be required between sensors and the SIS microcontroller. Additionally, the SIS firmware needs to be modified to properly support additional types of sensors and different or altered SIS applications. We are interested in additional applications for SIS, whether the ideas are for us to implement or modifications made by other people to our open source design.

### 2.4. How does SIS communicate over the Internet?

SIS requires access to WiFi to communicate over the Internet. SIS currently supports IEEE 802.11 a, b, g and n. SIS supports WPA2, WPA, WEP and no encryption. SIS works on WiFi home networks and can communicate through NAT and firewalls common to home and small office WiFi routers. A free account with particle.io is needed to provide the cloud services that connect SIS to the public Internet. Additional services, such as Android and iOS notification, SMS texting and voice notification can be provided via the free IFTTT service.

3. OTHER FAQ.

### 3.1. Who are the developers of SIS?

The developers of SIS are Bob Glicksman and Jim Schrempp. Bob is a retired electrical engineer with 42 years of experience in electronic system development. Jim is a software developer, entrepreneur, web master and product designer/builder. Bob and Jim have developed many products independently and have co-developed the “Pill Reminder”. See https://github.com/jschrempp/PillReminder for details about the Pill Reminder.

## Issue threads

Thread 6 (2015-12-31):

OpenCloseTx

BobGlicksman, 2015-12-31:
The original version of this software created a "sensor" that would send out one code when a button is pressed and another code when the button is released.  This code formed the basis for building a generic SIS-compatible sensor.  The original code was replaced by an altered version that repeatedly sent out codes for testing (TestBeacon).  This altered version is not usable as the basis for creating a generic SIS sensor and it has issues (such as using the particle time library vs millis() which is compatible with Arduino and other platforms and has 1 ms resolution vs 1 second resolution of the time library).  A more usable and corrected version of TestBeacon is also in this repository.

Because of the above, I suggest that the original OpenCloseTx code be restored under this name.  We can either eave the TestBeacon code in the repository or remove it.  The argument for removing it is that it was a test tool for receiver range testing and not meaningful to external users of this repository.

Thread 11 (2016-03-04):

Client should test that the device has SIS firmware installed

jschrempp, 2016-03-04:
I suggest if the config routine fails to return a reasonable config we should alert the user that the device may not be running SIS Hub firmware.

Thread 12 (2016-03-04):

Could register same sensor code twice

jschrempp, 2016-03-04:
1. trip a new sensor
2. SIS report unknown sensor
3. add sensor to SIS config
4. no other sensor is tripped
5. SIS reports same previous sensor code as unknown sensor
6. add same sensor code to SIS config

Suggested fix: When a sensor code is added to the SIS config the firmware should clear the sensor trip buffer.

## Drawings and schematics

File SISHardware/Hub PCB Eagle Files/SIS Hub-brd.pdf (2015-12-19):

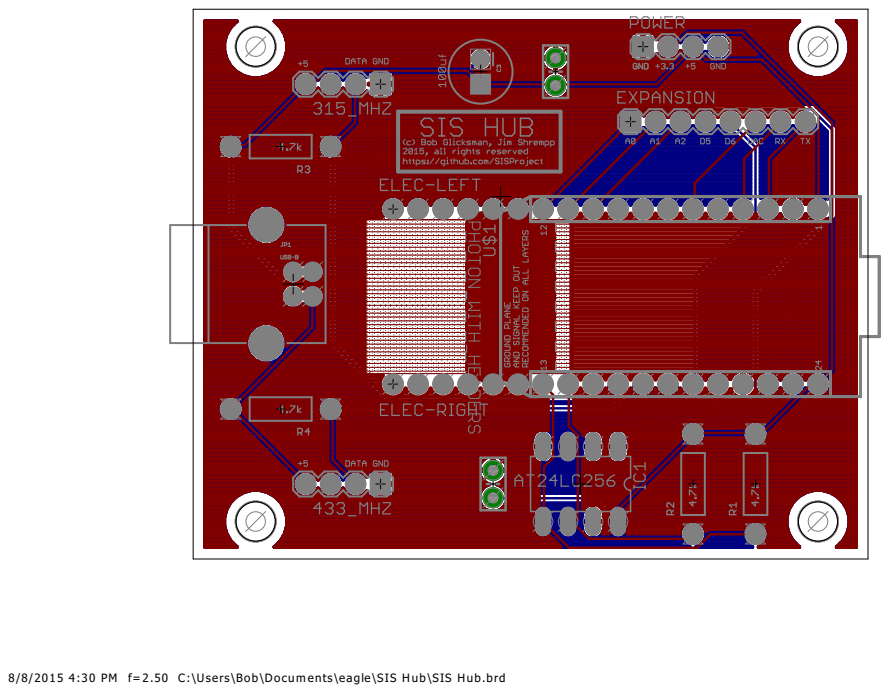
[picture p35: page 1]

8/8/2015 4:30 PM f=2.50 C:\Users\Bob\Documents\eagle\SIS Hub\SIS Hub.brd

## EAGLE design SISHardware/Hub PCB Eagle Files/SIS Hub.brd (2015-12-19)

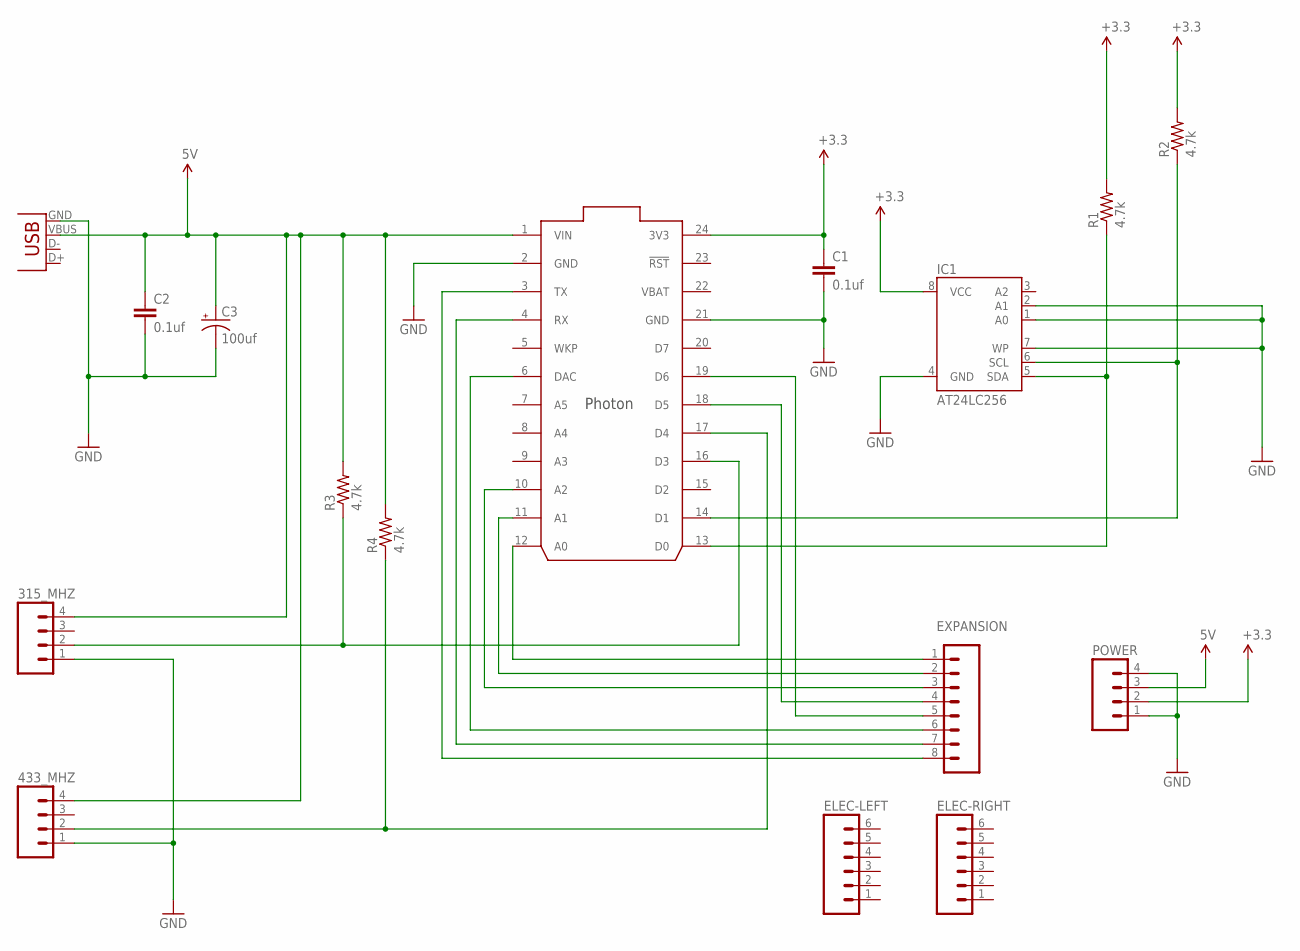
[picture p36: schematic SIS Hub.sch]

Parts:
315_MHZ, 433_MHZ: M04PTH; 1X04
C1, C2: 0.1uf; CAP-PTH-SMALL-KIT
C3: 100uf; CPOL-RADIAL-100UF-25V
ELEC-LEFT: M06NO_SILK_FEMALE_PTH; 1X06_NO_SILK
ELEC-RIGHT: M06NO_SILK_FEMALE_PTH; 1X06_NO_SILK
EXPANSION: M08SILK_FEMALE_PTH; 1X08
IC1: AT24LC256; DIL08
JP1: USB-B; USB-B-PTH
POWER: M04PTH; 1X04
R1, R2, R3, R4: 4.7k; AXIAL-0.4
U$1: PHOTON_WITH_HEADERS; PHOTON

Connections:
5V: 315_MHZ.4, 433_MHZ.4, C2.1, C3.1 (+), JP1.VBUS, POWER.3, R3.P$2 (2), R4.P$2 (2), U$1.1 (VIN)
GND: 315_MHZ.1, 433_MHZ.1, C1.2, C2.2, C3.2 (-), IC1.1 (A0), IC1.2 (A1), IC1.4 (GND), IC1.7 (WP), JP1.GND, POWER.1, POWER.4, U$1.2 (GND), U$1.21 (GND)
unnamed: IC1.5 (SDA), R1.P$1 (1), U$1.13 (D0)
unnamed: IC1.6 (SCL), R2.P$1 (1), U$1.14 (D1)
unnamed: 315_MHZ.2, R3.P$1 (1), U$1.16 (D3)
unnamed: 433_MHZ.2, R4.P$1 (1), U$1.17 (D4)
unnamed: EXPANSION.1, U$1.12 (A0)
unnamed: EXPANSION.4, U$1.18 (D5)
unnamed: EXPANSION.8, U$1.3 (TX)
unnamed: EXPANSION.7, U$1.4 (RX)
unnamed: EXPANSION.6, U$1.6 (DAC)
unnamed: EXPANSION.3, U$1.10 (A2)
unnamed: EXPANSION.2, U$1.11 (A1)
unnamed: EXPANSION.5, U$1.19 (D6)
VBAT: U$1.22 (VBAT)
VCC: C1.1, IC1.8 (VCC), POWER.2, R1.P$2 (2), R2.P$2 (2), U$1.24 (3V3)

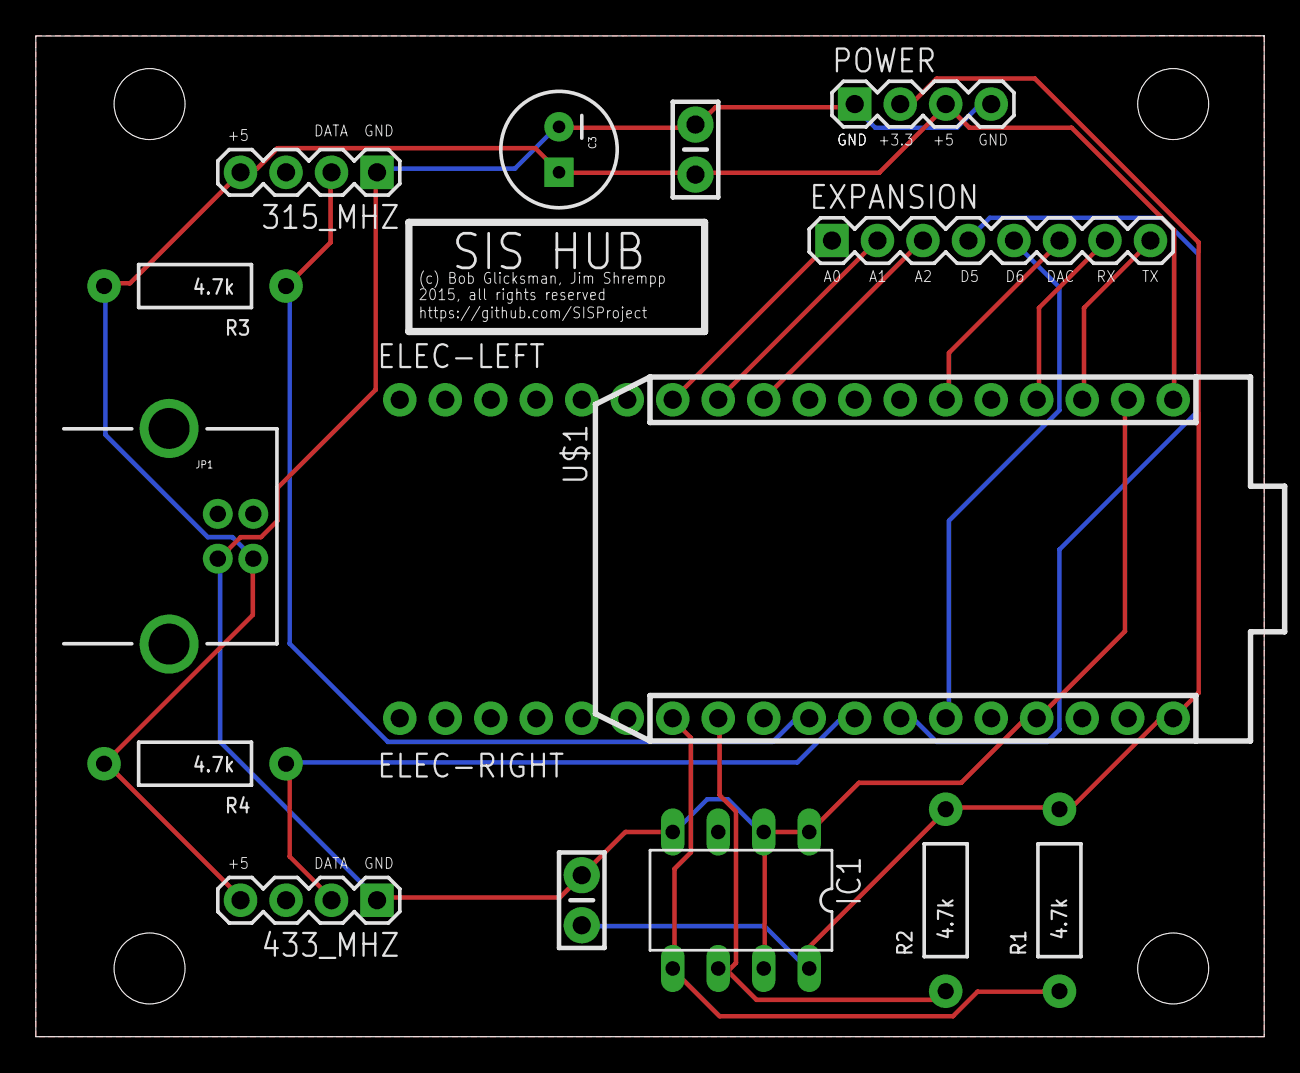
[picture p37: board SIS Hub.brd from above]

Board: 2 copper layers, 68.6 x 55.9 mm, 16 parts (0 on the bottom side), 15 nets.

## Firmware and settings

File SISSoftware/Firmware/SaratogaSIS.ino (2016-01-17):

//#define SEND_EVENTS_TO_WEBPAGE // if on will send the events needed for the
                                 // config web page to display live events
//#define TESTRUN
//#define DEBUG                   // turns on Serial port messages
#define DEBUG_LED                 // enables LED toggling in toggleD7LED()
#define D7LED_DELAY 200           // how long to wait when toggling LED for debugging
//#define DEBUG_TRIP
//#define DEBUG_EVENT
//#define DEBUG_ADVISORY
//#define DEBUG_COMMANDS
#define photon044                 // when present, enables functions that only work with 0.4.4 or higher
#define CLOUD_LOG
//
// Temporary fix for I2C library issue with Photon
#ifdef PLATFORM_ID
    #include "i2c_hal.h"
#endif
/***************************************************************************************************/
// saratogaSIS: SIS firmware - this is the software that is upoaded to the SIS Hub and performs
// sensor protocol decoding, sensor trip code processing, logging and cloud communication.  Compile
// this code and upload (flash) it to your Photon or other particle.io device.
//
//  This software has been extensively tested with the particle.io Photon.  It will run on the
// particle.io Core; however, the Core may run out of RAM unless the circular buffer size is
// reduced from 100 to 25.  This software is also intended ro run on the partcile.io Electron;
// however, the Electron is not available for testing as of this release.
//
//  Use of this software is subject to the Terms of Use, which can be found at:
//  https://github.com/TeamPracticalProjects/SISProject/blob/master/SISDocs/Terms_of_Use_License_and_Disclaimer.pdf
//
//  This software uses code extracted from the Arduino RC-Switch library:
//    https://github.com/sui77/rc-switch
// Portions of this software that have been extracted from RC-Switch are subject to the RC-Switch
// license, as well as the the SIS Terms of Use.
//
//  Version 1.01.  12/30/15.
const String VERSION = "1.01";   	// current firmware version
//
//  (c) 2015 by Bob Glicksman and Jim Schrempp
/***************************************************************************************************/

/************************************* Global Constants ****************************************************/

const int INTERRUPT_315 = 3;   // the 315 MHz receiver is attached to interrupt 3, which is D3 on an Spark
const int INTERRUPT_433 = 4;   // the 433 MHz receiver is attached to interrupt 4, which is D4 on an Spark
const int WINDOW = 200;    	// timing window (+/- microseconds) within which to accept a bit as a valid code
const int TOLERANCE = 60;  	// % timing tolerance on HIGH or LOW values for codes
const unsigned long ONE_DAY_IN_MILLIS = 86400000L;	// 24*60*60*1000
const int MAX_WIRELESS_SENSORS = 20;
const unsigned long FILTER_TIME = 5000L;  // Once a sensor trip has been detected, it requires 5 seconds before a new detection is valid
const int BUF_LEN = 100;     	// circular buffer size.
const int MAX_PIR = 11;      	// PIR sensors are registered in loc 0 through MAX_PIR.  Locations MAX_PIR + 1 to
                            	//  MAX_WIRELESS_SENSORS are non-PIR sensors
const int MAX_DOOR = 15;       // Sensors > MAX_PIR and <= MAX_DOOR are assumed to be exit doors.
const int ALARM_SENSOR = 19;  // When this sensor is tripped, publish an SISAlarm
const int MAX_SUBSTRINGS = 6;   // the largest number of comma delimited substrings in a command string
const byte NUM_BLINKS = 2;  	// number of times to blink the D7 LED when a sensor trip is received
const unsigned long BLINK_TIME = 300L; // number of milliseconds to turn D7 LED on and off for a blink
const int CONFIG_BUFR = 32; 	// buffer to use to store and retrieve data from non-volatile memory
const String id = "SIS-2015";   // the ID value for a valid config in non volatile memory
const String DOUBLEQ = "\"";

//  For I2C eeprom configuration
const int VIRTUAL_DEVICE_SIZE = 4096;   // divide device up into virtual eeproms 4K bytes each
const int MAX_VIRTUAL_DEVICES = 8;  	// 32 K bytes device = 8 pages of 4K each
const int VIRTUAL_DEVICE_NUM = 0;   	// use the first virtual device - change if it wears out

// additional global constants for Saratoga SIS Test
const unsigned long MULTI_TIME = 2ul;   	// 2 second interval to detect multiple persons
const unsigned long AWAY = 600ul;       	// 10 * 60 = 600; ten minutes for declaring away
const unsigned long COMATOSE = 3600ul;  	// 60*60 = 3600; 1 hour for for declaring no movement
const String messages[] = {             	// additional log messages for this application
                        	"No one is home",
                        	"Person is home",
                        	"No movement",
                        	"Multiple persons"
                      	};
const byte UKN = 0;     	// unknown
const byte HOME = 1;    	// person is home
const byte NOT_HOME = 2;	// person is not home

/************************************* Global Variables ****************************************************/
volatile boolean codeAvailable = false;  // set to true when a valid code is received and confirmed
volatile unsigned long receivedSensorCode; // decoded 24 bit value for a received and confirmed code from a wireless sensor
volatile unsigned int codeTimes315[52];  // array to hold times (microseconds) between interrupts from transitions in the received data
                         	//  times[0] holds the value of the sync interval (LOW).  HIGH and LOW times for codes are
                         	//  stored in times[1] - times[49] (HIGH and LOW pairs for 24 bits).  A few extra elements
                         	//  are provided for overflow.
volatile unsigned int codeTimes433[52];  // array to hold times (microseconds) between interrupts from transitions in the received data
                         	//  times[0] holds the value of the sync interval (LOW).  HIGH and LOW times for codes are
                         	//  stored in times[1] - times[49] (HIGH and LOW pairs for 24 bits).  A few extra elements
                         	//  are provided for overflow.
volatile unsigned int *codeTimes;  // pointer to 315 MHz or 433 MHz codeTimes array based upon the interrupt.
time_t resetTime;       	// variable to hold the time of last reset

   	//	Sensor registration data is held in parallel arrays.
String sensorName[] =      	{ "unregistered S0",
                             	"unregistered S1",
                             	"unregistered S2",
                             	"unregistered S3",
                             	"unregistered S4",
                             	"unregistered S5",
                             	"unregistered S6",
                             	"unregistered S7",
                             	"unregistered S8",
                             	"unregistered S9",
                             	"unregistered S10",
                             	"unregistered S11",
                             	"unregistered S12",
                             	"unregistered S13",
                             	"unregistered S14",
                             	"unregistered S15",
                             	"unregistered S16",
                             	"unregistered S17",
                             	"unregistered S18",
                             	"unregistered S19"
                           	};

unsigned long activateCode[] = { 0,   	// UNREGISTERED SENSOR
                             	0,	// UNREGISTERED SENSOR
                             	0,	// UNREGISTERED SENSOR
                             	0,	// UNREGISTERED SENSOR
                             	0,	// UNREGISTERED SENSOR
                             	0,	// UNREGISTERED SENSOR
                             	0,   	// UNREGISTERED SENSOR
                             	0,      // UNREGISTERED SENSOR
                             	0,      // UNREGISTERED SENSOR
                             	0,      // UNREGISTERED SENSOR
                             	0,      // UNREGISTERED SENSOR
                             	0,      // UNREGISTERED SENSOR
                             	0,      // UNREGISTERED SENSOR
                             	0,      // UNREGISTERED SENSOR
                             	0,      // UNREGISTERED SENSOR
                             	0,      // UNREGISTERED SENSOR
                             	0,      // UNREGISTERED SENSOR
                             	0,      // UNREGISTERED SENSOR
                             	0,      // UNREGISTERED SENSOR
                             	0	// UNREGISTERED SENSOR
                           	};

unsigned long lastTripTime[MAX_WIRELESS_SENSORS];	// array to hold the last time a sensor was tripped - for filtering purposes
unsigned long upcount = 0L; // sequence number added to the circular buffer log entries

	// other data that needs to be stored in non-volatile memory
String utcOffset = "-8.0";	// Pacific Standard Time
String observeDST = "yes";	// no" if locale does not observe DST

	// variable to hold the virtual eeprom device used to store the config
int eepromOffset;

	// array to hold parsed substrings from a command string
String g_dest[MAX_SUBSTRINGS];

	// Strings to publish data to the cloud
String sensorCode = String("");
String g_bufferReadout = String("");
char cloudMsg[80];  	// buffer to hold last sensor tripped message
char cloudBuf[90];  	// buffer to hold message read out from circular buffer
char registrationInfo[80]; // buffer to hold information about registered sensors

String cBuf[BUF_LEN];   // circular buffer to store events and messages as they happen
                        // Expected format of the string stored in cBuf is:
                        // TYPE,SEQUENCENUMBER,INDEX,EPOCTIME
                        // where
                        //    TYPE is A (advisory) or S (sensor)
                        //    SEQUENCENUMBER is a monotonically increasing global (eventNumber)
                        //    INDEX is into sensorName[] for type sensor
                        //          or into messages[] for type advisory
                        //    EPOCTIME is when the entry happened
                        // see cBufInsert(), cBufRead(), readFromBuffer(), logSensor(), logMessage()

int head = 0;       	// index of the head of the circular buffer
int tail = 0;       	// index of the tail of the buffer
int g_numToPublish = -1; // Number of entries in cBuf[] that remain to be published to spark cloud.
                         // This is incremented when events are added to the cBuf[] and decremented
                         // when an entry is published to the spark cloud.

char config[120];    	// buffer to hold local configuration information
long eventNumber = 0;   // grows monotonically to make each event unique


#if defined(DEBUG_EVENT) || defined(DEBUG_ADVISORY) || defined(DEBUG_COMMANDS)
	const unsigned long FILTER_TIME_UNREGISTERED = 5000L; // same as above, but for unregistered sensors
	unsigned long lastUnregisteredTripTime = 0;
	String debugLogMessage = String("junk"); // used by define DEBUG sections
#endif

// Additional globals for Saratoga SIS Test
int lastPIR = -1;   	// last PIR to trip - initialize to invalid value
time_t lastPIRTime = 0; 	// trip time of the last PIR to trip
time_t lastDoorTime = 0;	// trip time of the last Door sensor to trip
boolean lastSensorIsDoor = false;   // for door then PIR detection
boolean supress = false;	// multiple person suppression flag
byte personHome = UKN;  // initialize to unknown status
boolean comatose = false;   // patient is not moving

/**************************************** setup() ***********************************************/
void setup()
{
  // Use D7 LED as a test indicator.  Light it for the time spent in setup()
  pinMode(D7, OUTPUT);
  digitalWrite(D7, HIGH);

  // select virtual device on the eeprom
  if(VIRTUAL_DEVICE_NUM < MAX_VIRTUAL_DEVICES)
  {
    eepromOffset = VIRTUAL_DEVICE_NUM * VIRTUAL_DEVICE_SIZE;
  }
  else
  {
    eepromOffset = MAX_VIRTUAL_DEVICES - 1;
  }

  toggleD7LED();

	// initialize the I2C comunication
  Wire.setSpeed(CLOCK_SPEED_100KHZ);
  Wire.stretchClock(false);
  Wire.begin();

  toggleD7LED();

  #ifdef DEBUG
	 Serial.begin(9600);
  #endif

  pinMode(INTERRUPT_315, INPUT);
  pinMode(INTERRUPT_433, INPUT);

  attachInterrupt(INTERRUPT_315, isr315, CHANGE);   // 315 MHz receiver on interrupt 3 => that is pin #D3
  attachInterrupt(INTERRUPT_433, isr433, CHANGE);   // 433 MHz receiver on interrupt 4 => that is pin #D4

  toggleD7LED();

  // restore the saved configuration from non-volatile memory
  restoreConfig();

  toggleD7LED();

  // wait for the Core to synchronise time with the Internet
  while(Time.year() <= 1970 && millis() < 30000)
  {
  	delay(100);
    Spark.process();
  }

  if (Time.year() <= 1970)
  {
    reportFatalError(3);
    //never returns from here
  }

  toggleD7LED();

  // Publish local configuration information in config[]
  resetTime = Time.now();    	// the current time = time of last reset
  publishConfig();

  // Make sensorCode and cBufreadout strings available to the cloud
  Spark.variable("Config", config, STRING);
  Spark.variable("sensorTrip", cloudMsg, STRING);
  Spark.function("ReadBuffer", readBuffer);
  Spark.variable("circularBuff", cloudBuf, STRING);
  Spark.variable("registration", registrationInfo, STRING);
  Spark.function("Register", registrar);

  // Publish a start up event notification
  Spark.function("publistTestE", publishTestE); // for testing events

  toggleD7LED();

  // Initialize the lastTripTime[] array
  for (int i = 0; i < MAX_WIRELESS_SENSORS; i++)
  {
  	lastTripTime[i] = 0L;
  }


#ifdef DEBUG
  Serial.println("End of setup()");
#endif

// turn off the D7 LED at the end of setup()
digitalWrite(D7, LOW);

}

/************************************ end of setup() *******************************************/

/**************************************** loop() ***********************************************/
void loop()
{

  boolean knownCode = false;
  static unsigned long lastTimeSync = millis();  // to resync time with the cloud daily
  static boolean blinkReady = true;  // to know when non-blocking blink is ready to be triggered

  // Test for received code from a wireless sensor
  if (codeAvailable) // new wireless sensor code received
  {
	int i; 	// index into known sensor arrays

	// Test to see if the code is for a known sensor
	knownCode = false;
	for (i = 0; i < MAX_WIRELESS_SENSORS; i++)
	{
    	if ( (receivedSensorCode == activateCode[i])  )
    	{
        	knownCode = true;
        	break;
    	}
	}

	// If code is from a known sensor, filter it
	if (knownCode == true)	// registered sensor was tripped
	{
    	unsigned long now;
    	now = millis();
    	if((now - lastTripTime[i]) > FILTER_TIME) // filter out multiple codes
    	{
        	// Code for the sensor trip message
        	sensorCode = "Received sensor code: ";
        	sensorCode += receivedSensorCode;
        	sensorCode += " for ";
        	sensorCode += sensorName[i];

        	#ifdef DEBUG
            	Serial.println(sensorCode);  // USB print for debugging
        	#endif

        	#ifdef DEBUG_EVENT
            	debug = "Event: ";
            	debug += String(sensorName[i]);
            	publishDebugRecord(debug);
        	#endif

        	sensorCode.toCharArray(cloudMsg, sensorCode.length() + 1 );  // publish to cloud
        	cloudMsg[sensorCode.length() + 2] = '\0';  // add in the string null terinator


#if SEND_EVENTS_TO_WEBPAGE
          // send notification of new sensor trip for web page
          // This can send events too fast, so it is ifdef'd until
          // we get a send queue for publishing
        	publishEvent(String(i));
#endif
        	// determine type of sensor and process accordingly
        	if(i <= MAX_PIR)    	// then the sensor is a PIR
        	{
            	processPIRSensor(i);
        	}
        	else                	// not a PIR, then a door sensor
        	{
            if (i <= MAX_DOOR)
            {
            	processDoorSensor(i);
        	  }
            else
            {
              processSensor(i);
            }
          }

          if (i == ALARM_SENSOR) {

            sparkPublish("SISAlarm", "Alarm sensor trip", 60 );

          }

           	// code to blink the D7 LED when a sensor trip is detected
        	if(blinkReady)
        	{
            	blinkReady = nbBlink(NUM_BLINKS, BLINK_TIME);
        	}

        	// update the trip time to filter for next trip
        	lastTripTime[i] = now;
      	}
	}
	else // not a code from a known sensor -- report without filtering; no entry in circular buffer
	{
    	sensorCode = "Received sensor code: ";
    	sensorCode += receivedSensorCode;
    	sensorCode += " for unknown sensor";  // note that JScript client depends upon the string "unknown"
    	Serial.println(sensorCode);  // USB print for debugging
    	sensorCode.toCharArray(cloudMsg, sensorCode.length() );  // publish to cloud

    	#ifdef DEBUG_EVENT
        	unsigned long now;
        	now = millis();
        	if((now - lastUnregisteredTripTime) > FILTER_TIME_UNREGISTERED) // filter out multiple codes
        	{
            	lastUnregisteredTripTime = now;
            	debug = "Event: Unknown code ";
            	debug += String(receivedSensorCode);
            	publishDebugRecord(debug);
        	}
    	#endif
	}

	codeAvailable = false;  // reset the code available flag if it was set
  }

  if(!blinkReady)  // keep the non blocking blink going
	{
    	blinkReady = nbBlink(NUM_BLINKS, BLINK_TIME);
	}

  #ifdef TESTRUN
  	simulateSensor();
  #endif

#ifdef photon044
  // resync Time to the cloud once per day
  if (millis() - lastTimeSync > ONE_DAY_IN_MILLIS)
  {
 	  Spark.syncTime();
	  lastTimeSync = millis();
  }
#endif

  // Testing for "person not home"
  if(lastSensorIsDoor && (personHome == HOME) && ((Time.now() - lastDoorTime) > AWAY))
  {
	personHome = NOT_HOME;

	// log "person not home" message
	logMessage(0);

  }

  // Testing for "no movement"
  if(!lastSensorIsDoor && !comatose && (personHome == HOME) && ((Time.now() - lastPIRTime) > COMATOSE))
  {
  	logMessage(2);
  	comatose = true;
  }

  #ifdef CLOUD_LOG
    publishCircularBuffer();  // pushes new events to the cloud, if needed
  #endif

}
/************************************ end of loop() ********************************************/

/************************************ toggleD7LED() ********************************************/
// toggleD7LED(): D7 LED is used as a test indicator. This function allows you to toggle it.
// Only actually toggle if DEBUG_LED is defined
//
void toggleD7LED(void)
{
  #ifdef DEBUG_LED
  digitalWrite(D7, LOW);
  delay(D7LED_DELAY);
  digitalWrite(D7, HIGH);
  delay(D7LED_DELAY);
  #endif
}

/************************************ end toggleD7LED loop() ***********************************/

/************************************ logMessage() *********************************************/
// logMessage(): function to create a log entry that is an advisory message.
//
// Arguments:
//  messageIndex:  index into the messages[] array of message strings
//
void logMessage(int messageIndex)
{
	// create timestamp substring
	String timeStamp = "";
	timeStamp += Time.now();

	// create sequence number substring
	String sequence = "";
	sequence += upcount;
	if (upcount < 9999)  // limit to 4 digits
	{
    	upcount ++;
	}
	else
	{
    	upcount = 0;
	}

	// create the log entry
	String logEntry = "A,";  // advisory type message
	logEntry += sequence;
	logEntry += ",";
	logEntry += messages[messageIndex];
	logEntry += ",";
	logEntry += timeStamp;
	logEntry += ",";

	// pad out to 20 characters
	while (logEntry.length() < 22)
	{
    	logEntry += "x";
	}

	cBufInsert("" + logEntry);

	#ifdef DEBUG_ADVISORY
    	debugLogMessage = "Advise: ";
    	debugLogMessage += String(messages[messageIndex]);
    	publishDebugRecord(debugLogMessage);
	#endif

	return;
}

/********************************** end of logMessage() ****************************************/

/************************************* logSensor() *********************************************/
// logSensor(): function to create a log entry for a sensor trip
//
// Arguments:
//  sensorIndex:  index into the sensorName[] and activeCode[] arrays of sensor data
//
void logSensor(int sensorIndex)
{
	// create timestamp substring
	String timeStamp = "";
	timeStamp += Time.now();

	// create sequence number substring
	String sequence = "";
	sequence += upcount;
	if (upcount < 9999)  // limit to 4 digits
	{
    	upcount ++;
	}
	else
	{
    	upcount = 0;
	}

	// create the sensor index substring
	String sensor = "";
	sensor += sensorIndex;

	// create the log entry
	String logEntry = "S,"; // Sensor trip log entry
	logEntry += sequence;
	logEntry += ",";
	logEntry += sensor;
	logEntry += ",";
	logEntry += timeStamp;
	logEntry += ",";

	// pad out to 20 characters
	while (logEntry.length() < 22)
	{
    	logEntry += "x";
	}

	cBufInsert("" + logEntry);

	return;
}

/*********************************** end of logSensor() ****************************************/

/********************************** processPIRSensor() *****************************************/
// processPIRSensor():  function to process a generic sensor trip.  This function creates a
//  log entry for each registered sensor trip and records the log entry in the circular buffer.
//
//  Arguments:
//  	sensorIndex: the index into the sensorName[] and activateCode[] arrays for the sensor
//       	to be logged.
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

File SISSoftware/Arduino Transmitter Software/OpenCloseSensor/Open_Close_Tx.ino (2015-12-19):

/******************************************************************************************************/
// Open_Close_Tx:  monitor a contact and send a wireless code when the contact closes and then send
//  another wireless code when the contact opens.  The wireless code is a 24 bit code word + sync
//  that is compatible with the PT2262 and EV1527 protocols.  
//  
//  A 315 MHz or 433 MHz wireless transmitter is connected to Arduino digital pin 4.  A contact
//  is connected to Arduino digital pin 8.  Arduino internal pullup is used on the contact.
//
//  This software uses blocking code.  This is OK since it monitors only one sensor (contact).
//  This software has been bebugged and tested using RC-SWITCH.  
//  Use of this software is subject to the Terms of Use, which can be found at:
//    https://github.com/SISProject/SISDocs/blob/master/Terms_of_Use_License_and_Disclaimer.pdf
//
//  This software uses code extracted from the Arduino RC-Switch library:
//    https://github.com/sui77/rc-switch
// Portions of this software that have been extracted from RC-Switch are subject to the RC-Switch
// license, as well as the the SIS Terms of Use.
//
//
//  (c) 2015 by Bob Glicksman and Jim Schrempp
/******************************************************************************************************/
// Version 001.  Has two defined constants for the contact OPEN and CLOSE events.  Change these
//  contants and recompile to suit the code needs of any given system.

/**************************************** GLOBAL CONSTANTS ********************************************/
// #define DEBUG      //uncomment to use serial port to debug
const unsigned long OPEN_CODE = 321789ul;
const unsigned long CLOSE_CODE = 5810559ul;
const int TX_PIN = 4;                  // transmitter on Digital pin 4
const int LED_PIN = 13;
const int CONTACT_PIN = 8;             // pushbutton or other contact on Digital pin 8
const int BAUD_TIME = 500;             // basic signalling unit is 400 us

/**************************************** GLOBAL VARIABLES ********************************************/
boolean contactState = false;

/******************************************** setup() *************************************************/
void setup()
{
  pinMode(TX_PIN, OUTPUT);
  pinMode(LED_PIN, OUTPUT);
  pinMode(CONTACT_PIN, INPUT);
  
  #ifdef DEBUG
    Serial.begin(9600);
  #endif
}
/***************************************** end of setup() *********************************************/

/******************************************** loop() **************************************************/
void loop()
{
  static boolean oldContactState = false;
  unsigned long codeWord;
  
  // test the contact for a valid reading and state change if a valid reading
  if ( (readContact() == true) && (oldContactState != contactState) )    // valid change reading
  {
    #ifdef DEBUG
      Serial.print("State change to: ");
    #endif
    
    // select code word to send -- open or close
    if(contactState == false)
    {
      codeWord = OPEN_CODE;
      #ifdef DEBUG
        Serial.println("OPEN");
      #endif
    }
    else
    {
      #ifdef DEBUG
        Serial.println("CLOSE");
      #endif
      codeWord = CLOSE_CODE;
    }
    
    // send the code word 20 times - 
    digitalWrite(LED_PIN, HIGH);
    for (int i = 0; i < 20; i++)
    {
      sendCodeWord(codeWord);
    }
    digitalWrite(LED_PIN, LOW);
    oldContactState = contactState;
  }
}
/***************************************** end of loop() **********************************************/

/**************************************** sendCodeWord() **********************************************/
// sendCodeWord():  sends a 24 bit code to the transmitter data pin.  The code is encoded according
//  to the EV1527 format, with a zero being one baud unit high and three baun units low, a one being
//  three baud units high and one baun unit low, and a sync being one baud unit high and 31 baud units
//  low.  The pattern is shifted out MSB first with SYNC at the end of the code word.
//
// Parameters:
//  code:  the code word to send (the 24 LSBs of an unsigned long will be sent)

void sendCodeWord(unsigned long code)
{
  const unsigned long MASK = 0x00800000ul;  // mask off all but bit 23
  const int CODE_LENGTH = 24; // a code word is 24 bits + sync
  
  // send the code word bits  
  for (int i = 0; i < CODE_LENGTH; i++)
  {
    if ( (code & MASK) == 0)
    {
      sendZero();
      #ifdef DEBUG
        Serial.print("0");
      #endif
    }
    else 
    {
      sendOne();
      #ifdef DEBUG
        Serial.print("1");
      #endif
    }      
    code = code <<1;
  }
  //send the sync
  sendSync();
  #ifdef DEBUG
    Serial.println(" SYNC");
  #endif
  
  return;
}
/************************************ end of sendCodeWord() *******************************************/

/****************************************** sendZero() ************************************************/
// sendZero:  helper function to encode a zero as one baud unit high and three baud units low.

void sendZero()
{
  // a zero is represented by one baud high and three baud low
  digitalWrite(TX_PIN, HIGH);
  delayMicroseconds(BAUD_TIME);
  for(int i = 0; i < 3; i++)
  {
      digitalWrite(TX_PIN, LOW);
      delayMicroseconds(BAUD_TIME);
  }  
  return; 
}
/************************************** end of sendZero() *********************************************/

/****************************************** sendOne() *************************************************/
// sendOne:  helper function to encode a one as three baud units high and one baud unit low.

void sendOne()
{
  // a one is represented by three baud high and one baud low
  for(int i = 0; i < 3; i++)
  {
      digitalWrite(TX_PIN, HIGH);
      delayMicroseconds(BAUD_TIME);
  } 
  digitalWrite(TX_PIN, LOW);
  delayMicroseconds(BAUD_TIME); 
  return; 
}
/*************************************** end of sendOne() *********************************************/

/***************************************** sendSync() *************************************************/
// sendSync:  helper function to encode a sync as one baud unit high and 31 baud units low.

void sendSync()
{
  // a sync is represented by one baud high and 31 baud low
  digitalWrite(TX_PIN, HIGH);
  delayMicroseconds(BAUD_TIME);
  for(int i = 0; i < 31; i++)
  {
      digitalWrite(TX_PIN, LOW);
      delayMicroseconds(BAUD_TIME);
  }  
  return; 
}
/************************************** end of sendSync() *********************************************/
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

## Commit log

2015-06-09 Version 8c
    This version of Saratoga SIS (08c) contains support for Photon and Core.
    There are patches for Particle problems with the Time and Wire
    libraries. These libraries are schedule to be fixed by Particle and
    these patches may then go obsolete.
2015-06-10 as currently deployed
2015-06-26 updates to Elm config and to make sensors > 6 generic
2015-06-27 restored some missing eol spaces to make pull request cleaner.
    [SaratogaSIS.ino]
2015-06-29 removed message about refresh attrib error and made device select again work
2015-07-18 v8.0e adds generic trip sensor slots and an SIS alarm sensor position
2015-07-19 modifies sensor defaults for 4 and 10
2015-08-16 just fixed some line starting tabs
    [SaratogaSIS.ino]
2015-08-17 Bug fix to check Spark.publish return code before decrementing g_numToPublish. v08i1
    [SaratogaSIS.ino]
2015-09-17 Preliminary Versions Posted
    Preliminary versions of the Parts List and PCB Assembly Instructions are
    posted. These need review (by Jim) prior to being finalized to the
    Master branch for release.
    [SISHubPartsList.xlsx]
2015-09-21 Update per Jim's review
    These documents are updated per Jim's review and the Parts List has been
    updated with the new, thinner box that Jim found.
    [SISHubPartsList.xlsx]
2015-10-02 08i
    v08i adds blinks in Setup; I found them useful to know progress. Also
    tested return code in login at line 1389; if log to cloud fails, don’t
    decrement g_numToPublish.
    [SaratogaSIS.ino]
2015-10-05 device select is now a drop down list
2015-10-14 Increased the Wireless Sensor Array
    This version (08j) is based upon version 08i1. It increases the maximum
    number of wireless sensors to 20, of which 0-9 are considered PIR, 10-14
    are considered Door, and 15-19 are general purpose.
2015-10-31 Preliminary SaratogaSIS09 Version
    This version supports the latest sensor configuration requirements (12
    PIRs). In limited, but preliminary testing, it seems to work fine. It
    is still lacking inverting the D7 LED state during setup().
    [SaratogaSIS.ino]
2015-11-02 Complete Version 09
    This firmware version (a) inverts the D7 LED blinks so that D7 will be
    on if something hangs up in setup(); When D7 LED is off, setup() is
    complete and loop() has been entered. (b) increases sensors to 20 and
    implements the following sensor registration scheme:
    loc 0 - 11 are PIR (interior rooms)
    loc 12 - 15 are exterior door separation sensors
    loc 16 - 18 are general purpose sensors
    loc 19 is for alarm/alert sensor
    [SaratogaSIS.ino]
2015-11-05 moved a number of elements around. made buttons visible at all times and only enabled when the can be used.
2015-11-06 added generic sensors to Big House so all spots are available to use.
2015-11-07 still v22. Current sensor display now updates after configuration of a new sensor
2015-11-07 still v22. Sensor config info is now reset when the current SIS config is cleared.
2015-11-09 v23 Now with the sensor table as the main configuratin element
2015-11-09 still v23. Removed sensor select drop down.
2015-11-09 still v23. Now tells SIS to save config whenever a device is configured or reset.
2015-11-10 still v23. changed order of Divs to put Commands above sensor table
2015-11-10 still v23. Changed sensor log output to have shorter style.
2015-11-10 still v23. When selecting a device, the sensor config is automatically retrieved and the sensor table is updated.
2015-11-10 still v23. Reworked the Add sensor pop up to have better buttons and text.
2015-11-14 v24 fixed time display to match SIS UTCOffset when displaying sensor log
2015-11-14 still v24. Sensor table codes are now initially ? and updated to -- when the retrieval is in process.
2015-11-14 SIS Hub PCB Files
    Added a directory to contain the SISHub PCB fils. The .brd and .sch
    file are age files. The others are pdf versions of these files.
    [SIS Hub.brd, SIS Hub.sch]
2015-11-19 Release version 1.00
    Updated comments and cleaned out the history. Performed a minimal
    amount of prettying up, albeit I did not fix tabbing issues in the code.
    [SaratogaSIS.ino]
2015-11-20 still v24. Fixed lookup of active device when one is selected in list; not sure why it ever worked. Also added error messages to handle case where cloud says device is online when the device is actua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
2015-11-20 still v24. restored the output that says 'end of sensor log' when the page is finished retieving them.
2015-11-21 still v26. Added Send of Sensor Buffer message when buffer holds 100 entries
2015-11-21 Posted Arduino Transmitter Code
2015-11-22 still v26. Another off by one error in retrieving sensor config.
2015-11-22 Release documents
    PDF versions of reviuewed documents for SIS release.
    [SISHubPartsList.xlsx]
2015-11-23 Corrected GitHub TOU reference
    [SaratogaSIS.ino]
2015-11-23 Updated links
    Include reference to TOU document and RC-Switch license info
2015-12-15 functionalize toggling D7 LED
2015-12-15 allow the time in for the LEDs in toggleD7LED() to be adjustable
2015-12-19 Moved SISHardware to subfolder
    [SIS Hub.brd, SIS Hub.sch]
2015-12-21 moved arduino test code into new folders
2015-12-21 moved the beacon code into setup() so that once it runs 100 iterations the device just blinks D7.
2016-01-02 reverted 88979a4 to get open_close_ix.ino back. Added TestBeacon.ino
    [Open_Close_Tx.ino]
2016-11-20 Added wireless reception tips document

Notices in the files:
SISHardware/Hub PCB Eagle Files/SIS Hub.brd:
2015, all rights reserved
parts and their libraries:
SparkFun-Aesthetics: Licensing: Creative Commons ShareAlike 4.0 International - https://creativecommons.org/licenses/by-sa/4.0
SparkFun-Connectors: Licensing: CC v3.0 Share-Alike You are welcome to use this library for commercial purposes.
